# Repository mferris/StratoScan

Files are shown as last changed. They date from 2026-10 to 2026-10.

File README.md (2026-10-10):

<p align="center">
  <picture>
    <source media="(prefers-color-scheme: dark)" srcset="assets/brand/logo-on-dark.svg">
    StratoScan
  </picture>
</p>

# StratoScan

*Formerly Radome, and before that FlightRadar.*

A live ADS-B flight radar on a round display, built on a
Raspberry Pi and a cheap SDR dongle — no subscription and no API keys. The
radar needs nothing but its own receiver and a browser; an optional iPhone
app brings it to your pocket.

StratoScan running on the physical kiosk display

<sub>Centred on RDU airport. Map: OpenFreeMap © OpenMapTiles, data © [OpenStreetMap contributors](https://www.openstreetmap.org/copyright).</sub>

## Status

*As of 2026-10-03.* One unit (RDU) runs around the clock on release
`2026.10.02.1`. The plan is in [docs/ROADMAP.md](docs/ROADMAP.md), tracked
as [issues](https://github.com/mferris/StratoScan/issues), and the parts it still
needs are in the [shopping list](docs/SHOPPING.md).

| Area | State |
|---|---|
| The radar (kiosk) | Running unattended; updates itself from signed releases. One labelled aircraft feed on the unit for every screen (`/api/aircraft`); drawing cost halved |
| Phase 4 extras | Done: rewind, notable aircraft, empty-sky screen, spoken announcements, year in review, opt-in FlightAware feeding |
| Relay (push, fleets, health) | Live on Cloudflare Workers. Fleets: groups of radars with their own administrators, who see health and visit counts, never locations |
| iPhone and iPad app | Working on a real iPhone: QR pairing, push alerts (about the radar, where you are, or both, including aircraft approaching *you*), widgets, Live Activity (also on CarPlay), home/away switching, the network's aircraft, zoom, a compass, Sky view with tracks, the logbook, weather, colour themes, radar names. Setting up a new radar from the app, one QR code to paired (simulator-tested). A no-radar mode and an iPad layout (simulator-tested) |
| Apple Watch app | Built (glance radar, complications, Smart Stack); waiting for TestFlight to reach a real Watch |
| Security review | Full scan done 2026-09-28; every finding fixed and verified on the running unit |
| Factory SD image | Builds and passes its checks in CI; not yet test-flashed or published |
| Built, rolling out to the unit | Visitor counts for the public page (counts, not tracking), fleets on the radar's setup page, setting up from the app; the kiosk's switch to the core feed |
| Cases | Retro and Kitten: heat-set insert posts, a twin antenna mount (1090 and 978 MHz, or external antennas), cleaner speaker grilles |
| Next up | Factory image test, the Watch on a real wrist, hardware v2 (light sensor, bezel), a second receiver for 978 MHz |

## What it does

Point an RTL-SDR dongle and a small antenna at the sky, and StratoScan turns
whatever ADS-B traffic it hears into a live circular radar display: bearing,
range, altitude, speed, heading, airline, aircraft type, route, and (when
available) a real photo of the airframe. It's designed to run unattended,
full-screen, on a small round touch panel — on a wall, or in the printed desk
cradle — but it's also just a web page, so it runs fine in a normal browser
too.

- **Live tracking** — polls a local [`readsb`](https://github.com/wiedehopf/readsb)
  instance every second; altitude-coded blips, smooth interpolation between
  polls, a "NO SIGNAL" banner on connection loss
- **Touch** — drag the picture anywhere; zoom with a pinch, the + and − buttons
  beside the dial, or a wheel, double-click or the + − 0 keys on a laptop,
  from about 2 nm across the dial to the whole world; the lock beside them keeps
  a view, and FOLLOW on an aircraft's details keeps it in the middle, zoomed in.
  Beyond the ring, where the antenna's picture ends, the network's aircraft
  appear round the middle of the view: adsb.lol serves 250 nm discs, so a
  wide view is a grid of up to nine of them, about 530 nm round the middle,
  asked a second apart (the radar asks, so a visitor's browser still talks
  only to the radar; the phone app does the same for itself); the map
  follows, the sweep turns about the radar wherever it is, and after 45
  seconds without a touch the view comes home by itself. The antenna's
  picture ends at its ring, and the display says so when you look past it
- **Airline & route lookup** — badges each flight with its airline and shows
  its city-pair route where one's known, including multi-stop regional
  rotations
- **Aircraft type & photo** — human-readable type names ("Bombardier Regional
  Jet CRJ-900") and a real photo when one exists, falling back to a
  representative photo of the type
- **Background map** — real terrain, roads, and runway outlines (cached once
  fetched, so a restart doesn't wait on a fresh query), darkened and centered
  on the receiver, with an always-on live weather radar overlay and an
  optional satellite lightning-strike overlay
- **Approach visualization** — a real density heatmap of your home airport,
  built from actually observed landings over time rather than a canned
  flight-path overlay — busier stretches of the corridor read as more
  visually distinct than lightly-used ones, and it keeps sharpening the
  longer the receiver runs
- **Altitude-scaled blips** — a blip grows with altitude, from 0.68x on the
  ground to 1.30x at cruise, so height reads at a glance alongside the
  existing altitude colour. Deliberately not perspective: a higher aircraft
  is further away and would be smaller if this were about distance
- **Sighting counts** — every aircraft tracks how many distinct times this
  receiver has picked it up, and how many of those came within the
  nearby-alert radius; shown as a "SEEN ×N" badge once it's more than one,
  and as fields in the detail panel always
- **Registered-owner lookup** — for aircraft confirmed private (a real
  callsign, just not an airline one), the detail panel shows who the plane
  is registered to, pulled from public aircraft-registry data
- **Nearby-aircraft alert** — auto-pops flight details (with a chime) for
  anything passing within 2 miles of the receiver
- **Lightning proximity alert** — a chime + banner when a satellite-observed
  strike is detected within 15nm of the receiver, independent of the map's
  lightning overlay toggle
- **Rare aircraft alert** — a chime and an auto-popped panel for something
  worth walking outside for: an airframe on a military/government ICAO
  address, or an unusual type (747, A380, C-17, warbirds). Once the receiver
  has met enough traffic to know what normal looks like locally, it also
  flags aircraft it has never seen before
- **Emergency squawk alert** — an unmistakable alert (distinct chime + a red
  auto-popped panel) for 7500 (hijack), 7600 (radio failure), or 7700
  (general emergency)
- **Landing/takeoff highlight** — a bright green ring around the blip and
  label of anything currently landing or departing at your home airport, plus
  an optional quiet chime
- **Volume, mute, and a choice of alert sound** — every chime above goes
  through one master gain, adjustable up to 300% (with a limiter, so louder
  never means distorted) plus mute, and can play the original synth tones or
  real CC0-licensed recordings: cat sounds for a kitten-cased unit, or a real
  airline cabin chime for anyone — see `sounds/*/CREDITS.md` for what was
  recorded and how
- **Night dimming** — the display darkens between sunset and sunrise,
  computed from the receiver's own coordinates so it tracks the seasons
  without any configuration; alerts can optionally undim it
- **Screensaver** — the panel genuinely powers off after a configurable idle
  period (see [`deploy/`](deploy/)) and wakes on touch, or on an alert if
  you've enabled that
- **Settings menu** — a gear icon opens a menu grouped into short screens
  (Alerts, Map overlays, Display, Statistics, Phone & Watch, Device setup) rather than one
  long list; every setting is one tap from the top, and the panel scrolls by
  dragging anywhere on it. Choices persist per-device
- **Configurable home airport** — 433 continental-US airports are bundled, so
  a unit can be moved or given away and re-pointed at a different field. The
  landing highlight, approach heatmap and ATC link all follow it
- **Set up entirely from the touchscreen** — WiFi (with an on-screen
  keyboard), receiver location, home airport, remote access and a factory
  reset, all without a phone or a shell. This is also the recovery path if
  the admin password is ever forgotten
- **First-run provisioning for a device you did not configure** — a unit with
  no known network raises its own `StratoScan-Setup` WiFi and displays what
  to join, what address to open and a claim code. A captive portal makes the
  setup page open automatically on a phone
- **Connectivity status** — a pill at the bottom of the display says whether
  the radar is actually working: online, on a network that is not reaching
  the internet, running its own setup WiFi, or receiving no aircraft data.
  On the device it reports what NetworkManager concludes about the
  connection; viewed remotely it falls back to whether data is still flowing
- **Restart from the screen** — a Restart row under Device setup, so a stuck
  unit does not need someone to find and pull the plug
- **Frozen-display watchdog** — the radar reports each painted frame to a
  local endpoint, and the device restarts the kiosk if the panel is powered
  on but nothing has been drawn for two and a half minutes. Chromium can
  lose its GPU context and stop painting while the page stays alive by every
  other measure, which otherwise leaves a stale radar on screen until
  somebody walks up to it. A blanked screen is not a fault: the watchdog
  checks the panel's real power state first
- **Statistics** — a Settings section that reads the accumulated flight
  history back: how many distinct aircraft have been heard and how many
  separate passes they made, how many came within two miles, and how much
  of it the antenna heard versus only saw through the network comparison.
  Broken down by operator (commercial / private / military — military
  recognised from the address block, so a military aircraft flying a
  civil-looking callsign still counts) and by airframe (heavy jets, jets,
  propeller, helicopters), using the same type database that decides each
  blip's shape. Plus all-time records — farthest contact, closest approach,
  highest, fastest — the busiest hour of the day and the busiest day of the
  week, and the most frequent visitors. The receiver scorecard lives here too
- **Network comparison** (on by default, and switchable off) — outlines the aircraft a public
  ADS-B network can see in your ring that your antenna did not hear, and
  keeps a scorecard of how you compare: overall coverage, which altitude
  bands and which bearings you are blind in, and position freshness against
  the network's. They are tracked, not just plotted: each keeps its identity
  between polls, is dead-reckoned forward from its last fix, and draws a
  dashed trail. Tap one to see what the network knows about it, clearly
  marked as reported rather than received. Measured here, the receiver was hearing 44% of the traffic
  in range, and 8 of the 9 it missed were below 4,000ft — the signature of a
  blocked horizon rather than a deaf receiver
- **Touch detail panel** — tap any aircraft for registration, squawk, vertical
  rate, and more
- **"What was that?"** — a rewind button lists the closest passes of the last
  hour and draws the chosen aircraft's track back onto the radar
- **Notable aircraft** — air ambulances, police, military and historic
  aircraft are labelled from [plane-alert-db](https://github.com/sdr-enthusiasts/plane-alert-db),
  refreshed weekly on each unit. Labels are neutral, and private owners'
  names are never shown
- **Empty-sky screen** — after 30 seconds with nothing overhead, a clock,
  the current weather and today's tally
- **Spoken announcements** (off by default) — a local
  [Piper](https://github.com/OHF-voice/piper1-gpl) voice names what is
  passing, generated on the unit with no cloud speech service
- **Year in review** — per-year counts of what the receiver heard
- **FlightAware feeding** (opt-in) — a setup-page card installs PiAware to
  share this receiver's data with FlightAware; it says plainly that the
  antenna's exact location is shared

### The iPhone app

A native SwiftUI app and widget ([`ios/`](ios/)), paired with a radar by
scanning a QR code on its screen:

- **The same radar in your pocket** — live aircraft, tap for details, and
  a label mode that keeps the map readable on a small screen
- **Alerts wherever you are** — emergency squawks, notable aircraft, low
  aircraft overhead and helicopters, pushed through the relay. Choose which
  kinds you want
- **Live Activity** (opt-in) — when the radar predicts a close pass (within
  2 miles in the next 3 minutes), a countdown appears on the lock screen and
  in the Dynamic Island, and closes itself after the pass
- **Home-screen and lock-screen widget** — how many aircraft are overhead and
  the nearest few; a radar widget for StandBy
- **Every aircraft, not just the ones the antenna hears** — the aircraft a
  public network (adsb.lol) reports are drawn half-filled with an outline,
  with a "not heard" count; one switch covers everything the network adds
- **The whole screen, anywhere** — the map fills the screen, with the radar's
  ring a line on it. Pinch from about a mile out to a continent, drag
  anywhere in the world: inside the ring the aircraft are your radar's,
  beyond it the network's around wherever you look. Away from your radar
  the view centres on you by itself. Follow an aircraft, or centre on yourself
- **Trails** — where each aircraft has been, fading with age, as on the radar
- **Airline marks** — an airline's logo beside its name on labels, in the
  details and on its alerts, so a commercial flight reads at a glance (fetched
  from the airline's own site when first seen; none ships in the app)
- **Alerts that read** — "Boeing 737-800 · Raleigh → Boston · Delta · 1,200 ft
  · 2 mi NE", the callsign last; tap one and the app opens on that aircraft
- **Compass** — turn and the needle points at an aircraft, with which way it's
  coming from and going
- **Sky view** — hold the phone up and each aircraft's label sits where it is
  in the sky; tap one for its details. Away from home it shows the
  aircraft around you (with the public network on; see [privacy](docs/privacy.md))
- **Logbook** — what your radar has seen: today, all-time totals, records
  (farthest, closest, highest, fastest), what flies over, when, and the
  regulars
- **Sky view tracks and Find in the sky** — each aircraft's path drawn
  across the sky; from any aircraft on the radar, a big arrow guides you to
  it in the camera view
- **Approaching you** (opt-in) — alerts for aircraft about to pass over
  where *you* are, not just the radar; your location is end-to-end
  encrypted to your own radar
- **Weather and themes** — rain, storms and lightning on the map, and the
  radar's four colour themes (Daylight by default)
- **iPad** — a big radar with details alongside, and a wall mode that dims
  at night
- **No radar yet?** — see live aircraft around you from the public
  adsb.lol network, or play the demo
- **Home and away** — on your WiFi the app talks to the radar directly; away
  from home it switches to the radar's public HTTPS page by itself. The away
  address is learned from the radar
- **Demo mode** — a few minutes of real traffic recorded near RDU, so the
  app can be tried without a radar

## How it works

```
[Antenna] → [RTL-SDR dongle] → [readsb] → aircraft.json (local)
[978 MHz antenna] → [second radio] → [dump978] ─┘  (US units; UAT aircraft join the same list)
                                                 │
                                                 ▼
                                   [StratoScan: fetch + render]
                                                 │
                                                 ▼
                              [Chromium kiosk, full-screen] → [round display]

 Optional, for the phone app:

 [events.py on the unit] ──signed──▶ [relay: Cloudflare Worker + D1] ──APNs──▶ [iPhone]
        (what's worth an alert)        (pairing, push, fleet health)     (alerts, Live Activity)
```

The **relay** ([`relay/`](relay/)) is the project's one server. Units send it
signed events and opt-in health reports; it pairs phones with units and holds
Apple's push key, so no unit ever carries a secret that can act for the whole
fleet; and it is the one cache through which reporting radars get the public
network's aircraft, routes and owners (see *Data sources*). The radar never
depends on it: a unit that cannot reach the relay works exactly as before.
What it stores, and for how long, is in [relay/README.md](relay/README.md).

`readsb` decodes raw ADS-B signals and writes `aircraft.json` to disk.
`index.html` is a single self-contained page — plain HTML/CSS/JS, Canvas for
the radar itself, [MapLibre GL JS](https://maplibre.org/) for the background
map — that polls that file and renders everything. No build step, no
framework, no server-side code beyond a couple of tiny same-origin proxies
(see [`deploy/`](deploy/)) for things browsers can't do directly, like
setting a custom User-Agent.

## Getting started

**Hardware and receiver setup** (Pi, RTL-SDR dongle, antenna, `readsb`
installation) is covered in [`docs/project-spec.md`](docs/project-spec.md),
including a suggested two-wave purchase plan so you can confirm reception
before buying a display.

One thing worth doing before you chase any reception problem: install
[`deploy/blacklist-rtlsdr.conf`](deploy/blacklist-rtlsdr.conf) to
`/etc/modprobe.d/`. The RTL2832U is sold as a TV tuner, so without it the
kernel's DVB-T driver claims the dongle on every plug and fights readsb for
it, producing `error -71` and constant disconnects.

**Running the web app locally**, against a receiver on your network:

```bash
python3 dev-server.py
```

Then open `http://localhost:8000/index.html`. `dev-server.py` proxies
`/tar1090/*` requests to your receiver so the page can be tested with the
exact same relative paths it uses once deployed — edit `PI_HOST` at the top
of the file to point at your own receiver. It's dev-only and isn't part of
the deployed app.

**Deploying as a kiosk**: `index.html` is a static file — copy it to your
receiver's web server docroot (same origin as `readsb`'s own web UI, to avoid
CORS). [`deploy/`](deploy/) has a systemd unit for launching Chromium in
kiosk mode on boot, plus small same-origin services: aircraft photos, the
shared approach-track store, the shared sighting-count store, the display-wake
endpoint, the optional network-comparison proxy, and (only relevant if you
expose the page to the public internet,
e.g. via Tailscale Funnel) a filtering gateway that rounds the receiver's
exact coordinates before they leave your network — see
[Security](#security) below.

**Device setup (optional)**: everything above works on a receiver you
configured yourself. If you want a unit someone *else* can set up — moved to a
new house, or given away — install the setup server:

```bash
sudo sh deploy/install-setup-server.sh
```

That adds a web setup page at `http://<device>/setup`, the same screens on the
radar's own touchscreen, and the pieces that make a device with no network
recoverable. The installer refuses to finish unless it can prove the public
gateway is refusing `/setup`, since that page accepts a WiFi password and a
Tailscale auth key.

How a fresh unit behaves:

1. It finds no known WiFi, so after ~45s it raises `StratoScan-Setup`
2. Its screen shows that network's name and password, the address to open,
   and an 8-character claim code
3. A phone joining that network gets the setup page automatically, via the
   captive portal
4. WiFi, receiver location, home airport and an admin password are set; the
   setup screen disappears

The same things can be done on the touchscreen instead, which is the only
route if the admin password is ever forgotten. **Erase everything** clears the
WiFi, the Tailscale identity, the password, the coordinates *and* the
accumulated flight history and approach heatmap — the last two are a record of
what flew over the previous owner's house — then raises the hotspot so the
next person can claim it.

Two services run as `systemctl --user` rather than system units (the
screensaver and display-wake endpoint) because they need the graphical
session's `WAYLAND_DISPLAY`. The `stratoscan-netwatchdog` service (its own two-minute loop) rolls back any
unconfirmed network change at boot and raises the hotspot when there is no
usable connection — so a mistyped WiFi password reverts itself rather than
stranding the device.

**The 4am restart, and why it is a workaround.** Chromium on this platform
leaks unlinked `/dev/shm` mappings at roughly 200–300 MB/h of daytime
rendering. Left alone it fills the 4GB tmpfs in five to twelve hours, GPU
allocations start failing with `TransferBuffer::Initialize() failed`, and the
panel freezes on a stale frame — twice in one 34-hour stretch here.
`stratoscan-kiosk-restart.timer` restarts the kiosk at 04:00, when the panel
is already blanked and the sky is empty, returning `/dev/shm` from ~2GB to
~200MB. The frozen-display watchdog in `wake-listener.py` stays as the
backstop.

A second timer, `stratoscan-shmguard`, closes the gap the daily restart
leaves: it samples every five minutes and acts on the measurement rather than
the clock. **It reloads the page before it restarts the browser.** Tearing
down the document releases a third to a half of the accumulated shared memory
(151MB → 72MB and 124MB → 79MB, measured) without killing Chromium — no black
screen, no risk of coming back windowed — and the restart is kept as the
escalation for when a reload is not enough. Two marks, because a restart is only free when nobody is
looking — at **900MB it restarts only while the panel is blanked**, so most
restarts happen invisibly, and at **1500MB it restarts regardless**, which is
the one that actually prevents the freeze. It measures both `/dev/shm` usage
and the sum of Chromium's renderer shm mappings and acts on whichever is
larger, because the two diverge: `/etc/chromium.d/dev-shm` adds
`--disable-dev-shm-usage` when `/dev/shm` has under 3.8GB free at launch, so
after one bad day Chromium moves its backing to `/tmp` and the `df` number
stops tracking the leak. Restarts are rate-limited to one per 30 minutes — if
something other than the leak fills the arena, a guard that restarts forever
is worse than the freeze it was written to prevent. The 04:00 restart runs
through the same script (with `SHMGUARD_FORCE=1`) so both share that one rate
limit.

**Chromium must not be restarted while the panel is blanked.** It comes up
windowed — tab bar, address bar, desktop wallpaper — even with `--kiosk` on
its command line, because it cannot take an output that is off and does not
retry when the output returns. Reproduced both ways on the device: panel off
gives a windowed browser every time, panel on gives fullscreen every time.
This mattered most for the 04:00 restart, which by design runs when the
screensaver has blanked the panel, so it would have left the display windowed
every morning. The guard now wakes the panel, restarts, waits for Chromium to
take the display, and only then puts the panel back as it found it.

It also **repairs a windowed browser however it happens**, not just when the
guard itself caused it — that is the failure a recipient would simply live
with. Every run it grabs the screen and measures the top-left corner:
fullscreen reads 0 on this panel, windowed reads 232, so the threshold sits
at 60 with a wide margin. Verified by breaking it deliberately and watching
the guard put it back.

**A reload cannot be delivered while the panel is blanked**, and that took
two wrong diagnoses to see. The instruction rides the paint heartbeat, and
`reportPainted()` is driven by `requestAnimationFrame` — with nothing being
composited there are no frames, so the page never posts `/wake/alive` and
never collects the flag. Six attempts told the story cleanly: five with the
panel off freed 0MB each, with the listener logging no delivery at all, while
the one with the panel on freed **597MB of 700MB**.

The apparent pattern before that — "reloads stop working above ~600MB" — was
an artifact: every failed attempt happened to be panel-off. Memory level was
never the variable.

So the guard reloads only when the panel is on (at 700MB), and when the panel
is off it restarts outright at 600MB, which is invisible precisely because
the panel is off. A restart at 1400MB remains the backstop with the panel on.

The reload is requested without any control channel of its own. The page
already POSTs `/wake/alive` every 20 seconds as the frozen-display heartbeat;
the guard drops a file in `$XDG_RUNTIME_DIR`, and the listener answers that
next heartbeat with `{"reload":1}` instead of `204`. So there is no debug
port, no key-injection helper and no new listener: only a local process
running as the kiosk user can ask for a reload. Nothing is lost by reloading —
sightings, statistics and the approach heatmap all live in the server-side
stores — beyond trails and ghost tracks, which rebuild within a sweep.

It is a workaround and not a fix, because the cause is not in this codebase:
a blank page leaks the same way, the mappings are invisible to Chromium's own
`memory-infra` accounting, and a critical memory-pressure signal reclaims
none of them. Removing the map, the weather overlays and the canvas render
loop each failed to stop it. One caveat worth keeping in view: the observed
time-to-freeze was as short as 5.2 hours, so a single daily restart is not
guaranteed to cover a long, busy day on its own.

**The enclosure**: [`enclosure/`](enclosure/) has two printable cases for the
same hardware — the original ship's-instrument look, and one shaped like a
sitting cat with the round display as its face, printed in two colours. Both are parametric OpenSCAD,
everything deriving from the measured values at the top of each file. Each
folder's README covers how to export the parts, the interference checks, and
the dimensional mistakes that are easy to repeat.

**iOS app**: `ios/` is an [XcodeGen](https://github.com/yonaskolb/XcodeGen)
project (app plus widget extension, iOS 17.2 or later). Run `xcodegen generate`
inside `ios/` if you change `project.yml`, then open `StratoScan.xcodeproj` in
Xcode. To build your own, set your signing team, bundle id and App Group in
`project.yml`. On the radar, open Settings › Phone & Watch to show a pairing
code, then scan it from the app. Push alerts need your own relay and an APNs
key (see [relay/README.md](relay/README.md)); without them the app still
shows the live radar.

**Relay**: a Cloudflare Worker on the free plan. From `relay/`:
`npm test`, then `npm run db:init && npx wrangler deploy`. Apple's `.p8` key
goes in with `wrangler secret put APNS_KEY`, never into the repo.

## Project structure

```
index.html      the whole web app — single file, no build step
dev-server.py   local-only dev proxy (not deployed)
deploy/         systemd units, same-origin services, events, pairing and the setup server
docs/           roadmap, spec, privacy policy, gifting guide, screenshots
enclosure/      parametric OpenSCAD source for the printed cases (two designs)
tests/          regression tests for the security-critical paths
vendor/         vendored MapLibre GL JS (self-hosted, no CDN dependency)
sounds/         CC0 audio for the alert sound themes (see sounds/*/CREDITS.md)
ios/            native SwiftUI app, widget and Live Activity
relay/          Cloudflare Worker: pairing, push, fleet health
scripts/        signed release script
image/          factory SD-card image build (run in CI)
```

See [CHANGELOG.md](CHANGELOG.md) for release notes and
[HANDOFF.md](HANDOFF.md) for the detailed development history.

## Data sources

StratoScan leans entirely on free, no-key-required public data, same as
[tar1090](https://github.com/wiedehopf/tar1090) (GPL-2.0-or-later; it inspired
several of these choices, but no code is shared):

- **[readsb](https://github.com/wiedehopf/readsb)** — ADS-B decoding
- **[dump978](https://github.com/flightaware/dump978)** — 978 MHz (UAT) decoding, for the FlyCatcher's second radio; its aircraft are merged into readsb's
- **[MapLibre GL JS](https://maplibre.org/)** (BSD-3-Clause, vendored under [`vendor/`](vendor/) — self-hosted, no CDN dependency) + **[OpenFreeMap](https://openfreemap.org/)** — background map tiles/style
- **[OpenStreetMap](https://www.openstreetmap.org/) via Overpass** — real runway/taxiway geometry
- **[adsb.im](https://adsb.im/)** — route (city-pair) lookups
- **[RainViewer](https://www.rainviewer.com/)** — live weather radar overlay (their API is free for personal/educational use only)
- **[planespotters.net](https://www.planespotters.net/)** — aircraft photos
- **[Wikimedia Commons](https://commons.wikimedia.org/)** — representative type photos when no tail-specific one exists, credited with author and license
- **[adsbdb.com](https://www.adsbdb.com/)** — registered-owner lookups for confirmed-private aircraft
- **[SSEC RealEarth](https://realearth.ssec.wisc.edu/)** (UW-Madison) — satellite-observed lightning strike density (GOES-East GLM)
- **[Protomaps](https://protomaps.com)** OpenStreetMap builds (© OpenStreetMap contributors, ODbL) — the per-unit offline fallback map built by [`deploy/offline-map.py`](deploy/offline-map.py)
- **[OurAirports](https://ourairports.com/data/)** (public domain) — the bundled airport table in [`deploy/airports.json`](deploy/airports.json)
- **[plane-alert-db](https://github.com/sdr-enthusiasts/plane-alert-db)** (ODbL) — the notable-aircraft list
- **[tar1090-db](https://github.com/wiedehopf/tar1090-db)** — aircraft type and registration from the ICAO address, read from the unit's own tar1090 install
- **[Open-Meteo](https://open-meteo.com/)** — current weather on the empty-sky screen (free for non-commercial use)
- **[adsb.lol](https://adsb.lol/)** — community-run ADS-B aggregation, used only by the network comparison, which can be switched off. Queried at most once every 15s no matter how many people are viewing, with coordinates rounded to ~1.1km

**One cache for every radar.** A radar that reports to the relay (health
reports on) gets the network's aircraft round its view, flight routes and
registered owners *through the relay* ([`relay/src/netcache.js`](relay/src/netcache.js)),
which asks adsb.lol, adsb.im and adsbdb once and serves every radar that
wants the same thing, so those volunteer-run services' load no longer grows
with the fleet. The aircraft come as 250 nm discs on a fixed world lattice
(two radars near each other ask for the same disc), kept ten seconds; routes
six hours; owners a week. The relay passes adsb.lol's answers through
untouched, paces its own questions, and passes a refusal on rather than
retrying. A radar whose relay is unreachable, or that has reports off, asks
the services itself as before.

Every obligation these carry, and how each is met, is in
[THIRD_PARTY_NOTICES.md](THIRD_PARTY_NOTICES.md). Please respect each
service's own terms if you build on this; RainViewer in particular is not
for commercial use.

## Security

If you expose this beyond your own LAN (e.g. a Tailscale Funnel URL, like the
live deployment this repo was built against), a few things are worth knowing
before you do:

- **The receiver's exact coordinates are not something you want publicly
  reachable.** `readsb`'s own `receiver.json` endpoint returns
  survey-precision lat/lon, and by default that's reachable by anyone who
  finds the URL. [`deploy/funnel-gateway.py`](deploy/funnel-gateway.py) sits
  in front of whatever you expose publicly and rounds those coordinates to
  ~0.7 mile precision for public traffic only — your LAN/kiosk always sees
  the exact value, which `readsb` itself needs for its own signal-range math.
  Point your public tunnel at this gateway instead of at `readsb`/lighttpd
  directly. The gateway also strips each aircraft's distance and bearing
  *from the antenna* (`r_dst`, `r_dir`) out of the public `aircraft.json`:
  with two or three aircraft positions, those fields pinpoint the receiver, which undid the rounding entirely.
- **readsb writes more than the page needs, and the rest locates the
  antenna.** `aircraft.binCraft.zst`, the binary feed tar1090 prefers,
  carries the receiver's position *unrounded* in its header — found on the
  live tunnel on 2026-10-04, next to a rounded `receiver.json` — and
  `outline.json` (the range outline, drawn around the antenna), the
  `history_*.json` files and `chunks/` are past snapshots. Under
  `/tar1090/data/`, `/tar1090/chunks/` and `/tar1090/globe_history/` the
  gateway now serves only the two files it rewrites and two counters-only
  ones, and the public `receiver.json` tells tar1090 not to ask for the rest.
  [`tests/test_funnel_gateway_tar1090.py`](tests/test_funnel_gateway_tar1090.py)
  pins it. The lesson, twice over now: anything readsb writes is a candidate
  for leaking the position, so the public rule is an allowlist, not a list
  of known offenders.
- **External data (route text, photo credits, aircraft type) is escaped
  before it touches the DOM.** Some of it — a photographer's display name on
  planespotters.net, for instance — is third-party user-submitted content
  this app doesn't control.
- **The shared same-origin stores are read-only for public traffic.**
  `deploy/approach-store.py` and `deploy/sighting-store.py` have no
  authentication of their own, which was fine while only the LAN could reach
  them. Once the page is exposed through a tunnel they become writable by
  anyone holding the URL — confirmed by injecting a fake sighting through it
  — so the gateway now refuses any non-GET to `/sightings` and `/approaches`
  from public traffic (`READ_ONLY_PUBLIC_PATHS`). Reads stay open, because
  public viewers need them; the kiosk and LAN still write normally. They also
  cap request body size and validate input shape.
- **Privileged endpoints are refused for public traffic**, and the check
  normalises the path first. `/wake` (which powers the kiosk's panel on) and
  `/setup` are listed in `LOCAL_ONLY_PATHS` in
  [`deploy/funnel-gateway.py`](deploy/funnel-gateway.py) and 404 for anything
  arriving through the tunnel. The normalising matters: an earlier version
  compared the raw path, and because lighttpd percent-decodes and collapses
  traversal before routing, `/./wake`, `/x/../wake` and `/%77ake` all reached
  the endpoint anyway. [`tests/test_funnel_gateway_paths.py`](tests/test_funnel_gateway_paths.py)
  pins the behaviour — run it after touching that filter.
- **The setup server is split across a privilege boundary.** The HTTP tier
  runs unprivileged and can only ask a small root helper
  ([`deploy/setupd.py`](deploy/setupd.py)) to perform a closed list of verbs
  over a unix socket — there is no "run nmcli" passthrough, so compromising
  the HTTP parser does not yield arbitrary root. The root helper re-validates
  every parameter rather than trusting the caller, uses no shell, and keeps
  secrets out of argv (where any local user could read them from `/proc`).
  [`tests/test_setupd_validation.py`](tests/test_setupd_validation.py) pins
  the validation table and the `/etc/default/readsb` rewriter, which is a
  root-sourced shell file and therefore a command-execution sink.
- **On-device setup deliberately needs no password**, and the endpoint behind
  it is bound to loopback and not proxied, so reaching it means already being
  on the device. That is the same physical assumption every appliance makes,
  and it has to be true: it is the only way back in for someone who has
  forgotten the admin password. The web route, which *is* reachable across
  the LAN, still requires it.
- **Erasing a unit removes the accumulated data too.** The flight history
  and approach heatmap are a record of which aircraft passed over the
  previous owner's house — and the history now carries each aircraft's
  callsign and classification alongside its counts, which makes it more
  identifying than a bare tally, not less — so a full reset clears them
  along with the credentials and coordinates. A settings-only reset keeps them, and keeps
  the network, so it is safe to run remotely.
- **The network comparison is on by default and sends only a rounded
  position.** It can be switched off in Settings, and switching it off stops
  the device contacting adsb.lol (or the relay's cache of it) at all. The
  device-side proxy makes no request of its own — it only fetches when a
  page with the setting on asks it to — and it queries with coordinates
  rounded to 2dp, the same precision the public gateway already exposes
  (the view beyond the ring, through the relay, asks for fixed world discs,
  which say even less). Asking a stranger "what is
  near me" with survey-precision coordinates would undo the rounding the
  rest of this project does deliberately. `/network` is readable publicly
  but refuses writes, so nobody holding the URL can drive traffic at a
  community-run service on this device's behalf.
- **The display-wake endpoint answers only the device itself.** lighttpd
  refuses `/wake` from anything but `127.0.0.1` and `::1`, so a LAN device
  cannot power the panel on or fake the frozen-display heartbeat.
- **SSH is key-only.** The installer drops
  [`deploy/10-stratoscan-ssh.conf`](deploy/10-stratoscan-ssh.conf) into
  `sshd_config.d`: no passwords, no root login, no X11 forwarding. It
  validates the config with `sshd -t` before reloading.
- **Downloaded code is pinned.** The Piper speech engine installs with
  `pip --require-hashes` from
  [`deploy/tts-requirements.txt`](deploy/tts-requirements.txt), and its voice
  model is checked against [`deploy/tts-voice.sha256`](deploy/tts-voice.sha256).
- **Units and phones prove who they are to the relay.** Every unit request is
  signed with the unit's own Ed25519 key, and every phone request with a key
  generated on the phone. Pairing takes a one-time code shown on the radar's
  screen, which expires in 10 minutes or after five wrong guesses. Only a
  hash of it is stored.
- **No secrets in the repository or on units.** The radar's data sources are
  free and keyless (see [Data sources](#data-sources) above). The one secret
  the project has, Apple's push key, lives only in the relay as a Cloudflare
  secret.

## License

StratoScan™ and the StratoScan logo are trademarks of Michael Ferris.
© 2026 Michael Ferris.

The code is MIT — see [LICENSE](LICENSE). The StratoScan name, logo and icons are not:
they identify the project, so a fork should use its own (see
[assets/brand/LICENSE](assets/brand/LICENSE)). Third-party components and data sources keep
their own licenses and terms; see [THIRD_PARTY_NOTICES.md](THIRD_PARTY_NOTICES.md).

## Setting one up somewhere else

The first build assumed the continental US in more places than was obvious,
and each one was a hard stop rather than a rough edge:

- **Coordinates were forced into the northern and western hemispheres.** The
  setup page and the touchscreen both "helpfully" made latitude positive and
  longitude negative, on the reasoning that a sign left off a US coordinate is
  unambiguous. It is — and it silently moved a receiver in the Netherlands
  (4.49°E) to 4.49°W, in the Atlantic, while making the entire southern
  hemisphere unreachable. `setupd` agreed, rejecting anything outside
  24–49.5°N and 66.5–125°W as "outside the continental US".
- **The airport list was 433 US airports.** Now 3,269 worldwide (large and
  medium fields with scheduled service, from OurAirports), so Schiphol and
  San Carlos are both a search away.
- **Time zone and WiFi region were baked into the image** as
  America/New_York and US, with no way to change either from setup. A unit
  abroad timestamped every sighting wrongly and ran its radio on the wrong
  channel set.
- **The lightning overlay is GOES-East**, which only sees the Americas.
  Outside that footprint every tile is a 404, so the setting now hides itself
  and says why rather than offering a toggle that cannot work.

**Location is entered as an address by default.** Nobody knows their
coordinates; everybody knows their address. The lookup runs on the *device*
rather than in the browser, because during first-time setup the phone is
joined to the device's own hotspot and has no route to the internet, while
the Pi was put on WiFi in the previous step — a browser-side lookup would
fail exactly when it is needed. The address reaches OpenStreetMap's
Nominatim and nothing else, the position it returns stays on the device, and
typing coordinates by hand remains one tap away for anyone who would rather
not send an address anywhere.

Picking the home airport sets the country, which seeds the time-zone step
with the one or two zones that country actually uses instead of all 485, and
sets the WiFi regulatory region to match. Both the phone page and the
touchscreen can complete setup on their own.

**The WiFi region only takes effect after a restart**, and both UIs say so.
Two things about `raspi-config nonint do_wifi_country` were found by running
it on the device rather than reading about it:

- **It exits non-zero on success.** Its NetworkManager and `wpa_cli` steps try
  to reach a session message bus, which does not exist when the call comes
  from a daemon, so it prints an error and returns 1 *after* writing the
  setting. Judging it by its exit code reports failure for a change that
  worked, so the result is judged by reading the value back instead.
- **The running regulatory domain does not change.** The Pi's Broadcom radio
  registers a custom regulatory table — `phy#0` reports `country 99` — so the
  driver overrides `iw reg set` and the global domain reads `98` until the
  next boot, when `cfg80211.ieee80211_regdom` on the kernel command line
  applies it for real.

The change is safe to make over WiFi: tested on a live link, the SSID, IP
address, connectivity, channel and an active SSH session were all unaffected
throughout.

Because it needs a restart, both surfaces offer one — but **only when the
region actually changed**. `set_wifi_country` reads the country before and
after and reports `changed`, so re-saving the same region never sends anyone
to power-cycle a working device. The prompt says the setting is stored, that
the radio still follows the old region until then, and that nothing else is
waiting on it, so leaving it until the next power-on is a legitimate choice
rather than an unfinished step.

## Updating a unit that has been given away

A gifted radar cannot be fixed by SSH, so it can update itself — carefully.

**Signed, or refused.** A release is accepted only if its manifest carries an
Ed25519 signature (`ssh-keygen -Y`) from the key in
`deploy/allowed_signers`, which is baked in before a unit ships. The private
half lives on the maintainer's machine and never touches a device, GitHub, or
CI. GitHub is delivery, not trust: a compromised account or token could
publish a release, it could not sign one. `ssh-keygen` rather than minisign or
gpg because it is already installed — no new dependency on a box nobody can
log into.

**Newer, or refused.** The device compares an integer serial, not a version
string. An old release stays correctly signed forever, so without this a unit
could be walked backwards onto a build whose bugs are already fixed.

**It undoes itself.** After installing, the display must paint a frame within
90 seconds or the previous files go back and the kiosk restarts again. This
reuses the heartbeat the frozen-display watchdog already depends on, so an
update that blanks the screen is caught by the thing already watching the
screen — with nobody in the room. Verified by signing and applying a build
that throws before rendering: it was staged, installed, failed to paint, and
rolled back, and the previous `index.html` came back byte-identical.

**It cannot install anywhere it likes.** Only an allowlisted set of
destinations is writable, which excludes `allowed_signers` itself — an update
must not be able to replace the key that vouches for it, or one bad release
owns the device forever.

Checking is a timer (twice a day, randomised). **Installing is a deliberate
act** from the settings screen or the setup page: a unit that silently
replaced its own software overnight would be a different thing to give
somebody. Neither surface ever claims "up to date" for a device that has
simply never looked.

The manifest carries each file's **executable bit** as well as its hash, and
only that bit — a manifest that could set arbitrary permissions on root-owned
files would be a much larger thing to sign off on than one that can say "this
is a program". It is there because the first real update installed a new
`ota.py` without its executable bit and broke its own updater; the services
survived only because their units run `python3 <script>` rather than exec'ing
it.

The paint check refuses to run at all if the heartbeat file is missing, rather
than rolling back every update. That, too, is from experience: the stamp
originally lived in `/run/stratoscan`, which is setupd's `RuntimeDirectory=`
— systemd recreates it root-owned whenever the root helper restarts, so the
kiosk user silently lost the ability to write it, and a perfectly good release
was reverted because nothing could record that the screen was painting. It now
lives in the kiosk user's own runtime directory.

To cut a release: `sh scripts/release.sh <version>`. It builds the bundle
from the commit's tree (never the working tree: a hotfix once shipped with
three unrelated changes that happened to be sitting in it), writes a manifest
of per-file hashes, signs it, **verifies its own output with the public key
the devices carry**, and only then publishes to GitHub Releases. It refuses a
dirty tree, a commit that is not on GitHub, and a serial that is not above
the last release's. `--commit <ref>` builds an older commit, which is how a
fix goes out without whatever else has landed since.

**A release reaches units in rings.** Each release carries a signed
`rollout.json` saying how far it may go: ring 0 is the maintainer's own
radar, 1 family, 2 early adopters, 3 everyone. A unit's ring is in
`/etc/stratoscan/ring` (the installer's `RING=`; a managed unit starts in
ring 1, a unit with no file is in ring 3), and the updater installs a newer
release only when the policy names it, is not paused, and covers the unit's
ring — otherwise the settings screen says the release is rolling out in
stages and has not reached this device yet. A new release starts at ring 0;
after a day on the canary, `sh scripts/release.sh rollout <version> --ring 1`
lets the next ring in (the script refuses to widen sooner unless told
`--force`), `--pause` stops the spread, and a unit that already has the
release keeps it: there is no downgrade, a fix is the next release. The
policy is signed in its own namespace, so a manifest can never pass as a
policy or a policy as a manifest, and a release with no policy reaches no
unit — a hand-made release cannot go everywhere by accident.

**Changed services are restarted.** A long-running service keeps its old code
until it restarts, and the updater originally restarted only the kiosk — so a
security fix to `funnel-gateway.py` was reported installed while the old
gateway kept running for hours. It now compares each file with the one it
replaces and restarts exactly the services whose code changed (and restarts
them again on a rollback). Like any change to `ota.py`, that behaviour starts
with the release *after* the one that installs it.

The serial is the commit count, so two releases cut from the same commit carry
the same serial and the second is refused as "not newer" — the script now
checks this against the last release before it builds anything.

## Built to run for ten years

Measured on the first unit and reviewed for a decade of unattended running at
busy sites (SFO, Schiphol) as well as quiet ones:

- **SD card wear.** The stores keep their data in memory and write at most
  every 10 minutes and on shutdown; they used to rewrite the whole file on
  every sighting (3.5 GB in 17 hours, ~100 GB/day at a busy site once full).
  Chromium's HTTP cache lives in RAM, and it keeps no shader cache on disk.
  Dirty pages are batched for two minutes before writeback. The history store evicts the aircraft
  seen *least recently*, so daily regulars survive a full store. Measured in
  steady state: 2.25 GB/day, about 8 TB over ten years, well under a 128 GB
  high-endurance card's rating.
- **Recovery without a person.** The hardware watchdog reboots a hung kernel;
  `kernel.panic=10` reboots a panicked one. `net-watchdog.py` also restarts
  `readsb` when its output goes stale and reboots after repeated failed
  restarts, and reboots when the frozen-display watchdog's browser restarts
  keep failing — never more than once every 6 hours, so a fault a reboot
  cannot fix degrades to a few reboots a day, not a loop.
- **A hung radio is power-cycled, not just rebooted.** The Pi 5 keeps USB
  power on through a reboot, so a wedged SDR stays wedged. Before rebooting,
  the watchdog cuts USB power with [uhubctl](https://github.com/mvp/uhubctl)
  for a few seconds and turns it back on (at most once every 30 minutes).
- **Security updates** via unattended-upgrades (Debian security and point
  releases, the Raspberry Pi archive, Tailscale), holding Chromium, the
  kernel and firmware — a bad unattended update to those strands a unit.
- **An offline map.** When the location is set or changed, the unit
  downloads its own area (2–7 MB) from [Protomaps](https://protomaps.com)'
  OpenStreetMap builds into `/offline-map/`, and the page falls back to it
  whenever OpenFreeMap can't be reached — so a dead tile service or a boot
  before WiFi is up shows a real map, not a blank disc.

These system-level pieces (unattended-upgrades, sysctl, unit files) are
installed by `deploy/install-setup-server.sh`, never by an update — re-run it
on any unit before it leaves the house. What remains is hardware: an RTC
battery (ML-2020, with `dtparam=rtc_bbat_vchg`) keeps the clock across power
cuts, and a high-endurance SD card or an NVMe drive is the better medium for
a decade.

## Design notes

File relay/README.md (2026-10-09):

# StratoScan relay

The one small server the project runs: a Cloudflare Worker with a D1
database. It receives **opt-in health reports** and **events** from units,
pairs phones with units by QR code, sends push alerts and Live Activities to
those phones through Apple (APNs), and shows the maintainer a fleet page. The design is
in [docs/ROADMAP.md](../docs/ROADMAP.md#architecture-the-relay).

**The radar never depends on it.** A unit that can't reach the relay, or has
reporting switched off, works exactly as before.

## What it stores

For each unit:
- its public key (which is its id);
- a name the maintainer gives it;
- first and last report times;
- its software version;
- its last ~30 days of health reports: uptime, receiver health, storage
  wear, temperature, clock battery, update state.

For each unit that sends **events** (roadmap 2.2; only once its owner
pairs a phone): the moments it decided a paired phone should hear about.
There are four kinds: emergency squawks, notable aircraft, low aircraft
overhead and helicopters. Each carries the aircraft's identity, type,
altitude, its distance from the unit rounded to half a nautical mile with
a compass direction, and its track (the direction it's travelling, which it
broadcasts itself). Events are kept for **48 hours** at most (500 per
unit), only long enough to deliver them. The fleet page shows how many
arrived, never what they were.

For **pairing** (roadmap 2.3): which phones are paired with which unit,
each phone's public key (its id) and the name it gave itself ("iPhone"),
and while a code is showing on a unit's screen, that code's SHA-256. The
code itself reaches the relay only when a phone presents it, is compared
and then discarded; it works once, and expires after 10 minutes or five
wrong guesses. A unit stops sending events when its last phone unpairs,
and the relay drops events from a unit with no phones.

For **push** (roadmap 2.1): each paired phone's APNs device token, whether
it is a development or App Store build, and which alert kinds it wants.
A token is only an address for Apple's push service. Apple tells the relay
when a token stops working, and the relay then forgets it. Each phone gets
at most 30 ordinary alerts an hour; emergencies always go through.

For **alerts about aircraft approaching a phone** (roadmap 2.7; only for
phones whose owner turns on "Approaching me"):
- each unit's X25519 "box" key, signed by the unit's own Ed25519 key;
- each such phone's latest location for each of its units, **as an opaque
  encrypted blob**. The phone seals it to that unit's box key, after
  checking the key's signature against the unit id it scanned at pairing,
  so the relay can neither read it nor substitute a key of its own. Kept 6
  hours at most, and deleted when the phone unpairs or turns the option
  off. The unit decrypts it and runs its approach prediction for that
  point; the approach event it sends back names the phone (it goes to that
  phone alone) and the aircraft, without distance or direction.

**No locations in the clear.** Reports or events carrying a latitude or
longitude field are rejected outright. No network addresses are stored either. An event
still says roughly where its unit is ("a helicopter passed within 2
miles"), which is why events are opt-in and kept so briefly.

For **the shared cache** (`src/netcache.js`, 2026-10-09): nothing per
unit. The relay keeps, in Cloudflare's per-data-centre cache, the public
network's aircraft in 250 nm discs on a fixed world lattice (10 seconds),
flight routes from adsb.im by callsign (6 hours; "no route" for 1 hour)
and registered owners from adsbdb by aircraft address (7 days). Entries
are keyed by the thing asked for, never by who asked; a reporting unit or
a paired phone may ask, and nothing else. A disc is fetched from adsb.lol
by the unit that first finds it missing (adsb.lol rate-limits Cloudflare's
shared addresses) and handed up for the others; routes and owners the
relay fetches itself.

## Fleets

A fleet is a group of radars with its own administrators (roadmap 1.13): for example, the radars one person has given to their family, or a club's radars.

**Making one** (the maintainer, on `/fleet` behind `FLEET_TOKEN`):
1. Use **Create fleet** to get an **invite code** and an **administrator link**. Each is shown **once**; the relay keeps only their SHA-256.
2. Send the invite code to radar owners. Send the link only to the administrator.
3. From the same section, **New invite code** replaces the code (the old one stops working), and **New administrator link** adds an administrator.

**Joining:** a radar's owner enters the invite code on the radar's setup page, under *Fleet*. The radar sends it, signed with its own key, to `POST /v1/unit/fleet`. It leaves with `POST /v1/unit/fleet/leave`, from the same card. A radar is in at most one fleet. Joining turns its health reports on, and leaving puts them back the way they were.

**Administrators:** opening the link sets an `HttpOnly`, `Secure`, `SameSite=Strict` cookie and redirects to `/f`, so the secret doesn't stay in the address bar. `/f` shows that fleet's radars only:
- name, software version, last report and health;
- the public page's views and visitors over the last 7 days.

It never shows a location (health reports carry none), phones or alerts. An administrator can remove a radar or replace the invite code.

**Storage:** three tables, `fleets`, `fleet_admins` and `fleet_members`, in `schema.sql`. On the live database they were created with `wrangler d1 execute --command`, because `--file` needs an API permission the maintainer's login doesn't have. An administrator's link can be replaced, by the administrator ("Replace my link" on their page) or by the maintainer: the old one stops working at once and says so when opened; `fleet_admins.replaced_hash` and `replaced` were added the same way on 2026-10-08.

## Security model

- Each unit signs every request with its own Ed25519 key, generated on the
  unit and never copied off it. No shared secret is baked into images.
- Requests are bound to their timestamp, method, path and body. The relay
  rejects anything more than 5 minutes off or replayed. Health reports may
  come at most every 10 minutes. Events are capped at 120 an hour per unit
  and 20 per request, and every field is validated and length-limited
  before it is stored.
- An unknown key registers on first contact. The number of units is capped,
  so this can't grow without bound.
- Phones sign the same way with their own Ed25519 key (CryptoKit on iOS),
  named in `X-FR-Phone`. A phone can only pair by presenting the code on a
  unit's screen, and can only unpair itself. A unit can list and remove its
  own phones.
- The fleet page requires HTTP Basic auth against the `FLEET_TOKEN` secret.
  With no secret set, the page doesn't exist at all. Its only form refuses
  cross-site posts.

## Deploy (once, by the maintainer)

```bash
cd relay
npm install
npx wrangler login                                  # opens a browser
npx wrangler d1 create stratoscan-relay             # copy the id into wrangler.toml
npm run db:init                                     # applies schema.sql
npx wrangler secret put FLEET_TOKEN                 # choose a long random password
npx wrangler secret put APNS_KEY < AuthKey_XXXX.p8  # the APNs auth key from developer.apple.com
                                                    # (key id, team id and app id go in wrangler.toml [vars])
npm run deploy                                      # serves the custom domain in wrangler.toml (and https://stratoscan-relay.<you>.workers.dev)
```

After a change to `schema.sql` (new tables only, never altered ones), run
`npm run db:init` again before `npm run deploy`. It is safe to repeat.

Then set `RELAY_URL` in `deploy/heartbeat.py` to that address and cut a
release; units that have opted in start reporting within a few minutes. The
fleet page is at `/fleet`.

The free Cloudflare plan covers this comfortably: one small request per unit
every 6 hours.

## Scale test

`node scale-test.mjs [radars] [phones per radar]` runs a simulated day for a
fleet against the real Worker code and SQL (the D1 stand-in from `test/`),
and prints requests, statements, rows and the worst status. Measured
2026-10-04: a radar with one phone sharing its location costs about 1,750
relay requests a day (1,440 of them location polls, every minute); one with
none sharing about 175. Five radars and fifteen phones: 8,835 requests and
19,205 D1 statements a day, every one answered 200. A hundred radars:
175,308 a day, which is past the Workers free plan's 100,000, so a fleet of
more than about 50 radars with phones sharing needs the $5 paid plan.

## Test

```bash
npm test
```

The tests run the Worker and its real SQL (Node's built-in SQLite behind a
D1 stand-in). They include a request signed by the Python unit client on a
real device, so the two sides can't silently drift apart.

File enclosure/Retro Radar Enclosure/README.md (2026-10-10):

# Retro radar enclosure

The 3D-printable case for the retro build, as a single parametric
OpenSCAD source. Everything is driven from the measured values at the top of
[`retro-enclosure.scad`](retro-enclosure.scad) — change those and
the rest follows.

## Parts

| part | what it is |
|---|---|
| `shell` | the body: Pi, dongle, wiring, speakers |
| `front_trim` | bezel in front of the glass, rabbeted so it seats flush |
| `retainer` | ring behind the glass; the glass rests on its front face |
| `stand` | desk cradle — two ring-arc arms on a plinth with two ridges all the way round, standing 4mm proud so the slicer supports their undersides (BambuStudio skipped the old 1mm strips and they printed rough) |
| `back_plate` | removable back — locating lip, both vent grilles, one USB-C pass-through, the antenna mount's bolt holes and cable hole |
| `antenna_mount` | bolt-on arm carrying the antenna socket (identical to the kitten's) |
| `antenna_mount_sma` | alternative mount: same flange, arm and counter-tilt, ending in a panel-mount SMA jack instead of a socket cut for one antenna's base |
| `antenna_mount_twin_8`, `antenna_mount_twin_11` | **the one to print for the FlyCatcher:** same flange and three bolts, ending in a crossbar with two SMA jacks 80 mm apart, for the 1090 and 978 MHz whips; counter-tilted so both stand vertical with their hinges straight. Two styles, for jumpers whose bulkhead body is an 8 mm hex or an 11 mm hex; two parts each, this body and the cover below (`antenna_mount_twin` is whichever `ant_twin_jack_af` names) |
| `antenna_mount_twin_cover_8`, `antenna_mount_twin_cover_11` | the 3 mm cover that closes the twin body's cable channel, on five M2 screws, with each side's frequency engraved in it (`twin_assembled` and `twin_assembled_11` show both parts on the plate, for pictures only) |
| `antenna_mount_twin_cover_8_twotone.3mf`, `antenna_mount_twin_cover_11_twotone.3mf` | the same covers with the frequencies in a second colour: one object, the cover on filament 1 and the lettering (`antenna_mount_twin_cover_text_8` / `_11`) on filament 2. Built by `make-cover-3mf.py` from binary STL exports |
| `usbc_gauge` | test coupon: five candidate USB-C cutouts, to fit the connector before printing a whole plate |

Two extra targets, `test_antenna` and `test_speaker`, clip the real shell
geometry to a small box so a fit test prints in minutes instead of hours.

## Rendering and exporting

Set `part` at the top of the file, or override it from the command line:

```bash
openscad --backend=manifold --export-format binstl \
         -D 'part="shell"' -o shell.stl retro-enclosure.scad
```

Binary STL: the shell is 75,000 facets, which is far smaller as binary than
as ascii for byte-identical geometry, and every slicer reads both.

`part="preview"` shows the whole stack assembled; `part="exploded"` separates
it.

Exporting an STL already forces a full geometry evaluation, and OpenSCAD
prints the result on stderr — check for `Status: NoError` and the
`Top level object is a 3D object (manifold)` line before printing. (Earlier
notes here said to pass `--render`; as of OpenSCAD 2026.06 that flag takes an
argument and a bare `--render` just prints the usage text, so a script using
it silently exports nothing.)

## Things that are easy to get wrong

These are all mistakes that were actually made and fixed here, kept as
warnings rather than as history:

- **`glass_thickness` is the glass sheet alone (1.62mm), not
  `panel_glass_depth`** (6.45mm, the whole panel module). The rabbet spans
  the glass; using the module depth leaves a gap you have to squeeze shut.
- **The antenna mount is counter-tilted forward by `stand_angle`.** The case
  leans back by that same angle in the cradle, so the two cancel and the
  antenna ends up vertical. Get the sign wrong and it is off by double.
- **The cradle only cups the case; the retention rails are what hold it.**
  With the bowl's axis tilted, gravity pushes the case straight down that
  axis, and nothing else opposes it.
- **Speaker brackets must be clipped to the outer cylinder.** They are flat
  slabs across a curved wall, so their corners otherwise punch through it.
- **Grille holes have to cut through the bracket as well as the wall**, or
  they dead-end in solid plastic and no sound gets out.

## The back comes off

The back used to be a fixed floor with the electronics standing on it, which
meant the only way to a Pi was through the glass. It is a separate plate now,
screwed to eight insert posts exactly as the faceplate is, and everything
that stood on the floor went with it. Undo eight screws and the tray lifts
out as one assembly.

**This plate is the same part as the kitten's.** Both cases are the same
223.34mm diameter, both use the same eight-post ring, and both lean back by
the same 18°, so one plate and one antenna mount serve both builds. That is
checked rather than asserted: exported from each design, the two meshes are
15,410 facets that compare equal as sets — the same solid, differing only in
triangle order.

**There is no fan mount.** There was a plate standing perpendicular to the
tray carrying a 30mm fan; the fan goes on the Pi instead. `fan_mount()` and
its variables are left defined but unused — the same treatment the wall-mount
keyhole code above gets — so putting it back is a one-line change. Both
grille patterns stay as plain vents.

The insert holes are drilled in `shell()`'s difference stage rather than
inside the post module. The speaker brackets reach the wall at 0° and 180°,
exactly where two of the posts stand, so a hole subtracted inside the module
gets unioned shut again by the bracket landing on top of it — two of the
eight would have printed solid. `back_inserts_open` is the check that holds
this, and it is a positive control: it has to *find* eight open bores.

### The locating lip

A rib on the plate's inner face drops into the bore, so the plate lands
centred and square and stays put while the screws go in, instead of being
juggled against eight holes at once. The outer top edge is chamfered by
1.2mm so it finds its own centre rather than catching square.

It is eight arcs, not a ring. A continuous ring at bore diameter is the
obvious shape and it is unbuildable here: the insert posts span r=102.2–111.2
and the bore wall is r=108.7–111.7, so the posts straddle the wall and a ring
would run through all eight of them. One arc per gap between posts locates
just as well — three points fix a circle and this has eight.

Three checks hold it, because a single "does the plate fit" test passes just
as happily when the lip is missing: `lip_present` (a positive control — it
must find the lip at all), `lip_clears_posts`, and `lip_inside_bore`, since a
lip larger than the bore does not locate anything, it just stops the plate
seating.

### One pass-through, not two

The USB-C power gland and the SMA antenna gland are replaced by a single
opening for a panel-mount USB-C cable. The antenna no longer needs a bulkhead
here at all — its coax comes in through the antenna mount's own cable bore,
inside the bolt circle.

**The cutout has been fitted to the real connector** (2026-09-29): it fits
the window, and its two mounting screws are 16.5mm apart. Those screws are
M3, so the holes are M3 clearance (3.4mm) like every other screw hole. The
listing publishes no cutout size, so for a different connector print
`usbc_gauge` — the cutout plus four neighbours at ±0.5 and ±1.0mm — and fit
it before committing a back plate. A coupon is minutes; a plate is hours.

### The front: trim, glass, retainer

Eight M3 × 14 screws go through the front trim's M3 clearance holes (3.4mm),
past the retainer, and into the M3 inserts in the shell's front posts.

**The retainer slips into the shell with 0.4mm to spare all round**
(`retainer_clear`). It was drawn at exactly the bore's diameter, and the
first print, PETG in an ASA shell, had to be forced in (2026-10-09). ASA
shrinks a little more than PETG, which made the zero clearance worse, but the
missing clearance was the cause. Its screw holes are **open notches** at the
rim: the screws sit where the shell's inserts are, which leaves less than a
hole's width of ring outside them, and closed holes printed as a 0.3mm
sliver. The notches also stop the ring turning. Checks: `retainer_clears_bore`,
`retainer_screws_pass`, `trim_screws_pass`.

**The connector is 37 mm lower than it first was** (2026-10-10), at `[60, -51]`, so the power jumper no longer bends against the Pi's USB ports beside the old spot; a check proves a plug there clears the stand with the case leaning back.

**The connector sits in a pocket** (2026-10-10). Its body is a 22.25 × 11 mm
boss mounted from inside; through the full 3 mm plate the socket sat 3 mm
below the outer face and a plug would not seat. The outer face now has a
2 mm pocket the boss's size (0.3 mm clearance a side), so a 1 mm web is all
that stands in front of the connector; the two screw heads sit in the pocket,
and the same M3 × 6 screws reach 2 mm further into the connector. Checks:
`usbc_recess_open`, `usbc_recess_web`.

### The plate fits one way only

The plate's locating rib is eight identical arcs between eight evenly
spaced posts, so it used to seat at any of eight positions 45° apart, and
only one of them puts the antenna mount at the top. A small block on the
shell's bore wall at 247.5° (lower left, between the posts at 225° and 270°)
now meets a matching notch in one arc of the rib: upright, the plate drops
in; turned to any other position, the block lands on the rib and the plate
stands proud before a screw goes in. It sits well clear of the antenna-mount
bosses at the top and the USB-C window, and both shells put it at the same
angle, so the one plate still fits both cases.

`key_fits` proves the upright plate meets the block with no volume, and
`key_blocks_45` … `key_blocks_315` prove each of the other seven positions
collides (43.7 mm³ each), each as its own check, because a key that blocked
only some angles would still let the plate in wrong.

### The antenna mounts on the back, and the turret is gone

The turret grew the socket out of the top of the case wall. The socket now
lives on a bolt-on arm on the removable plate, which is the same part the
kitten build uses — so both cases carry the identical antenna assembly, and
the angle can be changed without reprinting a shell.
`antenna_turret_solid()`/`antenna_turret_cuts()` are left defined but unused,
the same treatment the wall-mount keyhole code gets.

`no_turret` holds it, and its first version was wrong in an instructive way:
"nothing may stand proud of `outer_dia`" reported 13,632mm³ of turret that
was actually the decorative rivets and the cradle rails, which stand proud on
purpose out to r=115.7. The turret reached r=128, so the probe sits at 116.67
— outside the rivets, well inside a turret. `turret_probe_works` is its
paired control: the retired turret module has to be *caught* by that same
probe, or an empty result would only prove the probe was set too wide.

### The antenna mount screws into inserts

Three bosses on the plate's inner face take M3 heat-set inserts, so the mount
screws into the plate rather than needing a nut held inside the case while
the bolt is turned outside. The bores are two diameters on purpose: the
insert pocket stops on a shoulder 1mm above the plate rather than running out
through it, so the insert cannot be pressed too deep and the bolt still
passes freely from outside.

The bolt circle is clocked 30° off the vertical, which is not cosmetic. At
the obvious 0° one bolt points straight up the plate, putting its boss at
y=103 with an outer edge at 106.5 — into the locating lip, whose inner face
is at 106.3.

### The vents moved

Both grille patterns stay as plain vents, but the upper one moved from
y=+68 to y=−68. The antenna mount's flange is a 40mm disc centred at y=88 (y=81 since 2026-10-07, see below), so
at +68 the grille sat underneath it from y=68 to y=81 — venting into the back
of a solid disc. `vents_clear_of_mount` holds the new position and
`vents_were_under_mount` is its paired control, finding the 257mm³ overlap
the old position had.

### Side slots: top only, and cut through

The shell's side slots were cut all the way round. At each speaker, three of them ran across the grille. Underneath, six landed on the cradle's retention rails. None of them were vents: each cut was centred on the outer face, so it went only 2.5mm into the 3mm wall.

Now there are nine, across the top between the speakers (`exhaust_a0`..`exhaust_a1`, 30–150°), and they go right through. That gives the fan's air a way out at the top, where warm air goes anyway.

- `exhaust_top_only` checks that nothing is cut outside that arc.
- `exhaust_reaches_inside` checks that each slot breaks out past the wall's inner face. It finds about 115mm³, about 13 per slot; a blind dent finds nothing.

### Speaker grilles: one clean block each

Each speaker's grille is now only the rows in front of the ribs: five rows of 21 holes. Two things went:

- **The single row between the two ribs.** It read as a stray line of holes, not part of the grille.
- **The three rivets of the front ring that fell on each grille.** They stood up among the holes. The ring keeps its other 18.

These checks hold the change:
- `grille_in_front_of_ribs` and `rivets_clear_of_grilles` must come out empty. Both find the old geometry when run against it.
- `grille_present` and `rivets_present` are their positive controls.

## Heat-set inserts

Every screw that gets undone goes into a brass M3 heat-set insert. The holes are sized for the Kadrick M2–M5 kit: its M3 inserts are 4.5 mm across the knurl and 3.9 mm at the lead-in. Every insert hole is **4.0 mm**, so the lead-in drops in square and the knurl melts 0.25 mm a side into the plastic. (They were 4.2, which left a 4.5 mm insert only 0.15 mm of bite.)

| Where | Count | Insert | Screw | Notes |
|---|---|---|---|---|
| Front posts in the shell (front trim and retainer screw into these) | 8 | M3 × 5 | M3 × 14 | Pressed from the front, flush with the shelf the retainer sits on |
| Back posts in the shell (back plate screws into these) | 8 | M3 × 6 | M3 × 8 | Pressed from the back face, flush |
| Antenna mount flange | 3 | M3 × 5 | M3 × 8 | The pocket is in the mount; the screws come from inside the case, through the back plate |
| Twin antenna mount's cover | 5 | M2 × 3 | M2 × 6 | 3.0 mm holes in the cover seat (for a 3.2 mm knurl; 3.2 if the kit's inserts are the 3.5 mm kind — measure them). The cover's holes are counterbored 4.4 mm × 1.5 mm, so the cap heads stand only 0.5 mm proud (since 2026-10-10) |
| Speaker bosses (optional) | 8 | M2 × 3 | M2 × 6 | The 2.6 mm pilot takes the speaker's self-tapping screws; drill it to 3.0 for an M2 insert |

**The front posts are new.** They used to be only 2 mm tall: an insert sat in 2 mm of plastic with open air under it and the wall on one side only (measured: a third of the ring round it was solid). Now each post hangs 8 mm below the shelf, merged into the wall, with a 45° cone under it so it prints without support. The holes are cut after the whole shell is unioned, so the speaker brackets at 0° and 180° can't fill them.

- `front_inserts_surrounded` proves every front insert has a 1.75 mm ring of plastic all round it for its full length. Run against the old shell, it finds 545 mm³ missing.
- `front_insert_holes_open` is its positive control.

**Pressing them:** a soldering iron with an M3 insert tip, at about 220 °C for PLA or 245 °C for PETG.
1. Start the insert square in the hole.
2. Let it sink under its own weight plus light pressure. Don't push hard.
3. Stop when it is flush.
4. Hold a flat, cool piece of metal on it for a few seconds while the plastic sets, so it stays square.

### The twin mount: 1090 and 978 MHz

The FlyCatcher has two antenna inputs, 1090 and 978 MHz, and the Nooelec bundle has a hinged whip for each. `antenna_mount_twin` holds both.
- **Same base as the others:** the flange and three bolts, so nothing else changes.
- **A crossbar** with a bulkhead jack at each end, 80 mm apart. Antennas this close in frequency detune each other when bunched together.
- **Counter-tilted,** like the single mounts, so the whips stand vertical with their hinges straight. Hinges hold firmly only at their stops, and part-way they sag over time.

**Cables:** two SMA male to SMA female bulkhead jumpers, RG316, about 30 cm (SMA, not RP-SMA): a bulkhead end has a threaded barrel with a nut and washer, which is what holds the antenna. The small right-angle pigtails in the antenna bundle are MCX, for Nooelec's USB sticks, and aren't used.

**Whip or external antenna, the user's choice:** each tower's jack is an ordinary SMA socket on the outside of the case. Screw on the Nooelec whip, or the coax from an antenna mounted outside or in a window; nothing inside changes. An outdoor antenna with an N-type connector needs an N-male to SMA-male cable. Leave the FlyCatcher's bias-tee switch off unless the outdoor antenna has a powered amplifier that needs it.

**Two parts since 2026-10-07: a body and a flat cover.** The first version ran each cable through an internal tunnel and could not be assembled: both ends of a jumper are rigid metal about 9 mm across and 15–20 mm long, and that cannot turn a right-angle corner inside an 11 mm bore. The checks had only ever passed a straight probe down each leg. Now the crossbar and towers have an open channel on the side away from the case, closed by a cover on five M2 screws, so everything is laid in and nothing is threaded round a corner. The arm's bore runs straight on through the crossbar and out of the channel floor; it is 13 mm, and so is the plate's hole, because both plugs share it and the second has to pass the first cable. Under each tower's panel is a slot that is a close fit on the jack's hex body, so the jack cannot turn while its nut is tightened. The panel is 2 mm: the bulkhead's thread is 10 mm from its shoulder, and 2 of panel, 0.6 of washer and 2.5 of nut leave 4.9 mm for the whip's own coupling nut.

**The plate's cable hole grew from 11 to 13 mm the same day.** A back plate printed before that — including one printed from the y=81 plate committed earlier on 2026-10-07 — will not pass the second plug and must be reprinted.

**Two styles, by the jumper's bulkhead body.** Measure the body behind the shoulder across its flats: the jumpers on hand come as 8 mm and as 11 mm hexes, and `antenna_mount_twin_8` / `antenna_mount_twin_11` (with their covers) are cut for each — slot = flats + 0.8, a pocket the hex's size under the panel, the tower, bar and cover sized to suit. Both take the same 6.35 mm barrel. Any other size is one number: `antenna_mount_twin([9, 9])`, or a mixed pair. A round body has nothing for the slot to hold; the jack is then held with thin pliers through the open channel while its nut goes on, before the cover.

**Which side is which:** the cover carries each tower's frequency, engraved under it and read from behind the case — `1090` on the left, `978` on the right (`ant_twin_labels`; `ant_twin_label_on = false` for a plain cover). The 1090 whip is the shorter one.

**Printing:** body flange-down with tree supports (Bambu Support for ABS interface), as the other mounts print. The towers and bar have 6 mm corners and rounded edges, like the cases, rather than a box. The channel, slots, insert holes and jack holes all face up or sideways and need nothing; the towers' outboard ends and the bar's top edge start in mid-air, so the supports go on the face toward the case, where nobody sees the scars. Cover flat, counterbored face down, no support. ASA on a clean Engineering plate, no glue.

**Fitting the cables** (cover off, body held channel-up — or the flange hanging over the bench edge, since the plugs come out of its underside):
1. Push each plug end into the bore at the centre of the channel, straight down the arm and out through the flange — the second plug goes in beside the first cable with a wiggle. Leave about 10 cm of each cable beyond the bore's mouth.
2. Lay one cable along the channel to each tower. Hold the jack's hex body with the barrel pointing up its tower and slide it sideways into the open slot until it stops.
3. Push the jack up with a fingertip through the open channel: the top of the slot is a closed pocket the hex's size, and the barrel comes through the panel when the body is in it. Washer and nut on from the top, finger tight, then a quarter turn with an 8 mm (5/16") spanner — the pocket holds the jack, so nothing inside has to be held. Don't crank it; the panel is 2 mm of ASA. Check the nuts again after a week; ASA relaxes a little.
   Set each whip so its hinge folds towards or away from the wall, not towards the other whip: that's the direction the mount is weakest, so the hinge gives before the panel does, and a folded whip then clears the other tower.
4. Tidy the cables into the channel and fit the cover: five M2 × 6 into the M2 inserts.

**Lettering in a second colour.** Open the cover's `_twotone.3mf` rather than its STL. The lettering is many separate letters, and a slicer splits a multi-lump STL into one part per letter, so picking a colour for "the text" would colour one letter; the project file already has the cover on filament 1 and every letter on filament 2. Change either in the slicer. The cover prints outer face down, so the lettering is its first 0.6 mm, three 0.2 mm layers: three filament changes, nothing after. The plain STL still prints the engraved, one-colour cover.
5. Pass both plugs through the plate's 13 mm hole, bolt the flange on from inside the plate with the three M3 × 8, plug 1090 and 978 into the FlyCatcher, and screw the whips on (the 1090 whip is the shorter one). For an outdoor antenna, screw its coax onto the same barrel instead, and give the coax its own strain relief within a few centimetres of the tower.

To replace a cable: back plate off, cover off, nut off, slide the jack out of its slot, pull the plug back up through the bore. The mount stays bolted to the plate.

**Checks:**
- `twin_bore_straight`: a plug beside a cable (12 mm) passes straight down the 13 mm bore from the flange face to below the crossbar.
- `twin_slot_takes_jack`: an 8 mm-across-flats hex body stands in each slot under its panel.
- `twin_cover_fits`: the cover sits in its seat without touching the body; `twin_cover_seats` (control) finds the body when the cover is pushed 2 mm in. `twin_channel_open` and `twin_cover_screws_open` (controls) find a rod along the channel and rods through the cover's holes whole, and `twin_channel_probe_clear` and `twin_screw_probes_clear` are their complements: the same rods meet no body at all.
- `top_screw_clear_of_twin`: the plate's top screw and a hex key clear the mount.
- `twin_antennas_clear_case`: both whips, swept 220 mm up, miss the case (and the kitten's ears); `twin_antennas_probe_works` (control): the same envelopes moved 60 mm down the axis and 40 mm toward the case do hit it.
- `twin_vs_plate`, `twin_vs_stand`: no collisions with the back plate or the stand.
- `twin_panels_present`, `twin_holes_open`: positive controls; the panels are there and the jack holes are open.

## Checks

`sh run-checks.sh`. The script keeps three lists: targets that must come
out with no real volume (an interference, or a probe that should pass
through air); positive controls that must find geometry (the holes a probe
should find open, the paired "same probe, wrong place" controls such as
`vents_were_under_mount`, `top_screw_was_under_mount` and
`twin_antennas_probe_works`); and `canary`, which proves the modules are
being found at all — without it a typo in the `use <>` path makes every
other check pass against nothing.

## Smoothness

Curve resolution is set by `$fs` (0.4mm) and `$fa` (0.5°), not a fixed facet
count.

A fixed count makes the flats grow with the feature, so the biggest surfaces
come out roughest. At the old `$fn = 96` this shell's 223mm rim carried
**7.3mm flats** and the cradle 8.2mm, while every 3mm screw hole also got 96
sides it had no use for. `$fs` caps the chord — the width of one flat, which
is what the eye reads as faceting — so a big curve gets the facets and a
small hole does not.

**This is the only design here that has actually been printed**, so the small
fit-critical features keep their own explicit `$fn` and are untouched. What
changed is the geometry that had no explicit setting, plus the four wide
arcs. Measured against the previous meshes, the largest dimensional change
anywhere is **+0.064mm** on the shell's outer diameter — the flats moving
outward toward the true circle, which is the direction that matters — and
every other extent moves by 0.003mm or less. Volumes rise 0.08–0.15%. All of
that is an order of magnitude under print tolerance, so nothing about the
fit changes.

## Generated STLs

Committed alongside the source so the folder is self-contained, but they are
generated. Change the `.scad` and both must be re-exported and committed
together, or the mesh quietly stops matching the source it claims to come
from.

### The connector has to fit through, not just the cable

The bore was 9mm and the coax **connector** is 9.15mm across its widest
point, so it did not pass at all. Worse, the straight bore is cut along the
plate's normal while the socket above it is tilted by `stand_angle`, so the
two were not coaxial and the socket floor met the bore at an angle — leaving
a shoulder across the opening for the antenna's base to land on. Widening the
bore alone would not have removed that; it is a consequence of the two axes
disagreeing.

The socket floor is now opened square to the **antenna's** axis and hulled
down onto the straight run, so there is one continuous passage with no step
anywhere across it. `connector_passes` sweeps a 9.15mm plug gauge along that
path and must touch nothing; `connector_gauge_works` is its paired control,
an oversized gauge that must be caught. Swept by hand the passage clears
10.5mm and blocks at 11.0mm, so the connector has 1.35mm of margin.

Note for anyone tuning this: `-D` on the command line reaches `echo` but not
the CSG tree for these files, so a gauge sweep driven by `-D` silently
measures the file's own value at every step and reports that everything
passes. Edit the number instead.

### The antenna socket, and the lip that holds the base

The socket was Ø33 and a printed mount would not take the antenna at all: the
base is a flared cone slightly wider than that where it has to pass, so it
never got under the rim. It perched on top and tipped over — while the cable
underneath ran through perfectly, which is the part that had been checked.

Then the second printed one had its **rim snap off** while a base was being
levered under it, which says the approach was wrong and not just the number.
A 2mm chamfer left 2.5mm of wall at the edge, and a printed rim that thin,
pried outwards across its layer lines, is weak. Stiffness goes as thickness
cubed, so the barrel went 45 → 48 and the chamfer 2 → 1.2mm: 4.8mm of wall at
the edge, roughly seven times stiffer.

The deeper point is that **the base is held by depth, not by an overhang**.
The socket is 8mm deep, the antenna sits down inside it, and the chamfer is a
lead-in for a base that is already smaller than the hole — not a ramp for
forcing an oversized one past. If it has to be levered, the socket is too
small; make it bigger rather than pushing harder.

### What was actually stopping it, after three wrong guesses

The base measures **31.25mm across its flared bottom**, and **the lead leaves
the SIDE of the base 7.98mm above it** — both measured. The original socket was
Ø33, already 1.75mm of clearance, so *the bore was never what stopped it*, and
three attempts to fix the bore were fixing the wrong thing: that the base was
wider than the hole, that it was a cone flaring above a narrow bottom, that
the connector needed room beneath. None of them were true.

With the base seated, the lead is 7.98mm above the socket floor — and it
cannot go down through that floor, because the base is sitting on it. It has
to leave sideways. The printed mount gave it nowhere to go, so the connector
ended up jammed in the notch where the cable passage happens to break through
the wall, holding the base up at an angle. That notch was an accident of the
geometry; there is now a deliberate slot, 7mm wide, running from the floor up
past the rim.

It faces local +Y in the antenna's frame, which works out to world
(0, +0.309, −0.951) — down and back toward the plate — so the lead drops
straight into the passage that was already there instead of being led around
the barrel. `cable_slot_open` checks a rod at the measured exit height passes
out through the wall, and `cable_slot_other_side` is its control: the same rod
on the far side must be blocked, or "the slot is open" would be
indistinguishable from "the probe missed the mount".

`socket_takes_base` holds it, with `socket_gauge_works` as its paired control.
Its first version was wrong in a way worth recording: it ran a full-diameter
disc 12mm into the air above the mouth and failed at 283mm³, which was the
arm alongside. A 35mm cylinder held 12mm above the socket really does overlap
the arm — and means nothing, because the base is a cone that narrows and comes
in from outside. The question is whether the base fits the socket.

## Two antenna mounts, and which to print

`antenna_mount` holds the antenna itself: a 33mm socket cut around the
FlightAware desktop puck's 31.25mm base, with a slot for the lead that leaves
the side 7.98mm up. It fits that antenna beautifully and nothing else, which
makes the case choose the antenna.

`antenna_mount_sma` inverts that. Same flange, same three bolts into the same
inserts, same counter-tilt -- only the far end changes, to a panel-mount SMA
jack. Anything with an SMA plug now works: the same puck, a tuned whip
standing straight off the back, or coax running to an antenna somewhere with
a view of the sky. Swapping it is three screws; the back plate and both
shells are untouched.

Print the SMA one unless you specifically want the puck held on the case.
Measured on this hardware, an indoor puck saw **1 aircraft** while a properly
sited antenna saw **14 of the same sky at the same moment** -- so the ability
to put the antenna somewhere else is worth more than any mount that holds it
here.

The counter-tilt is the part not to touch. ADS-B is vertically polarised, and
`ant_axis_frame()` is what keeps the jack vertical while the case leans back
18 degrees in its cradle.

Four things are checked rather than assumed, and the interesting one is
`sma_passage_joins`: the cavity behind the jack has to actually meet the
cable bore, or the jack threads into a sealed pocket and the coax has nowhere
to go. That failure is invisible in preview -- both volumes are cut, the part
looks hollow, and the wall between them only exists in the print.

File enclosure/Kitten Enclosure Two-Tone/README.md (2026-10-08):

# Kitten enclosure — two-tone

The round display as a cat's face, in two colours: black stand, **white paws
with black toes**, and a **black tail with a white tip**. Ears, whisker-dot
speaker grilles, a nose on the bezel, and a stand with paws and a curled
tail.

two-tone stand

Every dimension that touches a physical part comes verbatim from the
[Retro Radar Enclosure](../Retro%20Radar%20Enclosure/), which is printed and
validated: the 203.34mm round panel, the Pi's 58×49 standoff pattern, the two
100×45mm speakers, the 30mm fan, the M3 screw ring, the USB-C and SMA
bulkheads. Only the shape is new, so the two cases are interchangeable on the
same hardware.

This began as a fork of a single-colour kitten design, which has since been
removed — the paws and tail here are about 15% larger than they were in it,
because at two colours they stop being a silhouette detail and become the
thing the eye lands on. `stand.stl` is the whole stand as one piece if you
want it in a single filament.

## Parts

The head is one colour and prints as before:

| part | colour | what it is |
|---|---|---|
| `shell` | black | the head — body cylinder plus two ears, and all the internals |
| `front_trim` | black | the face — bezel ring with a nose, whisker grooves and seven screw holes |
| `retainer` | — | ring behind the glass (identical to the retro part) |
| `back_plate` | black | removable back — locating lip, vents, one USB-C pass-through, the antenna mount's bolt holes and cable hole |
| `antenna_mount` | black | bolt-on arm carrying the antenna socket |
| `antenna_mount_sma` | alternative mount: same flange, arm and counter-tilt, ending in a panel-mount SMA jack instead of a socket cut for one antenna's base |
| `antenna_mount_twin_8`, `antenna_mount_twin_11` | **the one to print for the FlyCatcher:** same flange and three bolts, ending in a crossbar with two SMA jacks 80 mm apart, for the 1090 and 978 MHz whips; counter-tilted so both stand vertical with their hinges straight. Two styles, for jumpers whose bulkhead body is an 8 mm hex or an 11 mm hex; two parts each, this body and the cover below (`antenna_mount_twin` is whichever `ant_twin_jack_af` names) |
| `antenna_mount_twin_cover_8`, `antenna_mount_twin_cover_11` | the 3 mm cover that closes the twin body's cable channel, on five M2 screws, with each side's frequency engraved in it (`twin_assembled` and `twin_assembled_11` show both parts on the plate, for pictures only) |
| `usbc_gauge` | — | test coupon: five candidate USB-C cutouts, to fit the connector before printing a plate |

The stand is split into five bodies, one per colour region:

| part | colour | what it is |
|---|---|---|
| `stand_body` | **black** | plinth, cradle arms, keel |
| `stand_paws` | **white** | both foot pads |
| `stand_toes` | **black** | the eight toe lobes |
| `stand_claws` | **white** | eight real claws, one per toe |

`kitten-stand-twotone.3mf` is all six of the above in one project file with
the filaments already assigned — the easiest way in, and the one that avoids
the multi-lump selection problem described under *Printing it in two colours*.
| `stand_tail` | **black** | the tail from root to the white tip |
| `stand_tail_tip` | **white** | the flicked-up end |

`stand` is the whole stand as one piece, the same shape in a single
filament — useful if you are not printing in two colours, and it is also the
reference the five coloured parts are checked against.

## The back comes off, and carries the antenna

The back used to be a fixed floor with the electronics standing on it, so the
only way in was through the glass. It is a separate plate now, screwed to
eight insert posts exactly as the faceplate is.

**This plate is the same part as the retro build's**, and so is the antenna
mount. Both cases are the same 223.34mm diameter, use the same eight-post
ring, and lean back by the same 18°. That is checked rather than asserted:
exported from each design, the two back plates are 15,410 facets that compare
equal as sets — the same solid, differing only in triangle order.

A rib on the inner face drops into the bore so the plate lands centred and
square and holds itself there while the screws go in, with a 1.2mm chamfer on
its outer top edge so it finds its own centre. It is eight arcs rather than a
ring: the insert posts span r=102.2–111.2 against a bore wall at
r=108.7–111.7, so they straddle the wall and a continuous ring would run
through all eight. Three checks hold it — `lip_present` as a positive
control, `lip_clears_posts`, and `lip_inside_bore`, since a lip larger than
the bore does not locate anything, it just stops the plate seating.

The two cable glands are gone, replaced by a single opening for a panel-mount
USB-C cable; the antenna's coax comes in through the mount's own bore
instead. **The cutout has been fitted to the real
connector** (2026-09-29): it fits, its two M3 mounting screws are 16.5mm
apart, and the holes are M3 clearance. For a different connector, print
`usbc_gauge`, a coupon carrying the cutout plus four neighbours at ±0.5 and
±1.0mm, and fit it before committing a plate.

The mount screws into three M3 heat-set inserts on the plate's inner face
rather than through bare holes, so it can be removed without holding a nut
inside the case. The insert pocket stops on a shoulder 1mm above the plate so
the insert cannot be pressed too deep. The bolt circle is clocked 30° off
vertical for clearance, not looks: at 0° one boss reaches y=106.5, into the
locating lip at 106.3.

The upper vent moved from y=+68 to y=−68. The mount's flange is a 40mm disc
centred at y=88 (y=81 since 2026-10-07), so at +68 the grille sat underneath it from y=68 to y=81,
venting into the back of a solid disc — which is what prompted this.
`vents_clear_of_mount` holds the new position, and `vents_were_under_mount`
is its paired control, finding the 257mm³ overlap the old one had.

The Pi is mounted to the LCD panel, so taking the plate off exposes the back
of the Pi and its cabling rather than removing it. The four 58×49 Pi
standoffs the plate used to carry were never used and are gone (2026-10-07;
`pi_posts()` keeps their geometry). **There is no fan mount** — the fan goes on the Pi. The two grille
patterns stay as plain vents.

The antenna mounts on the back of the plate rather than on a turret, since a
turret out of a cat's skull is a spike. It is a **bolt-on**: three M3 bolts
on a 30mm circle. That keeps both parts flat and support-free on the bed, and
lets the antenna angle change later without reprinting the tray. The cable
drops out of the socket and runs straight through the arm, the flange and the
plate into the case.

The mount sits inside the head's outline and cannot be seen from the front;
only the antenna shows, rising between the ears.

### Why the arm reaches straight back before the barrel rises

The arm goes **back** from the plate, and only then does a barrel rise from
its end along the antenna's own axis. That two-stage shape is forced, not
styled. A barrel coaxial with the antenna and rooted on the plate would have
to climb toward the head the whole way and would run into it.

The first attempt avoided that by hulling a pad on the plate to a disc at the
socket — which produced a *cone* with the socket bored into its flank, so the
antenna pointed sideways and down rather than up. A stub plus a barrel gives
a real cylindrical socket with a flat face square to the antenna.

The arm is 30mm because that is what the clearance costs. Swept against the
antenna's own envelope: at 22mm it fouls the head's top rim even at nominal
diameter, at 26mm it clears nominal but not +2mm, and at 30mm it still clears
with 6mm of radial slack. `antenna_clears_head` holds it.

## The plate fits one way only

The plate's locating rib is eight identical arcs between eight evenly
spaced posts, so it used to seat at any of eight positions 45° apart, and
only one of them puts the antenna mount at the top. A small block on the
shell's bore wall at 247.5° (lower left, between the posts at 225° and 270°)
now meets a matching notch in one arc of the rib: upright, the plate drops
in; turned to any other position, the block lands on the rib and the plate
stands proud before a screw goes in. It sits well clear of the antenna-mount
bosses at the top and the USB-C window, and both shells put it at the same
angle, so the one plate still fits both cases.

`key_fits` proves the upright plate meets the block with no volume, and
`key_blocks_45` … `key_blocks_315` prove each of the other seven positions
collides (43.7 mm³ each), each as its own check, because a key that blocked
only some angles would still let the plate in wrong.

## Printing it in two colours

The five stand bodies share one coordinate frame, so they occupy their true
positions relative to each other. That gives you two routes:

**Multi-material (AMS, MMU, tool changer).** Open
`kitten-stand-twotone.3mf`. It is the whole stand as one object with the six
bodies already inside it and a filament already assigned to each — nothing to
position, nothing to select.

That file exists because loading the STLs separately does not work well, for
a reason that is not obvious. Three of the bodies are physically several
disconnected lumps: two paws, two clumps of toes, and eight separate claws,
because that is what the shapes are. Slicers split a multi-lump mesh into
separate parts on import, so picking a filament for "the claws" colours **one
claw** and leaves the other seven — which looks like the tool ignoring you.
There is no way to fix that from the STL side; eight claws cannot be one
connected lump. So the assignment lives in the project file instead.

The filament slots are 1 for the black (body, toes, tail), 2 for the white
(paws, tail tip) and 3 for the claws, kept on their own slot so they can be a
third colour. Change any of them in the slicer.

If you would rather load the STLs by hand anyway: load the first, then "add
part"/"load as part" for the rest, which preserves their positions, and
assign a filament to each.
No supports needed for the paws or toes; the tail tip lifts off the paw and
wants a little support under the flick.

**Single extruder.** Print them as separate objects and glue. Every split
follows a real seam in the shape — pad to toe, tail to tip — so the joins
land where the eye already expects a line. Print `stand_body` flat on its
base; the paws, toes and tail parts are all small and sit stably on their cut
faces.

### Why the parts overlap slightly

The bodies deliberately interfere by 0.3mm (`colour_overlap`) along every
seam, and the first version of this design got that exactly backwards.

Cutting each part with the precise shape of its neighbour is the tidy answer
and it is the broken one. It produces a perfect partition — zero shared
volume — while leaving the two bodies sharing a *surface* at identical
coordinates. No renderer can decide which of two faces at the same depth is
in front, so the slicer stipples the seam with the other colour: a white paw
arrives speckled black, worst over the buried half of the paw where the
shared area is largest.

So each part is cut with a slightly inset copy of whatever takes precedence
over it, leaving a thin shell of shared material instead of a shared surface.
Nothing is coplanar, and the colour boundary moves by at most 0.15mm — a
fifth of a nozzle width, so which body a slicer awards the shell to cannot be
seen in the print.

The tail needed the opposite treatment. Its two parts are runs of the same
tapering tube, so wherever they overlap they carry the same outer skin —
and an overlap of identical skin is the very coincidence being avoided.
There the tip is grown rather than the body shrunk, so over the shared
stretch the white tip sits 0.15mm proud of the black tail it continues.

## The whisker grooves

Three short arcs engraved into the bezel face either side of the nose.

They were briefly in the wrong place, and it is worth recording how. The
nose sits at −y, the bottom of the face; the grooves were rotated about 0°
instead — the right-hand side — so all six landed 90° from the nose they
were meant to flank. That printed before anyone noticed, as six unexplained
indentations down one side of a faceplate.

They are now placed off `nose_angle` rather than a literal, and each sweeps
away from the nose so the two sides mirror. `whisker_off_nose` in
`checks.scad` pins it: the grooves must lie entirely within a 90° wedge
centred on where `nose()` actually puts itself. That wedge is written as a
literal 270 on purpose — deriving it from `nose_angle` would make the check
vacuous, since moving the angle would move the wedge along with the grooves.

## Where the colour goes, and why

- **Paws white, toes black.** The toes are the detail that makes a paw read
  as a paw, and they are small — they need the contrast more than the pad
  does. The clefts between them grew with the toes; the groove is the only
  thing making four toes read as four rather than one lumpy pad.
- **Claws are their own body, and they are real geometry.** The grooves
  between the toes were being read as the nails; they were never that — they
  are the only thing making four toes read as four. There are now eight
  actual claws, one off the front of each toe, following that toe's splay and
  drooping toward the desk the way a cat's does. Their base sits *inside* the
  toe rather than butted against it: a spike joined at a tangent point is a
  weak spot in the print, and a butted joint would share a surface with the
  toe, which is the coincidence that stipples the preview. The tip stops
  clear of the desk on purpose — claws that reached z=0 would carry the
  stand's weight on eight little points and rock, which `claws_off_the_desk`
  holds. `claws_stand_proud` is the paired positive control: a claw entirely
  buried in its toe passes every seam and volume check while being invisible
  on the print, which is exactly what the grooves-as-nails problem looked
  like.
- **Tail black, tip white, and the tip lifts.** The first version had the tip
  resting flat on the pad, which is what a sitting cat does — but that put a
  white tip on top of a white paw, where it vanished. The whole point of a
  white tip is that it reads against what surrounds it. Lifted, it is
  silhouetted from every angle, and a flicked tail tip is cat-like anyway.
  This was caught by rendering it and looking, not by any check.

## Smoothness

Curve resolution is set by `$fs` (0.4mm) and `$fa` (0.5°) in the `.scad`,
not by a fixed facet count.

A fixed count was what this had, and it makes the flats grow with the
feature — so the biggest, most looked-at surfaces come out roughest. At the
old `$fn = 96` the head's 223mm rim carried **7.3mm flats** and the cradle
8.2mm, while every 3mm screw hole also got 96 sides it had no use for. `$fs`
caps the chord — the width of one flat, which is what the eye reads as
faceting — so a large curve gets the facets and a small hole does not. The
head is now at 0.97mm and every sphere in the paws, toes and tail at 0.4mm,
which is one extrusion width: below that a 0.4mm nozzle cannot reproduce the
difference.

The meshes are exported as **binary STL**. At this resolution the stand is
173,000 facets, which is 52MB as ascii and 8.3MB as binary for byte-identical
geometry. Every slicer reads both.

`tail_smooth_steps` is the other half of it. The tail is hulls between
consecutive spheres, so every sphere leaves a crease running around the
tube. At the old resolution those creases were masked by the general
faceting; once the circumference was smooth they read as rings. 14 points
per control segment puts a joint every 2.4mm instead of 5.6mm, for about a
megabyte.

To go finer, lower `$fs` — but check the file sizes, because sphere cost
grows as the square.

**`use <>` does not carry `$fa`/`$fs`.** It imports modules and functions
only, so `checks.scad` and the preview files set them again at the top. Miss
that and they silently render at OpenSCAD's defaults, showing a faceting the
exported mesh does not have — or, worse, validating geometry that is not what
gets printed.

## Seven screws, not eight

The bezel has seven screw holes. There is an eighth insert post in the shell
at the same angle as the nose, and the nose stands on top of it — 2.6mm of
solid capping the hole, so that screw could never have been fitted. Rather
than leave a hole that cannot take a screw and reads as a moulding defect
under the chin, it is not cut at all.

The shell keeps all eight posts. An unused boss is invisible from outside and
keeps that part identical to the retro build it was copied from.

Found by probing the screw ring after a faceplate had already been printed.
`nose_screw_removed` now proves the hole is absent, and `other_screws_present`
is its paired positive control — an empty result from the first would also be
what a probe in the wrong place produces, so a probe at a normal position has
to find a real hole for the pair to mean anything.

## Heat-set inserts

Every screw that gets undone goes into a brass M3 heat-set insert. The holes are sized for the Kadrick M2–M5 kit: its M3 inserts are 4.5 mm across the knurl and 3.9 mm at the lead-in. Every insert hole is **4.0 mm**, so the lead-in drops in square and the knurl melts 0.25 mm a side into the plastic. (They were 4.2, which left a 4.5 mm insert only 0.15 mm of bite.)

| Where | Count | Insert | Screw | Notes |
|---|---|---|---|---|
| Front posts in the shell (front trim and retainer screw into these) | 8 posts, 7 used | M3 × 5 | M3 × 14 | Pressed from the front, flush with the shelf the retainer sits on |
| Back posts in the shell (back plate screws into these) | 8 | M3 × 6 | M3 × 8 | Pressed from the back face, flush |
| Antenna mount flange | 3 | M3 × 5 | M3 × 8 | The pocket is in the mount; the screws come from inside the case, through the back plate |
| Twin antenna mount's cover | 5 | M2 × 3 | M2 × 6 | 3.0 mm holes in the cover seat (for a 3.2 mm knurl; 3.2 if the kit's inserts are the 3.5 mm kind — measure them). No counterbores: a 3 mm cover printed face-down can't roof them, so the cap heads stand 2 mm proud of a face nothing touches |
| Speaker bosses (optional) | 8 | M2 × 3 | M2 × 6 | The 2.6 mm pilot takes the speaker's self-tapping screws; drill it to 3.0 for an M2 insert |

**The front posts are new.** They used to be only 2 mm tall: an insert sat in 2 mm of plastic with open air under it and the wall on one side only (measured: a third of the ring round it was solid). Now each post hangs 8 mm below the shelf, merged into the wall, with a 45° cone under it so it prints without support. The holes are cut after the whole shell is unioned, so the speaker brackets at 0° and 180° can't fill them.

- `front_inserts_surrounded` proves every front insert has a 1.75 mm ring of plastic all round it for its full length. Run against the old shell, it finds 545 mm³ missing.
- `front_insert_holes_open` is its positive control.

The kitten's bezel has seven screws (see *Seven screws, not eight*). The post under the nose needs no insert.

**Pressing them:** a soldering iron with an M3 insert tip, at about 220 °C for PLA or 245 °C for PETG.
1. Start the insert square in the hole.
2. Let it sink under its own weight plus light pressure. Don't push hard.
3. Stop when it is flush.
4. Hold a flat, cool piece of metal on it for a few seconds while the plastic sets, so it stays square.

### The twin mount: 1090 and 978 MHz

The FlyCatcher has two antenna inputs, 1090 and 978 MHz, and the Nooelec bundle has a hinged whip for each. `antenna_mount_twin` holds both.
- **Same base as the others:** the flange and three bolts, so nothing else changes.
- **A crossbar** with a bulkhead jack at each end, 80 mm apart. Antennas this close in frequency detune each other when bunched together.
- **Counter-tilted,** like the single mounts, so the whips stand vertical with their hinges straight. Hinges hold firmly only at their stops, and part-way they sag over time.

**Cables:** two SMA male to SMA female bulkhead jumpers, RG316, about 30 cm (SMA, not RP-SMA): a bulkhead end has a threaded barrel with a nut and washer, which is what holds the antenna. The small right-angle pigtails in the antenna bundle are MCX, for Nooelec's USB sticks, and aren't used.

**Whip or external antenna, the user's choice:** each tower's jack is an ordinary SMA socket on the outside of the case. Screw on the Nooelec whip, or the coax from an antenna mounted outside or in a window; nothing inside changes. An outdoor antenna with an N-type connector needs an N-male to SMA-male cable. Leave the FlyCatcher's bias-tee switch off unless the outdoor antenna has a powered amplifier that needs it.

**Two parts since 2026-10-07: a body and a flat cover.** The first version ran each cable through an internal tunnel and could not be assembled: both ends of a jumper are rigid metal about 9 mm across and 15–20 mm long, and that cannot turn a right-angle corner inside an 11 mm bore. The checks had only ever passed a straight probe down each leg. Now the crossbar and towers have an open channel on the side away from the case, closed by a cover on five M2 screws, so everything is laid in and nothing is threaded round a corner. The arm's bore runs straight on through the crossbar and out of the channel floor; it is 13 mm, and so is the plate's hole, because both plugs share it and the second has to pass the first cable. Under each tower's panel is a slot that is a close fit on the jack's hex body, so the jack cannot turn while its nut is tightened. The panel is 2 mm: the bulkhead's thread is 10 mm from its shoulder, and 2 of panel, 0.6 of washer and 2.5 of nut leave 4.9 mm for the whip's own coupling nut.

**The plate's cable hole grew from 11 to 13 mm the same day.** A back plate printed before that — including one printed from the y=81 plate committed earlier on 2026-10-07 — will not pass the second plug and must be reprinted.

**Two styles, by the jumper's bulkhead body.** Measure the body behind the shoulder across its flats: the jumpers on hand come as 8 mm and as 11 mm hexes, and `antenna_mount_twin_8` / `antenna_mount_twin_11` (with their covers) are cut for each — slot = flats + 0.8, a pocket the hex's size under the panel, the tower, bar and cover sized to suit. Both take the same 6.35 mm barrel. Any other size is one number: `antenna_mount_twin([9, 9])`, or a mixed pair. A round body has nothing for the slot to hold; the jack is then held with thin pliers through the open channel while its nut goes on, before the cover.

**Which side is which:** the cover carries each tower's frequency, engraved under it and read from behind the case — `1090` on the left, `978` on the right (`ant_twin_labels`; `ant_twin_label_on = false` for a plain cover). The 1090 whip is the shorter one.

**Printing:** body flange-down with tree supports (Bambu Support for ABS interface), as the other mounts print. The towers and bar have 6 mm corners and rounded edges, like the cases, rather than a box. The channel, slots, insert holes and jack holes all face up or sideways and need nothing; the towers' outboard ends and the bar's top edge start in mid-air, so the supports go on the face toward the case, where nobody sees the scars. Cover flat, counterbored face down, no support. ASA on a clean Engineering plate, no glue.

**Fitting the cables** (cover off, body held channel-up — or the flange hanging over the bench edge, since the plugs come out of its underside):
1. Push each plug end into the bore at the centre of the channel, straight down the arm and out through the flange — the second plug goes in beside the first cable with a wiggle. Leave about 10 cm of each cable beyond the bore's mouth.
2. Lay one cable along the channel to each tower. Hold the jack's hex body with the barrel pointing up its tower and slide it sideways into the open slot until it stops.
3. Push the jack up with a fingertip through the open channel: the top of the slot is a closed pocket the hex's size, and the barrel comes through the panel when the body is in it. Washer and nut on from the top, finger tight, then a quarter turn with an 8 mm (5/16") spanner — the pocket holds the jack, so nothing inside has to be held. Don't crank it; the panel is 2 mm of ASA. Check the nuts again after a week; ASA relaxes a little.
   Set each whip so its hinge folds towards or away from the wall, not towards the other whip: that's the direction the mount is weakest, so the hinge gives before the panel does, and a folded whip then clears the other tower.
4. Tidy the cables into the channel and fit the cover: five M2 × 6 into the M2 inserts.
5. Pass both plugs through the plate's 13 mm hole, bolt the flange on from inside the plate with the three M3 × 8, plug 1090 and 978 into the FlyCatcher, and screw the whips on (the 1090 whip is the shorter one). For an outdoor antenna, screw its coax onto the same barrel instead, and give the coax its own strain relief within a few centimetres of the tower.

To replace a cable: back plate off, cover off, nut off, slide the jack out of its slot, pull the plug back up through the bore. The mount stays bolted to the plate.

**Checks:**
- `twin_bore_straight`: a plug beside a cable (12 mm) passes straight down the 13 mm bore from the flange face to below the crossbar.
- `twin_slot_takes_jack`: an 8 mm-across-flats hex body stands in each slot under its panel.
- `twin_cover_fits`: the cover sits in its seat without touching the body; `twin_cover_seats` (control) finds the body when the cover is pushed 2 mm in. `twin_channel_open` and `twin_cover_screws_open` (controls) find a rod along the channel and rods through the cover's holes whole, and `twin_channel_probe_clear` and `twin_screw_probes_clear` are their complements: the same rods meet no body at all.
- `top_screw_clear_of_twin`: the plate's top screw and a hex key clear the mount.
- `twin_antennas_clear_case`: both whips, swept 220 mm up, miss the case (and the kitten's ears); `twin_antennas_probe_works` (control): the same envelopes moved 60 mm down the axis and 40 mm toward the case do hit it.
- `twin_vs_plate`, `twin_vs_stand`: no collisions with the back plate or the stand.
- `twin_panels_present`, `twin_holes_open`: positive controls; the panels are there and the jack holes are open.

## Checks

`sh run-checks.sh` runs every target in `checks.scad` and reports the
**volume** each produces.

Volume, not facet count. A boolean between parts that touch leaves
zero-thickness films along the boundary — thousands of facets and no volume —
so counting facets calls a correct model broken. The threshold is 1mm³
against a paw of roughly 27,000mm³, and a real interference has nowhere to
hide in that gap.

Volume alone is not enough either, which is what the speckled first version
proved: a shared surface has no volume at all. That is what
`check-coincident.py` below is for.

Alongside the fit checks on the head and cradle, the colour split adds:

- `material_lost` — must be **zero**: a region of the one-piece stand that no
  coloured part claims. That would print as a hole.
- `material_gained`, `paws_vs_toes`, `body_vs_paws`, `tail_vs_tip` — must be
  **small but non-zero**: these are the colour seams, and zero here means the
  parts share surfaces instead of overlapping, which is the speckling bug.
  Bounded at 1500mm³, which is 0.15mm of thickness over 10,000mm² of shared
  surface — far more than these parts have.
- `canary` — must produce geometry. Without it, a typo in the `use <>` path
  makes every check above pass against nothing, which has happened here
  before.

`check-coincident.py` makes the check the volume tests cannot: it compares
the exported meshes face by face and counts triangles two parts have at
identical coordinates. Two parts sharing a surface have zero shared volume
and still stipple, so nothing about that bug is visible in a volume
measurement. All ten pairs must come out at zero. With the overlap disabled
(`-D colour_overlap=0`) the same check reports 3,502 shared faces between the
paws and the toes, which is precisely the speckling.

Run everything with `sh run-checks.sh`, which also runs the coincidence
check.

## Regenerating

```sh
for p in shell front_trim retainer stand back_plate usbc_gauge \
           antenna_mount antenna_mount_sma antenna_mount_twin_8 antenna_mount_twin_11 \
           antenna_mount_twin_cover_8 antenna_mount_twin_cover_11 \
           stand_body stand_paws stand_toes stand_claws stand_tail stand_tail_tip; do
  openscad --backend=manifold --export-format binstl \
           -D "part=\"$p\"" -o "$p.stl" kitten-enclosure-twotone.scad
done
```

**The exporter is not deterministic.** Two consecutive exports of unchanged
source differ — 135 facets out of 210,448 on the stand, and even the facet
count moves (210,758 vs 210,448 across runs). It shows up on the stand and
not on the simple parts, which is consistent with it coming from the hundreds
of hulls the paws and tail are built from. Two consequences: re-exporting
everything makes the stand files show as modified whether or not anything
changed, so only re-export what actually changed; and comparing two STLs byte
for byte is not a test of whether they are the same shape — compare the
triangle sets instead.

The `.stl` files are committed alongside the source so the folder is
self-contained, but they are generated. Change the `.scad` and both must be
re-exported and committed together, or the mesh quietly stops matching the
source it claims to come from.

### The connector has to fit through, not just the cable

The bore was 9mm and the coax **connector** is 9.15mm across its widest
point, so it did not pass at all. Worse, the straight bore is cut along the
plate's normal while the socket above it is tilted by `stand_angle`, so the
two were not coaxial and the socket floor met the bore at an angle — leaving
a shoulder across the opening for the antenna's base to land on. Widening the
bore alone would not have removed that; it is a consequence of the two axes
disagreeing.

The socket floor is now opened square to the **antenna's** axis and hulled
down onto the straight run, so there is one continuous passage with no step
anywhere across it. `connector_passes` sweeps a 9.15mm plug gauge along that
path and must touch nothing; `connector_gauge_works` is its paired control,
an oversized gauge that must be caught. Swept by hand the passage clears
10.5mm and blocks at 11.0mm, so the connector has 1.35mm of margin.

Note for anyone tuning this: `-D` on the command line reaches `echo` but not
the CSG tree for these files, so a gauge sweep driven by `-D` silently
measures the file's own value at every step and reports that everything
passes. Edit the number instead.

### The antenna socket, and the lip that holds the base

The socket was Ø33 and a printed mount would not take the antenna at all: the
base is a flared cone slightly wider than that where it has to pass, so it
never got under the rim. It perched on top and tipped over — while the cable
underneath ran through perfectly, which is the part that had been checked.

Then the second printed one had its **rim snap off** while a base was being
levered under it, which says the approach was wrong and not just the number.
A 2mm chamfer left 2.5mm of wall at the edge, and a printed rim that thin,
pried outwards across its layer lines, is weak. Stiffness goes as thickness
cubed, so the barrel went 45 → 48 and the chamfer 2 → 1.2mm: 4.8mm of wall at
the edge, roughly seven times stiffer.

The deeper point is that **the base is held by depth, not by an overhang**.
The socket is 8mm deep, the antenna sits down inside it, and the chamfer is a
lead-in for a base that is already smaller than the hole — not a ramp for
forcing an oversized one past. If it has to be levered, the socket is too
small; make it bigger rather than pushing harder.

### What was actually stopping it, after three wrong guesses

The base measures **31.25mm across its flared bottom**, and **the lead leaves
the SIDE of the base 7.98mm above it** — both measured. The original socket was
Ø33, already 1.75mm of clearance, so *the bore was never what stopped it*, and
three attempts to fix the bore were fixing the wrong thing: that the base was
wider than the hole, that it was a cone flaring above a narrow bottom, that
the connector needed room beneath. None of them were true.

With the base seated, the lead is 7.98mm above the socket floor — and it
cannot go down through that floor, because the base is sitting on it. It has
to leave sideways. The printed mount gave it nowhere to go, so the connector
ended up jammed in the notch where the cable passage happens to break through
the wall, holding the base up at an angle. That notch was an accident of the
geometry; there is now a deliberate slot, 7mm wide, running from the floor up
past the rim.

It faces local +Y in the antenna's frame, which works out to world
(0, +0.309, −0.951) — down and back toward the plate — so the lead drops
straight into the passage that was already there instead of being led around
the barrel. `cable_slot_open` checks a rod at the measured exit height passes
out through the wall, and `cable_slot_other_side` is its control: the same rod
on the far side must be blocked, or "the slot is open" would be
indistinguishable from "the probe missed the mount".

`socket_takes_base` holds it, with `socket_gauge_works` as its paired control.
Its first version was wrong in a way worth recording: it ran a full-diameter
disc 12mm into the air above the mouth and failed at 283mm³, which was the
arm alongside. A 35mm cylinder held 12mm above the socket really does overlap
the arm — and means nothing, because the base is a cone that narrows and comes
in from outside. The question is whether the base fits the socket.

## Two antenna mounts, and which to print

`antenna_mount` holds the antenna itself: a 33mm socket cut around the
FlightAware desktop puck's 31.25mm base, with a slot for the lead that leaves
the side 7.98mm up. It fits that antenna beautifully and nothing else, which
makes the case choose the antenna.

`antenna_mount_sma` inverts that. Same flange, same three bolts into the same
inserts, same counter-tilt -- only the far end changes, to a panel-mount SMA
jack. Anything with an SMA plug now works: the same puck, a tuned whip
standing straight off the back, or coax running to an antenna somewhere with
a view of the sky. Swapping it is three screws; the back plate and both
shells are untouched.

Print the SMA one unless you specifically want the puck held on the case.
Measured on this hardware, an indoor puck saw **1 aircraft** while a properly
sited antenna saw **14 of the same sky at the same moment** -- so the ability
to put the antenna somewhere else is worth more than any mount that holds it
here.

The counter-tilt is the part not to touch. ADS-B is vertically polarised, and
`ant_axis_frame()` is what keeps the jack vertical while the case leans back
18 degrees in its cradle.

Four things are checked rather than assumed, and the interesting one is
`sma_passage_joins`: the cavity behind the jack has to actually meet the
cable bore, or the jack threads into a sealed pocket and the coax has nowhere
to go. That failure is invisible in preview -- both volumes are cut, the part
looks hollow, and the wall between them only exists in the print.

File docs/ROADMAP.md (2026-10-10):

# Roadmap: the five phases

**Baseline:** [v2.0.0](https://github.com/mferris/StratoScan/releases/tag/v2.0.0),
identical to OTA release `2026.09.27.15`. It is the revert point for
everything below.

Progress is tracked as GitHub
[milestones](https://github.com/mferris/StratoScan/milestones) and
[issues](https://github.com/mferris/StratoScan/issues). This file holds
the design decisions those issues depend on.

## Ground rules

- **Open source, license-clean.** Nothing is added without checking its
  license and terms first, and recording it in
  [THIRD_PARTY_NOTICES.md](../THIRD_PARTY_NOTICES.md). Anything
  non-commercial-only (such as RainViewer) is labelled as such.
- **The radar never depends on a cloud service.** The relay (below) adds
  push and fleet health. A unit that can't reach it keeps working exactly
  as it does today.
- **Privacy by default.** The exact home location never leaves the device.
  Anything sent off-device is opt-in, minimal and rounded.
- **No secrets on units.** Gifted units are in other people's houses. Keys
  that can act for the whole fleet (such as Apple's push key) live only in
  the relay.
- **Every fix is verified on the running device**, not just installed.

## What to buy

The parts each item needs are in [SHOPPING.md](SHOPPING.md).

## Architecture: the relay

One small **Cloudflare Worker** (`relay/`) with a D1 database. It is the
only server the project runs.

```
unit ──(signed heartbeat, events)──▶ relay ──(APNs)──▶ iPhone / Watch
unit ◀────(nothing: units only ever call out)──────────┘
phone ──(pairing, notification rules)──▶ relay
```

- **Unit identity:** each unit generates an Ed25519 keypair at install, and
  signs every request with it. The relay stores public keys only. Nothing
  shared or fleet-wide is baked into images.
- **Pairing:** the unit's screen shows a QR code with its ID plus a
  one-time pairing secret (valid 10 minutes). The phone scans it, and the
  relay links that phone's push token to the unit.
- **Heartbeat (opt-in):** every 6 h the unit sends its version, uptime,
  receiver health, SD wear estimate and last-error class. **No location.**
  A fleet page shows the maintainer every unit's health.
- **Events:** the unit decides locally what matters (notable aircraft,
  emergency squawk, low overhead…) and posts a small event. The relay fans
  it out to paired devices over APNs. Payloads carry aircraft data only,
  never the home location: identity, type, altitude, and distance rounded
  to half a nautical mile with a compass direction. That still hints where
  a unit is, so events are off until the owner pairs a phone, and the relay
  keeps them only 48 hours. A factory reset turns them off.
- **Failure mode:** if the relay is down, units keep a short queue, drop it
  on overflow, and the radar is unaffected.

## Phase 1: reliability you can see

| # | Item | Done when |
|---|---|---|
| 1.1 | RTC battery support: installer sets `dtparam=rtc_bbat_vchg` when a rechargeable cell is fitted; clock health in status | A unit keeps correct time across a power cut with no network |
| 1.2 | Storage off the SD card: NVMe boot via the Pi 5 M.2 HAT+ (or CM5 eMMC). Migration script, enclosure fit, installer checks | A unit boots and runs from NVMe; the enclosure fits |
| 1.3 | Relay foundation: Worker, D1 schema, signed-request auth, heartbeat endpoint, fleet status page | Deployed; tests pass; RDU's heartbeat shows on the fleet page |
| 1.4 | Unit side: keypair generation, opt-in heartbeat (setup toggle), sent every 6 h | RDU reports; turning it off stops it |
| 1.5 | Factory image: pi-gen build in GitHub Actions (Arm runner); first boot runs the installer; GPL source offer for readsb/tar1090 included | A fresh SD flashed from the release boots to the setup hotspot |
| 1.6 | Re-measure SD writes after the storage fixes (scheduled 2026-09-28) | Result recorded; any remaining large writer fixed |
| 1.7 | Recover a hung radio without a human: the watchdog power-cycles USB (uhubctl) before it reboots, since a Pi 5 reboot keeps USB powered | A hung SDR comes back on its own on a real unit |
| 1.8 | Core feed on the device: one service merges the antenna's and the network's aircraft, labels them once (operator, type, route, owner, notable), caches the lookups, and serves `/api/aircraft` to every screen; no antenna-relative fields | Live on RDU; labels match the kiosk's on a recorded sample |
| 1.9 | Kiosk and public page read the core feed; route and owner lookups move off visitors' browsers onto the unit | Same picture as before; public visitors no longer contact adsb.im or adsbdb |
| 1.10 | ~~`events.py` reads the core feed;~~ the copied classification tables are deleted. **Done 2026-09-30:** the tables are shared from `labels.py`; `events.py` stays on readsb's `aircraft.json` on purpose (it needs the antenna-relative fields, and alerts shouldn't depend on the core feed) | Same alerts from the same fixtures, with no tables of its own |
| 1.11 | Cut the radar's drawing cost: static layers drawn once, the sweep rotated by the compositor, only moving things redrawn | Measured on RDU: the GPU process well under half its current ~94% of a core, and cooler |
| 1.12 | Visitor counts for each radar's public page, for its owner: views, unique visitors (a daily-salted hash, never stored), the owner's app counted apart, hour of day, device type, referring site; no cookies, no stored addresses; on the radar's screen, setup page and app (#50) | Visits from a phone on mobile data show within a minute; nothing stored holds an address |
| 1.13 | Fleets with their own administrators on the relay: radars join by their owner's invite code and can leave any time; administrators see health and visit counts per radar and in total, never locations, phones or alerts; per-administrator sign-in (#51) | The family fleet with RDU in it; a second fleet sees none of it |
| 1.14 | Security review follow-ups (2026-10-04): an events-service user, per-address login throttling, rotating administrator links, a quieter watchdog, a CSP, gift-unit firewall rules, socket timeouts, a narrow sudo rule, TLS for the setup page | 1–4 shipped; the rest before the first sale |

| 1.15 | Before the first sale: the services whose free terms are personal or non-commercial move to paid or commercial terms, or out (#62) | Every service a sold unit touches is used within its terms |
| 1.16 | Staged releases: a release reaches units in rings (the maintainer's own, family, early adopters, everyone), carries a signed rollout policy, can be paused, soaks a day on the canary before it widens; a release is built from a commit, never the working tree (#63) | A release held at ring 0 reaches RDU and no other unit; widening lets the next ring in |
| 1.17 | One cache for every radar: the network's aircraft (adsb.lol, on fixed 250 nm world discs so radars near each other share one fetch), routes (adsb.im) and owners (adsbdb) through the relay, for units that report and paired phones; a radar falls back to asking the services itself (#64) | Two radars looking at the same sky cost adsb.lol one fetch; a route asked by one radar costs nothing when another asks |
| 1.18 | Enrolment and quotas on the relay in place of the fixed unit cap: a radar joins only through an enrolment the maintainer controls, can be revoked, and has its share of events, pushes and the cache (#65) | The fixed cap gone; RDU enrolled without being touched |
| 1.19 | The relay at hundreds of radars: D1 read replicas, release files on R2, self-hosted map tiles, each at its trigger (#66) | Each done at its trigger, or deferred with a note |
| 1.20 | Fewer questions per radar: the ring comparison every 60 s or by feeding adsb.lol, the location poll only while a phone shares, a slower away poll in the app (#67) | Requests per day measured on RDU before and after |
## Phase 2: the pocket

| # | Item | Done when |
|---|---|---|
| 2.1 | Relay push: APNs token auth, fan-out, per-phone rules, rate limits | A test event reaches a real iPhone |
| 2.2 | Unit events: notable / emergency / low overhead / helicopter, decided on the unit and queued to the relay | Events arrive for real traffic at RDU |
| 2.3 | QR pairing on the device screen, and in the app | Pair and unpair with a phone, end to end |
| 2.4 | iOS app v2: notification rules, home and lock-screen widgets, Live Activity (inbound overhead), StandBy radar | Each feature working on a real phone |
| 2.5 | iOS app v2: away mode (community feed when not home), logbook/collection, AR sky view fed by the unit | Each feature working on a real phone |
| 2.7 | Location-aware app: a "You" marker relative to the antenna and a centre-on-me map; opt-in alerts for aircraft approaching the phone, its location end-to-end encrypted to the paired radar, which runs the prediction | Alerts for aircraft near the phone arrive on a real iPhone away from home, within the radar's coverage |
| 2.8 | App shows the network's aircraft too (the kiosk's "not heard" ghosts from `/network`), marked distinctly, with matching counts and the ODbL credit; setting to turn off | The app and the kiosk show the same sky on a real iPhone |
| 2.9 | Zoom in the app: pinch from 20 nm to about 1 nm, centred on the radar, the phone, or a followed aircraft; optionally the same on the kiosk, returning to full view by itself | A real aircraft sits on the right street at full zoom on a real iPhone |
| 2.10 | Logo and app icon: a round radar-sweep mark with a nod to altitude, legible at 16 px and in one colour; app icon (with dark and tinted variants), favicons, README header, repo social preview; logo files under their own notice, not MIT | Claude | The icon on a real iPhone home screen, and favicons everywhere the project shows its face |
| 2.11 | iPad app: a big radar with details, logbook and settings in a side panel; landscape and portrait; optional full-screen wall mode | On a real iPad, both orientations, nothing changed on the iPhone |
| 2.12 | Sky view tracks: a fading line where each aircraft has been and a dotted one where it's going, projected across the sky like the labels | Outdoors on a real iPhone, the lines follow the aircraft's real path |
| 2.13 | The app without a radar: live aircraft around the phone from adsb.lol (opt-in, rounded location), radar view and Sky view; alerts and the logbook stay radar-only | On a real iPhone with no radar: real aircraft around you; pairing later switches cleanly |
| 2.14 | Weather in the app: the kiosk's precipitation radar (RainViewer) and lightning (RealEarth) on the iPhone and iPad map, with the same switches | On a real iPhone, rain shows where the kiosk shows it |
| 2.15 | The kiosk's four colour themes in the app, Daylight by default (the kiosk's default too, from 2026-10-01), and a lighter map | Each theme matches the kiosk on a real iPhone; new installs open in Daylight |
| 2.16 | Alerts about where I am, the radar, or both: low overhead, helicopter and notable alerts measured from the phone's (encrypted) location as well as the antenna, by the owner's choice; within the radar's reach first | Away from home, a helicopter near the phone alerts "near you"; one over the house doesn't |
| 2.17 | Radar names: set during setup (default from the place), shown on the radar and carried to phones by the pairing link; a rename on the radar reaches phones that haven't named it themselves | A new radar pairs and shows its own name on the phone |
| 2.18 | Set up a new radar from the app: one QR code on the first-boot screen, the app joins the setup hotspot, sends home WiFi, the phone's location, time zone and name, and pairs in the same session; the browser and on-screen setup stay | A radar fresh from the factory image is set up and paired from the app alone |
| 2.19 | Public web address during first setup: nothing to type or renew; proposed: the relay mints a one-time `tag:stratoscan` Tailscale key for a radar being set up (Cloudflare Tunnel the alternative) | A radar set up from the app is reachable away from home, and can reach nothing on the tailnet |
| 2.20 | CarPlay, within what Apple allows without an entitlement: the approach Live Activity in CarPlay (iOS 26) and a text-only nearest-aircraft widget; alerts already reach CarPlay. No CarPlay app: a radar isn't one of Apple's CarPlay categories | In a CarPlay car or the CarPlay simulator: the Live Activity, the widget, an alert |
| 2.21 | One switch for the public network (adsb.lol): at home it fills in what the radar missed; away from the radar, beyond its range, or with no radar it shows the sky around you, by itself | Clear on a real iPhone at home, in flight and in another city |
| 2.22 | The map fills the screen; the ring is a line on it, not the edge of the picture | On a real iPhone and iPad |
| 2.23 | Pan and zoom anywhere: out past the ring to the region and the world, the network's aircraft around wherever the view is, a note where no radar data reaches; zoom at every scale; the kiosk gets the same touch pan and zoom | Swipe from RDU to New York on a real iPhone and see its traffic |
| 2.24 | Network aircraft you can see: a marker that reads on a phone in daylight, and on the kiosk | Beside heard aircraft on a real iPhone and on RDU |
| 2.25 | Trails in the app: where each aircraft has been, as on the kiosk | On a real iPhone |
| 2.26 | Alerts lead with what it is and where it's going: type and destination, then the callsign | A real alert on a real iPhone and Watch |
| 2.27 | Airline marks on labels and alerts: the airline's logo (fetched, never shipped) beside its name, so a commercial flight reads at a glance | In a label and a notification on a real iPhone |
| 2.28 | An alert opens the app on that aircraft, on the phone and the Watch | Tap a real alert on a real iPhone and Watch |

| 2.29 | The app through the relay's shared cache: the network's aircraft and routes (#68) | A view away from home loads from the cache on the owner's iPhone |
## Phase 3: the wrist

| # | Item | Done when |
|---|---|---|
| 3.1 | watchOS app: nearest-plane complication, glance radar | Complication live on a real Watch |
| 3.2 | Distinct wrist taps per alert type; Smart Stack Live Activity | Felt on a real Watch |
| 3.3 | "Look up" mode: a compass arrow toward the aircraft, and a countdown to overhead | Arrow points correctly outdoors |
| 3.4 | Approach compass on the phone as well as the Watch: where the aircraft is, where it is coming from and heading, in the notification, a north-up dial on the Live Activity, and a live compass in the app | The needle points at a real aircraft outdoors, on a phone and a Watch |

## Phase 4: delight

| # | Item | Done when |
|---|---|---|
| 4.1 | "What was that?": the unit keeps a rolling hour of tracks in RAM; tap to rewind and see what passed overhead | Rewind works on the kiosk and in the app |
| 4.2 | Notable aircraft from plane-alert-db (**license check first**) | Categories show and alert; notices updated |
| 4.3 | Empty-sky mode: clock, weather (source license checked), today's tally | Shows when nothing is in range, and leaves when traffic returns |
| 4.4 | Spoken announcements with offline TTS (Piper; **voice license checked**, permissive only) | Announces real traffic with no internet |
| 4.5 | Yearly "Wrapped" from the sighting store, shareable from the app | Generated from RDU's real history |
| 4.6 | Opt-in feeding to FlightAware / FR24 (their feeder licenses checked; precise-location sharing is explicit) | A unit feeds; the perk account activates |
| 4.7 | Quiet hours: silence the unit's alert sounds (chimes and speech) in a set window or sunset to sunrise; alerts still show on screen; emergencies can still sound | No sound inside the window on RDU, and sound returns on time |

## Phase 5: hardware v2

| # | Item | Done when |
|---|---|---|
| 5.1 | Rotating bezel (rotary encoder) for range and paging: enclosure redesign plus input handling | Turning the bezel changes range on the kiosk |
| 5.2 | Presence wake (LD2410 mmWave over UART, or PIR) replacing the 20-min idle timer | The screen wakes on approach and sleeps when the room is empty |
| 5.3 | 978 MHz UAT receiver for US units (dump978 into readsb) | UAT-only GA aircraft appear on the radar |
| 5.4 | Retro stand: ridges all the way round the plinth, standing out ~4 mm so the slicer supports them (as the case ribs were fixed) | Printed, with clean ridges on all four sides |
| 5.5 | Ambient light sensor: dim the display with the room, with an adjustable darkest level; a sensor window on both cases; first find a real backlight control (the panel's HID report 9, or DDC) | The display follows the room on RDU, down to the owner's floor |
| 5.6 | Key the back plate so it seats only upright (antenna at the top): a key on each shell's bore wall and a matching gap in one arc of the plate's locating rib; checks prove the seven wrong orientations are blocked | The plate goes in only upright, on both cases |
| 5.7 | Power: the display's power through the Pi's USB (Waveshare's bridge arrangement) plus the receiver puts the 5 V at the Pi at 4.9 V, with under-voltage warnings a few times an hour (71 in 29 h on RDU). A second inlet for the display now; a 12 V input with two regulators in the custom board | A week at `0x0` with no under-voltage messages |

## Work order (agreed 2026-09-30)

The open items are done in this order, chosen so the display is never
at risk for long.

**Rules**

- **One change to the unit at a time.** Each goes out as a small signed
  update, which rolls itself back if the screen stops painting. Leave 2–3 days
  on RDU between updates.
- **Add, then switch, then delete.** A new service runs alongside the old
  path with nothing depending on it. Screens move onto it one at a time,
  riskiest last. Old code goes only once the new path has proved itself.
- **The phone app goes first.** App changes cannot break the radar, so the
  app is where a new foundation is tested for real.
- **Hardware features change nothing without the part.** A unit without the
  sensor, bezel or receiver behaves exactly as it does today.

| Step | Items | Why here | Risk to the display |
|---|---|---|---|
| 0. Quick wins, anytime | 5.4 stand ridges, 5.6 back-plate key (CAD only); 4.7 quiet hours (off by default); 1.1 RTC cell and 1.7 radio recovery (confirm when the cell arrives or a hang happens) | Small and independent | None, or minimal |
| 1. Measure, then cool it down | **1.11** drawing cost | Its measurement script is how every later step is checked. It changes only drawing, not data | Low: screenshot comparison |
| 2. Core service, alongside | **1.8** core feed | Nothing reads it yet. Run for days with a live comparison against the kiosk's labels | None |
| 3. First user: the app | 2.8 network aircraft in the app | Real use; a bug only affects the app, which falls back to the old feed | None |
| 4. Alerts, trial run first | 1.10 `events.py` | Run the old and new logic side by side for days, logging disagreements, then switch | Alerts only |
| 5. The kiosk, last | 1.9 kiosk and public page | Riskiest change, after a week or more of the feed. Tried on the public page first; the old path kept for one release | Medium, contained |
| 6. App features | 2.9 zoom, the map part of 2.7, 3.4 (phone), the rest of 2.4/2.5, then the alerts part of 2.7 | Map parts are app-only; 3.4's direction of travel and 2.7's alerts need step 4 | None (app); low (alerts) |
| 7. Watch | 3.1 → 3.2 → 3.3 / 3.4 (Watch) | Straightforward once there is one feed to read | None |
| 8. Hardware v2 | 5.5 light sensor, 5.1 bezel, 5.2 presence, 5.3 978 MHz | As parts arrive: case, print, then software that changes nothing without the part. 5.5's first step (finding a real backlight control) is read-only and can be done anytime | Low |
| Factory image | 1.5 | Test-flash today's image soon, to prove the pipeline; rebuild after step 5 so gifted units carry the new architecture | None |

**Next, agreed 2026-10-03** (after the radar names and app setup work):
1. **Releases to RDU**: done 2026-10-04 (2026.10.04.1–.3), at the owner's call rather than 2–3 days apart: the polling fix, 2.18's radar side, 1.12, 1.13 and 1.9's switch to the core feed.
2. **1.12** visitor counts (#50).
3. **1.13** fleets (#51). Moved ahead of CarPlay because the family gift units need them.
4. **2.20** CarPlay (#49).

**Dependencies** (still true within the order above)

- 1.8 comes before 1.9, 1.10 and 2.8. 1.11 is independent.
- 2.7's alerts and 3.4's direction of travel need 1.10.
- 3.x needs 3.1 first; 3.4 extends 3.3.
- 1.5's final image comes after 1.9.
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

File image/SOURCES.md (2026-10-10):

# Source code for the StratoScan factory image

The factory image is Raspberry Pi OS with StratoScan installed on top. It
contains software under the GNU GPL and other copyleft licences. As its
distributor, the StratoScan project offers the corresponding source as
follows.

**StratoScan itself** (MIT): https://github.com/mferris/StratoScan, at the
project commit named in `MANIFEST.txt`.

**Attached to this release**, as built into the image:
- `src/readsb-source.tar.gz`: readsb (GPL-3.0-or-later), at the tag and commit
  in `MANIFEST.txt`.
- `src/tar1090-source.tar.gz`: tar1090 (GPL-2.0-or-later), at the commit in
  `MANIFEST.txt`.
- `src/dump978-source.tar.gz`: dump978 (GPL-2.0-or-later), the 978 MHz
  decoder, at the tag in `MANIFEST.txt`. Upstream is
  https://github.com/flightaware/dump978.
- `src/piper_tts-*.tar.gz`: Piper TTS (GPL-3.0-or-later), the source release
  of the version in `MANIFEST.txt`. Upstream is
  https://github.com/OHF-voice/piper1-gpl.

**Raspberry Pi OS and Debian packages:** every package in the image, with its
exact version, is listed in `MANIFEST.txt`. Their source packages are
published by their distributors at https://archive.raspberrypi.com/debian/
and https://deb.debian.org/debian/ (older versions at
https://snapshot.debian.org/). The base image is Raspberry Pi's own, named in
`MANIFEST.txt`.

**Written offer.** For at least three years from the date of this release, the
StratoScan project will provide, on request, a complete machine-readable copy
of the corresponding source for any GPL- or LGPL-licensed software in this
image, for no more than the cost of physically performing the distribution.
Ask through https://github.com/mferris/StratoScan/issues.

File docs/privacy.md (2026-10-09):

# StratoScan privacy policy

*Last updated 2026-09-29.*

StratoScan is an open-source radar for the aircraft flying over your home,
built around a receiver you own. This page covers the StratoScan radar, the
StratoScan iPhone app, and the small StratoScan relay service that connects them.
The code for all three is public at
[github.com/mferris/StratoScan](https://github.com/mferris/StratoScan).

## The short version

- Your radar's exact location never leaves it.
- The app uses your phone's location only if you ask it to show you on the
  radar, and only on the phone. One exception: with the public network on
  (Settings › Public network, one switch, on by default), away from your
  radar, beyond its 20 nm, or with no radar, the app asks adsb.lol for the
  aircraft around you, with your location rounded to about 5 km. It doesn't
  track you and shows no ads.
- The relay keeps the minimum it needs to deliver alerts, and deletes it
  when it's no longer needed.

## The radar

The radar receives aircraft broadcasts with its own antenna and keeps that
data on the device. It sends data off the device only for features you
turn on:
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

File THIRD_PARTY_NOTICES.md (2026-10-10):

# Third-party notices

StratoScan's own code, enclosure designs and documentation are MIT-licensed
(see [LICENSE](LICENSE)). This file lists everything else the project ships
or uses, under what terms, and how each obligation is met. Reviewed
2026-09-27 and audited 2026-10-09 against each service's current terms;
re-check it whenever a dependency or data source is added.

## Shipped in this repository

| Component | Where | License | How the obligation is met |
|---|---|---|---|
| [MapLibre GL JS](https://github.com/maplibre/maplibre-gl-js) 5.24.0 | `vendor/maplibre-gl.js`, `.css` | BSD-3-Clause | The license header is kept intact at the top of the vendored file. |
| [MapLibre Native (iOS distribution)](https://github.com/maplibre/maplibre-gl-native-distribution) | `ios/` (Swift package, resolved at build time) | BSD-2-Clause | Not vendored. The iOS app's About/credits must carry its notice when the app ships. |
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

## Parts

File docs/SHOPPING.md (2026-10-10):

# Shopping list

Everything you need to build a StratoScan from nothing: the radar, the case, and
optionally the iPhone app. After that is what is still to come for the
features in progress.

Claude keeps this current. A part is added when the design or an issue first
needs one, and moved along as it is ordered and fitted.

*Last updated 2026-10-10. Prices are approximate, in US dollars.*

## Build one StratoScan

### 1. The radar: receiver, computer, power

You need all of these. They also make a working radar on their own, in a web
browser, before any display or case.

| Part | Qty | Approx. | Notes |
|---|---|---|---|
| [Raspberry Pi 5, 4 GB](https://www.raspberrypi.com/products/raspberry-pi-5/) (or 8 GB) | 1 | $85 (8 GB: $130) | Measured on a radar after a day running everything (2026-10-04): 2.3 GB used, no swap. 4 GB leaves 1.6 GB spare; 8 GB leaves 5.7 GB nothing uses. 2 GB is too small. Prices rose sharply in 2026 |
| [Raspberry Pi Active Cooler](https://www.raspberrypi.com/products/active-cooler/) | 1 | $5 | Needed: it drives the radar full-time, and the case holds heat in. The FlyCatcher sits above it on tall standoffs |
| [Raspberry Pi RTC battery](https://www.raspberrypi.com/products/rtc-battery/) (ML-2020, rechargeable) | 1 | $5 | Keeps the clock through power cuts. Plugs into the Pi 5's BAT socket; the installer enables charging with `RTC_RECHARGEABLE=1`. **Never enable charging for a CR2032** |
| [Raspberry Pi 27 W USB-C power supply](https://www.raspberrypi.com/products/27w-power-supply/) | 1 | $12 | **Use this one, not a generic USB-C supply.** A weaker supply causes under-voltage and USB drop-outs. A generic 5 V supply tried on RDU (2026-10-10) held its voltage but put radio noise on it: with the FlyCatcher's amplifier on, the noise floor rose 9 dB and the radar heard 2 of 8 nearby aircraft instead of 7 of 10. The occasional under-voltage dips on this supply are the display drawing through the Pi ([#53](https://github.com/mferris/StratoScan/issues/53)), not the supply |
| High-endurance microSD card, 64–128 GB | 1 | $15–25 | For example SanDisk High Endurance or Samsung PRO Endurance. Writes measure about 2.25 GB/day, fine for about 10 years on an endurance card |
| ADS-B receiver: **[Nooelec FlyCatcher](https://www.nooelec.com/store/flycatcher.html)** | 1 | $110 | What RDU uses, and the choice for every unit (2026-10-04): it mounts on the Pi as a HAT, which the cases and the twin antenna mount are built around, and it has a 978 MHz input for later. The [FlightAware Pro Stick Plus](https://flightaware.store/products/pro-stick-plus) ($45) hears the same from a USB port, for anyone building a kit on a budget |
| M2.5 standoffs and screws for the FlyCatcher, tall enough to clear the Active Cooler (~16–20 mm) | 4 | $0–4 | Check the FlyCatcher's box first; most HATs include a set, but not always tall enough for the cooler |
| Short **one-piece** micro-USB to USB-A cable with a right-angle USB-A end, 15–20 cm (for example the CableCreation 2-pack) | 1 | $5 | FlyCatcher to the Pi. The angled plug clears the side speakers; the straight jumper in the FlyCatcher's box doesn't. One moulded cable, never an adapter (see below) |
| [NooElec ADS-B Discovery 5 dBi antenna bundle](https://www.amazon.com/NooElec-ADS-B-Discovery-Antenna-Bundle/dp/B01J9DH9U2) | 1 | $25 | Hinged whips for 1090 and 978 MHz; the FlyCatcher has an input for each. Its small right-angle pigtails are MCX, for USB-stick receivers, and aren't needed. **Placement matters more than any part:** a window or outdoor spot heard 14 aircraft where an indoor puck heard 1 |

**Connect the receiver directly.** The FlyCatcher mounts on the Pi as a HAT,
but its data still goes over USB: use the short USB-A to micro-USB jumper that
comes with it, plugged straight into one of the Pi's ports. **Don't add a
USB adapter or extension** (a right-angle USB-A adapter, a panel-mount
passthrough). On RDU a right-angle adapter made the receiver drop off USB
dozens of times an evening ("Cannot enable. Maybe the USB cable is bad?");
the screen showed NO SIGNAL each time until the watchdog reset it. With the
adapter removed, the drop-outs stopped.

**If the speakers won't fit beside it** (2026-10-02): the straight USB-A plug in
the Pi, plus the curve of its cable, sticks out about 35–45 mm past the Pi's
edge, where the cases' side speakers sit. The fix to try first is a **one-piece
short micro-USB to USB-A cable, about 15–20 cm, with a right-angle (90°) USB-A
end**. It's moulded as one part, so unlike the adapter it adds no extra
connection. Angled ends come as "up" or "down"; which one turns the cable toward
the back plate depends on which of the Pi's ports it's in, so a pair of each is
the easy way (about $8–12). If the drop-outs come back with it, go back to the
FlyCatcher's own cable: the watchdog still recovers the receiver either way.

**Check first:** set up the Pi, receiver and antenna, and confirm real
aircraft appear before you buy the display. See
[project-spec.md](project-spec.md), "Purchase Plan".

### 2. The display

| Part | Qty | Approx. | Notes |
|---|---|---|---|
| [Waveshare 7″ round LCD, 1080×1080](https://www.waveshare.com/7inch-1080x1080-lcd.htm) | 1 | $160 | HDMI video plus USB touch. The cases are designed around it |
| Micro-HDMI to HDMI cable, short (30 cm or less) | 1 | $8 | The Pi 5 has **micro**-HDMI ports. A slim or right-angle cable is easier to fit in the case |
| USB-A to USB-C **data** cable, short | 1 | $6 | Carries the touch signal from the panel to the Pi. **Charge-only cables leave touch dead** while the picture still works |
| Waveshare 8 Ω 5 W speaker pair | 1 pair | $10 | For the alert chimes and spoken announcements. They connect to the panel's driver board, and the sound travels over HDMI. The cases have brackets for them |
| Pre-crimped 1.25 mm 4-pin cable (sold as "Micro JST 1.25" or "Molex PicoBlade compatible"), 10–15 cm | 1 (packs of 10) | $8 a pack | The panel's speaker socket is this plug. Solder its wires to the speaker leads and heat-shrink them: hand-crimped plugs come apart |
| Pi mounting to the display's back: 4 × M2.5 standoffs and screws | 4 | included | In the display's box |

### 3. The case (3D printed)

Two designs, both in [`enclosure/`](../enclosure/):
- **Retro:** a ship's-instrument look.
- **Kitten:** a cat with the display as its face.

They share the back plate and antenna mount.

| Part | Qty | Approx. | Notes |
|---|---|---|---|
| SMA male to SMA female **bulkhead** jumper, RG316, ~30 cm (12") | 2 | ~$8–10 a pair | One per antenna, for the twin antenna mount: the bulkhead end in the mount, the plug on the FlyCatcher. The mount comes in two styles for the bulkhead's hex body, 8 mm (`antenna_mount_twin_8`) or 11 mm (`_11`); both are 6.35 mm barrels. Buy two of the same kind. **SMA, not RP-SMA** (RP-SMA has no centre pin) |
| Filament: **ASA** recommended | ~1 kg | $25–30 | Retro: one colour. Kitten: two colours for the head, more for the stand; see its README. **Why ASA:** a radar usually sits in a window for reception, where sun on a dark case can pass 60 °C. PLA starts to soften around 55–60 °C, so it's fine for a test fit but can sag or warp in a sunny window. PETG holds to about 75–80 °C; ASA and ABS hold to about 95–100 °C. ASA also doesn't yellow or go brittle in sunlight, and prints as cleanly as ABS. It needs an enclosed printer (the Bambu H2D is one). On a two-nozzle printer, print the support *interface* in a material that won't bond, so supports lift off cleanly. **For ASA/ABS: Bambu Support for ABS** (Bambu's store only) **or HIPS** (eSUN, on Amazon). Bambu Studio refuses PETG with ASA on one plate (low- and high-temperature filaments can't mix). Without either, ASA can support itself with a 0.2 mm top Z gap. For PETG: PLA, or Bambu Support for PLA/PETG. **Bought on Amazon:** Polymaker ASA, Dark Grey Green for the retro case (Grey if it sits in full sun) |
| Heat-set inserts and screws | see the table below | $10 in kits | Every hole, counted from the design files |
| Panel-mount USB-C extension cable, **rated 5 A / 100 W (e-marked)**, with two M3 screw holes 16.5 mm apart | 1 | $10–15 | Brings power in through the back plate. **The rating matters:** a thin extension dropped the Pi's 5 V supply to 4.96 V and caused under-voltage several times an hour, gone when the supply was plugged straight in (5.08 V). The cutout is 11 × 6.5 mm; print `usbc_gauge` to test-fit a different connector first |
| **Antenna mounting, choose one:** | | | |
| · puck socket (`antenna_mount`) | — | — | Holds FlightAware's desktop puck antenna directly. Nothing extra to buy |
| · SMA jack (`antenna_mount_sma`), **recommended** | | | Takes any SMA antenna, such as the whip above, or coax to a better spot |
| SMA female-to-female bulkhead barrel, with O-ring and nut | 1 | $8 (2-pack) | For example [onelinkmore](https://www.amazon.com/onelinkmore-Female-Waterproof-Bulkhead-Adapter/dp/B0GTV677Z4). **Not RP-SMA** |
| SMA male-to-male RG316 jumper, about 20 cm | 1 | $8 (2-pack) | Barrel to receiver. For example [HCFeng](https://www.amazon.com/HCFeng-Extension-Coaxail-coaxial-Assembly/dp/B0C2KQB1H3). **Not RP-SMA** |

**Every screw and insert, per hole** (counted from the design files, 2026-10-04). Inserts are brass heat-set, M3 ones 4.5 mm across the knurl (the Kadrick M2–M5 kit fits); holes are 4.0 mm.

| Where | Holes | Insert | Screw | Note |
|---|---|---|---|---|
| Front: the trim and the retainer, into the shell's front posts | 8 (the kitten uses 7) | M3 × 5 | M3 × 14 socket head | Press from the front, flush with the shelf |
| Back plate, into the shell's back posts | 8 | M3 × 6 | M3 × 8 | Press from the back face |
| Antenna mount (any of the three), into its flange | 3 | M3 × 5 | M3 × 8 | The screws come from inside the case, through the plate |
| USB-C panel connector, to the back plate | 2 | none | M3 × 6 with nuts, or the connector's own | Holes 16.5 mm apart; the heads sit in the 2 mm pocket round the connector (plates printed from 2026-10-10 on) |
| Speakers, to their brackets | 4 each, 8 | optional M2 × 3 | M2 × 6, or M2 self-tapping | 2.6 mm pilots for the self-tappers; drill to 3.0 for inserts |
| Pi, to the display's back | 4 | none | M2.5 × 6 and standoffs, in the display's box | |
| FlyCatcher, onto the Pi | 4 | none | M2.5 standoffs, ~16–20 mm, and screws | tall enough to clear the cooler |
| Twin antenna mount's two SMA bulkheads | 2 | none | the jumpers' own nuts | an 8 mm (5/16") open-ended spanner, a quarter to half a turn past finger tight |
| Twin antenna mount's cover | 5 | M2 × 3 | M2 × 6 | 3.0 mm holes for a 3.2 mm knurl (measure the kit's) |
| **To buy per radar** | | **19 × M3 (11 of 5 mm, 8 of 6 mm); 5 × M2; 8 × M2 optional** | **8 × M3×14, 11 × M3×8, 2 × M3×6 (+2 nuts), 13 × M2×6, 8 × M2.5** | one M3 kit and one M2/M2.5 kit cover several radars |

**Everything for one radar, totalled:** about **$500** in parts with the 4 GB Pi (about $545 with 8 GB), of which the display is $160, the FlyCatcher $110 and the Pi $85; the forty-odd dollars of cables, standoffs, cells and fasteners are easy to forget and are all listed above. Printer time: about 20 hours; filament about 700 g.

**Tools (once):**
- a 3D printer (designed on a Bambu Lab printer, with an AMS for the kitten's colours);
- a soldering iron with a heat-set insert tip, and a flat piece of metal to press inserts flush;
- hex keys (1.5, 2 and 2.5 mm), an 8 mm (5/16") open-ended spanner for the antenna jacks' nuts, a small Phillips, a microSD reader;
- glue stick for the print bed; hot glue or Kapton tape for the speaker plug's strain relief; heat-shrink; a few zip ties.

### 4. Optional

| Part | For | Approx. | Notes |
|---|---|---|---|
| Rubber feet for the stand | Desk use | $2 | Self-adhesive, 4 |
| Wall anchors and screws | Wall mounting | — | Both cases also have a desk stand |

### 5. The iPhone app

| Need | Notes |
|---|---|
| An iPhone on iOS 17.2 or later | For the app, widget, alerts and Live Activity |
| An Apple Watch, Series 5 / SE or later | Only for the Watch app, still to come (Phase 3). Earlier models have no compass |
| **To build the app yourself:** a Mac with Xcode, and the Apple Developer Program ($99/yr) | Only needed to build and install the app yourself |
| **To run your own relay (push alerts):** a free Cloudflare account | See [relay/README.md](../relay/README.md) |

**Rough total for one unit:** about $400, plus filament and the phone you
already have.

## Coming later

These are for roadmap items that aren't built yet. **Wait until each item
starts before buying:** the exact part may change.

| Part | For | Approx. |
|---|---|---|
| [Adafruit VEML7700 lux sensor (#4162)](https://www.adafruit.com/product/4162) and [STEMMA QT cable (#4397)](https://www.adafruit.com/product/4397) | [5.5 light sensor](https://github.com/mferris/StratoScan/issues/27) | $6 |
| Rotary encoder | [5.1 rotating bezel](https://github.com/mferris/StratoScan/issues/22) | ~$5 |
| Presence sensor: LD2410 mmWave, or a PIR | [5.2 presence wake](https://github.com/mferris/StratoScan/issues/23) | ~$10 |
| 978 MHz receiver: nothing to buy. The FlyCatcher's second radio is the 978 MHz one, and the Discovery bundle above has the 978 whip; decoded since 2026-10-10 | [5.3 UAT receiver, US only](https://github.com/mferris/StratoScan/issues/24) | $0 |

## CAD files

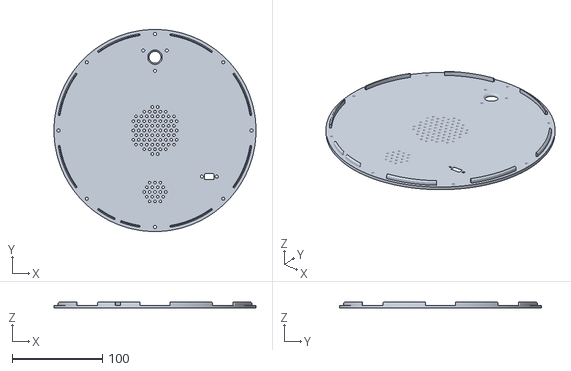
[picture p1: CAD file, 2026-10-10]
enclosure/Kitten Enclosure Two-Tone/back_plate.stl
223.3 x 223.3 x 7.00

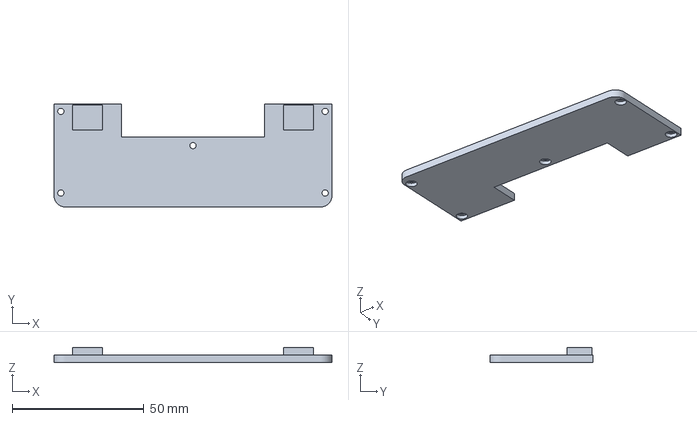
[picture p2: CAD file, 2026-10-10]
enclosure/Kitten Enclosure Two-Tone/antenna_mount_twin_cover_11_twotone.3mf
105.6 x 39.1 x 5.86 mm

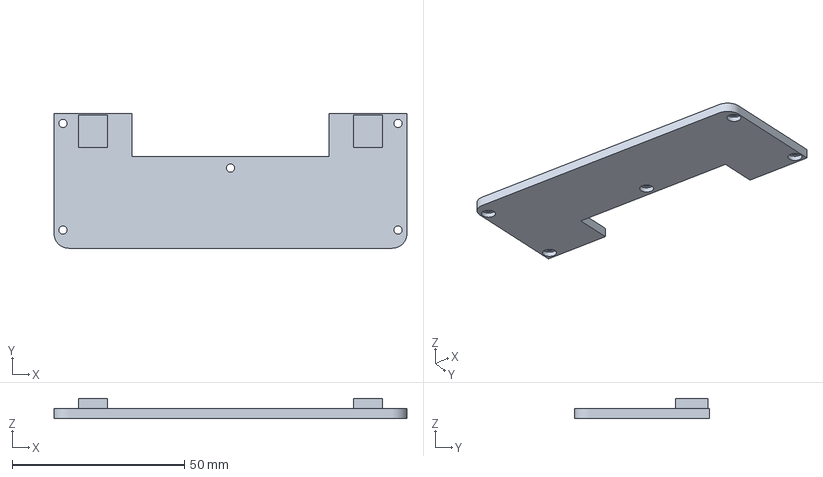
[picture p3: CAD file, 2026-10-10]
enclosure/Retro Radar Enclosure/antenna_mount_twin_cover_8_twotone.3mf
102.6 x 39.1 x 5.86 mm

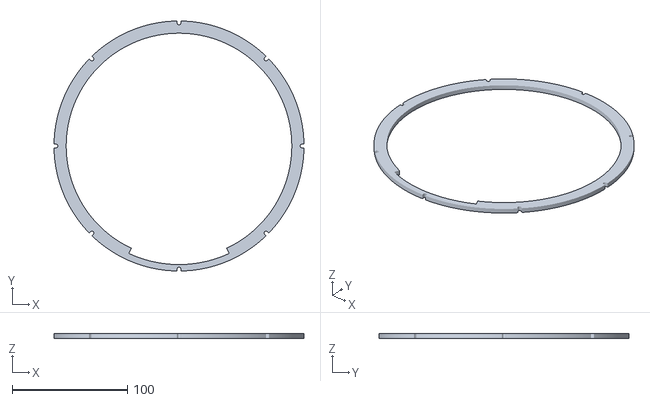
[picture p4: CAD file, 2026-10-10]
enclosure/Kitten Enclosure Two-Tone/retainer.stl
216.5 x 216.5 x 4.00

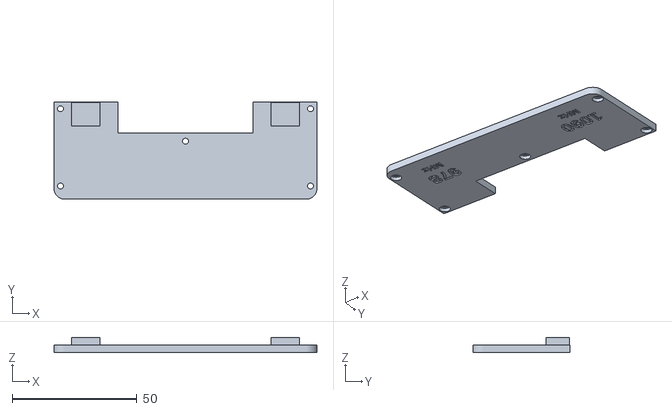
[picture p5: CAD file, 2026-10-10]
enclosure/Retro Radar Enclosure/antenna_mount_twin_cover_11.stl
105.6 x 39.1 x 5.86

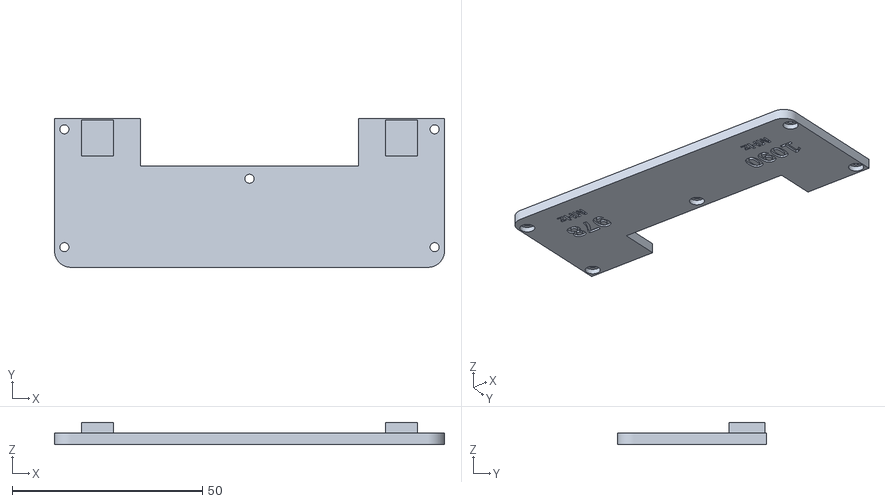
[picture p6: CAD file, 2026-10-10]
enclosure/Retro Radar Enclosure/antenna_mount_twin_cover_8.stl
102.6 x 39.1 x 5.86

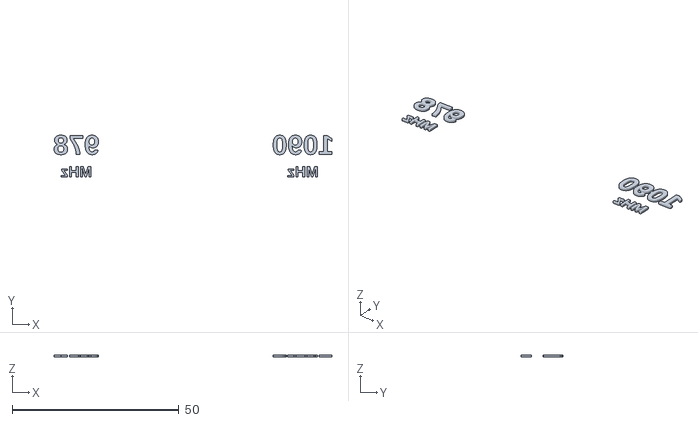
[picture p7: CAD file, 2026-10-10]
enclosure/Kitten Enclosure Two-Tone/antenna_mount_twin_cover_text_11.stl
83.4 x 12.5 x 0.6

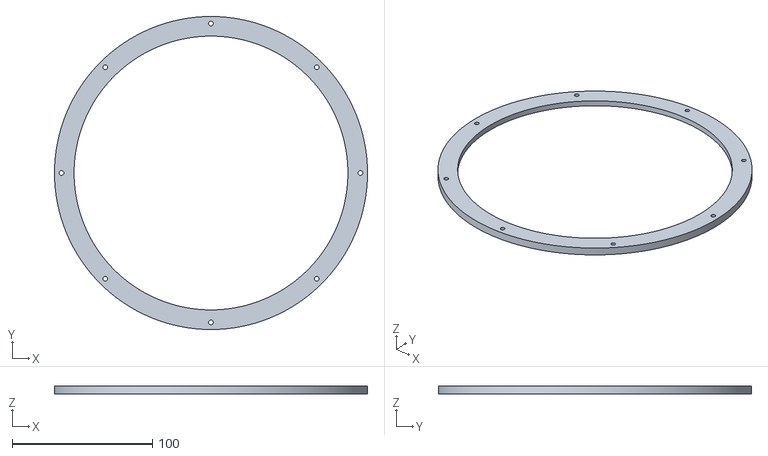
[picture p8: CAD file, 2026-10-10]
enclosure/Retro Radar Enclosure/front_trim.stl
223.3 x 223.3 x 5.62

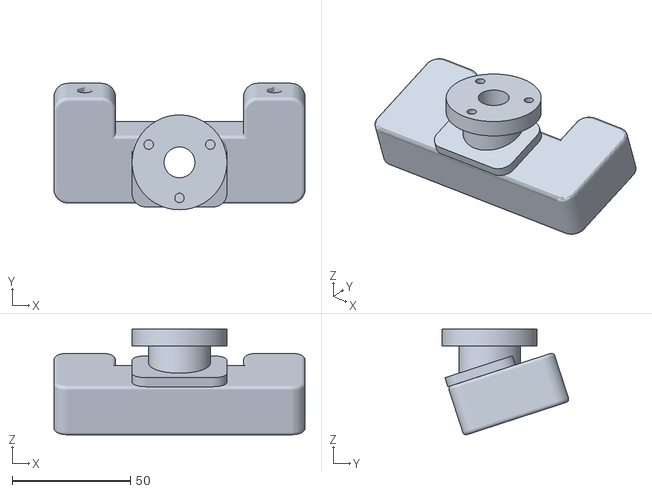
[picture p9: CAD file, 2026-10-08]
enclosure/Retro Radar Enclosure/antenna_mount_twin_8.stl
105.9 x 53.4 x 44.6

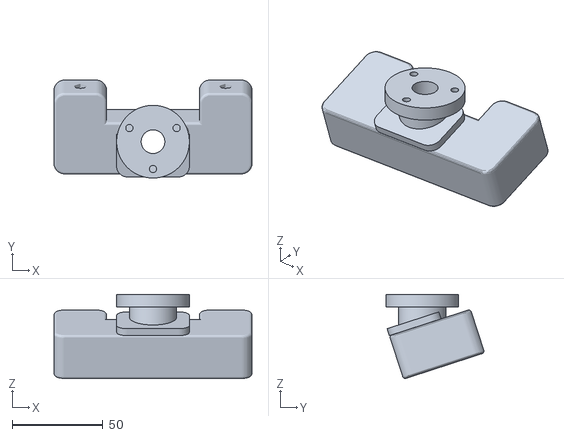
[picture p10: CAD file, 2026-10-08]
enclosure/Retro Radar Enclosure/antenna_mount_twin_11.stl
108.9 x 53.9 x 46.2

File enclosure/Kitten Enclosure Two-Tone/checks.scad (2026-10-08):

// Fit checks for the two-tone kitten enclosure. Each target is an
// INTERSECTION (or a DIFFERENCE) that must come out with no real volume.
//
// Not "empty": run these with `sh run-checks.sh`, which measures the volume
// of what each produces. Wherever two parts share a surface -- which is the
// whole point of the colour split -- a boolean leaves a zero-thickness film
// along that boundary, with thousands of facets and no volume. Judging by
// facet count calls a correct model broken.
//
// Lives beside the design on purpose: `use <>` resolves
// relative to the file that contains it, so a copy in /tmp silently finds
// nothing and every check "passes" against empty geometry.
use <kitten-enclosure-twotone.scad>
check = "none";
// front heat-set inserts (restated): shelf top face, insert length, hole
fi_top = 57; fi_len = 5; fi_hole = 4.0;
// Must match the design's resolution or the checks validate different
// geometry from what gets exported. This said $fn=96 while the design moved
// to adaptive $fa/$fs, and the giveaway was the canary reporting volume to
// the milligram across a resolution change that should have moved it.
$fs = 0.4;
$fa = 0.5;
outer_dia=223.34; shell_depth=61; wall=3; lip_height=6; shelf_h=2;
screw_r=106.67; n_screws=8; post_od=9;
screw_clear_dia=3.4; nose_angle=270; front_trim_h=4;
back_plate_t=3; ant_mount_y=81; ant_stub_len=30; ant_barrel_len=14; ant_socket_dia=33; ant_socket_depth=8;
speaker_bracket_depth=15; speaker_d=45;
cradle_id=outer_dia+2; cradle_od=cradle_id+26; arm_gap=26; arm_w=16;
base_h=16; stand_angle=18;
// Restated because `use <>` imports modules and functions but NOT variables.
// These must track the design file: paws and tail are bigger here than in
// the single-colour version, and a stale value here would check the old
// geometry and pass.
paw_x=46; paw_h=18;
n_toes=4; toe_dia=13.5; toe_splay=21; claw_len=6.5;
ant_conn_dia=9.15; ant_boss_dia=48; ant_socket_lead=1.2;
// Measured off the antenna: 31.25mm across the flared bottom, its widest
// point. ant_relief_* is the clear space under the socket floor for the
// connector, which is what was actually stopping the base from seating.
ant_base_dia=31.25; ant_relief_dia=18; ant_relief_h=4;
ant_cable_slot_w=7; ant_cable_exit_h=7.98; ant_flange_t=7; ant_flange_insert_d=5.5;

// The SMA bulkhead variant. Restated here for the same reason as everything
// above: `use <>` brings in modules, not variables, so a check that names one
// of these directly needs its own copy.
ant_sma_hole=6.5; ant_sma_panel_t=3; ant_sma_cavity=14; ant_twin_cover_t=3;
ant_sma_boss_d=22; ant_sma_boss_h=10; ant_sma_cavity_d=25;

// The back-plate features added with the locating lip. Restated here for the
// same reason as everything above: `use <>` brings in modules, never values.
back_lip_h=4; back_lip_t=2; back_lip_gap=0.35; back_lip_skip=9;
back_post_h=9; ant_bolt_pcd=30; n_ant_bolts=3; ant_flange_d=40;
usbc_cut_pos=[60,-14]; usbc_cut_w=11.0; usbc_cut_h=6.5; usbc_screw_pitch=16.5; usbc_screw_dia=3.4;
mount_hole_x=58; mount_hole_y=49;

if (check=="ear_vs_post") {
  intersection() {
    ears_hollow();
    for (i=[0:n_screws-1]) { a=i*360/n_screws;
      translate([screw_r*cos(a), screw_r*sin(a), shell_depth-lip_height-1])
        cylinder(d=post_od+1, h=shelf_h+3); }
  }
}
// Does the inner-ear dish reach an insert post? That is the thing that
// actually matters. An earlier version of this check probed the whole rim
// band with a +0.01 fudge on its outer diameter, which reported a 0.06mm
// "interference" that was nothing but the 96-gon's flats dipping inside
// the true radius at the shared boundary -- a measurement artifact, not
// geometry. Posts stop at r=111.17, half a millimetre inside the wall, so
// probing them directly has real clearance and no boundary ambiguity.
if (check=="recess_vs_post") {
  intersection() {
    inner_ear_recess();
    for (i=[0:n_screws-1]) { a=i*360/n_screws;
      translate([screw_r*cos(a), screw_r*sin(a), shell_depth-lip_height-1])
        cylinder(d=post_od, h=lip_height+2); }
  }
}
else if (check=="whisker_through") {
  r_mount = outer_dia/2 - wall - speaker_bracket_depth;
  zc = (shell_depth-speaker_d)/2 + speaker_d/2;
  intersection() {
    shell();
    translate([r_mount, 0, zc]) rotate([0,90,0]) cylinder(d=1.2, h=speaker_bracket_depth+wall+2, $fn=8);
  }
}
else if (check=="head_in_cradle") {
  arm_lift = base_h + cradle_od/2 - 3;
  intersection() {
    stand();
    translate([0,0,arm_lift]) rotate([90-stand_angle,0,0]) translate([0,0,-shell_depth/2]) shell();
  }
}
// The tail now rests ON the right paw on purpose, so "must not touch" is
// the wrong assertion. What must not happen is the tail passing THROUGH the
// foot at pad height, which reads as one fused lump instead of a tail
// draped over a paw. So: it may meet the paw's upper half, but must not
// intrude into the lower half at all.
else if (check=="tail_over_paw") {
  intersection() {
    tail();
    intersection() {
      union() { paw(paw_x); paw(-paw_x); }
      // the paw's lower half, which scales with the paw
      translate([-200,-200,-50]) cube([400,400,50 + paw_h*0.7]);
    }
  }
}
// It should still be nowhere near the LEFT paw.
else if (check=="tail_vs_left_paw") {
  intersection() { tail(); paw(-paw_x); }
}
// The tail must also stay under the cradled head, whose underside comes
// down to about z=27.
else if (check=="tail_vs_head") {
  arm_lift = base_h + cradle_od/2 - 3;
  intersection() {
    tail();
    translate([0,0,arm_lift]) rotate([90-stand_angle,0,0]) translate([0,0,-shell_depth/2]) shell();
  }
}
// Paws must not reach the head either, now that they are taller.
else if (check=="paws_vs_head") {
  arm_lift = base_h + cradle_od/2 - 3;
  intersection() {
    union() { paw(paw_x); paw(-paw_x); }
    translate([0,0,arm_lift]) rotate([90-stand_angle,0,0]) translate([0,0,-shell_depth/2]) shell();
  }
}
else if (check=="ears_vs_cradle") {
  arm_lift = base_h + cradle_od/2 - 3;
  intersection() {
    stand();
    translate([0,0,arm_lift]) rotate([90-stand_angle,0,0]) translate([0,0,-shell_depth/2]) ears_solid();
  }
}
// The five colour bodies must add back up to exactly the one-piece stand,
// with nothing left over and nothing missing. Both directions are checked
// because each catches a different mistake: material_lost finds a region no
// part claims (a hole in the print), material_gained finds a region two
// parts both claim (an overlap, where which colour wins depends on the
// slicer's load order).
else if (check=="material_lost") {
  difference() { stand(); stand_colour_parts(); }
}
else if (check=="material_gained") {
  difference() { stand_colour_parts(); stand(); }
}
// Overlap between any two coloured bodies, checked pairwise rather than
// against the whole, since a body cannot overlap itself and the union above
// would hide a mutual overlap inside the total.
else if (check=="paws_vs_toes")     { intersection() { part_stand_paws(); part_stand_toes(); } }
// The claws are a colour body like any other, so they overlap the toes they
// grow out of by colour_overlap and must not share a surface with them.
else if (check=="claws_vs_toes")    { intersection() { part_stand_toes(); part_stand_claws(); } }
// ...and they must actually STAND OFF the toes. A claw entirely buried in
// its toe still passes every seam and volume check above while being
// invisible on the print -- which is exactly what the grooves-as-nails
// problem looked like. Positive control: material must exist forward of the
// toes' own envelope.
else if (check=="claws_stand_proud") {
  difference() {
    union() { part_stand_claws(); }
    union() { paw_toes(paw_x); paw_toes(-paw_x); paw_pad(paw_x); paw_pad(-paw_x); }
  }
}
// A claw that reaches the desk plane would carry the stand's weight on four
// points per paw and rock. Nothing below z=0.6.
else if (check=="claws_off_the_desk") {
  intersection() {
    part_stand_claws();
    translate([-300,-300,-300]) cube([600,600,300.6]);
  }
}
else if (check=="paws_vs_tail")     { intersection() { part_stand_paws(); part_stand_tail(); } }
else if (check=="body_vs_paws")     { intersection() { part_stand_body(); part_stand_paws(); } }
else if (check=="tail_vs_tip")      { intersection() { part_stand_tail(); part_stand_tail_tip(); } }
// The whiskers have to sit in the band between the nose and the screw holes
// either side of it. The first version of them missed by ninety degrees and
// printed before anyone noticed, so both ends of that band are now pinned.
else if (check=="whisker_vs_screws") {
  intersection() {
    whisker_grooves();
    for (i=[0:n_screws-1]) { a=i*360/n_screws;
      translate([screw_r*cos(a), screw_r*sin(a), -5])
        cylinder(d=screw_clear_dia, h=20); }
  }
}
else if (check=="whisker_vs_nose") {
  intersection() { whisker_grooves(); nose(); }
}
// ...and that they are actually beside the NOSE. An intersection can only
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

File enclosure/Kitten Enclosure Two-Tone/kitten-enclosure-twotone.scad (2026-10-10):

// ============================================================
// StratoScan — KITTEN enclosure
//
// Same radar, same hardware, different animal. Every dimension that
// touches a physical part is copied verbatim from the Retro Radar
// build, which is printed and validated: the 203.34mm round panel, the
// Pi's 58x49 standoff pattern, the two 100x45mm speakers, the 30mm fan,
// the M3 screw ring, the USB-C and SMA bulkheads. Only the SHAPE is new.
//
// The design idea is that the round display IS the face. Everything
// else follows from that: ears above it, whiskers where the speakers
// already were, a nose on the bezel, and a stand shaped like a sitting
// cat with front paws and a curled tail.
//
// Parts (print all four):
//   1. front_trim — the face: bezel ring, nose, whisker grooves
//   2. retainer   — ring behind the glass (identical to the retro part)
//   3. shell      — the head: body cylinder + ears, all the internals
//   4. stand      — sitting body: plinth, cradle, paws, tail
//
// Assembly is unchanged: front_trim -> [glass] -> retainer -> shell,
// 8 M3 screws through the trim and retainer into heat-set inserts in
// the shell's posts. The head then sets down into the stand.
// ============================================================

part = "preview";  // front_trim | retainer | shell | stand | preview | exploded | test_ear
// ---- Curve resolution ------------------------------------------------
// $fa/$fs rather than a fixed $fn, which is what this was before.
//
// A fixed count makes the flats grow with the feature, so the biggest, most
// looked-at surfaces come out roughest: at $fn=96 the head's 223mm rim had
// 7.3mm flats and the cradle 8.2mm, while every 3mm screw hole also got 96
// sides it had no use for. $fs caps the chord -- the width of one flat,
// which is what the eye reads as faceting -- so a big curve gets the facets
// and a small hole does not.
//
// 0.4mm is one extrusion width: below that the printer cannot reproduce the
// difference. $fa then bounds the count on very large radii. Together these
// give the head 0.97mm flats for about a quarter more mesh than $fn=96 --
// cheaper than raising $fn would have been, because the savings on small
// holes pay for the big surfaces.
$fs = 0.4;   // max chord in mm
$fa = 0.5;   // max degrees per fragment

// ============================================================
// HARDWARE CONTRACT — do not change these to suit the styling.
// They describe real parts. Copied from the Retro Radar build.
// ============================================================
panel_diameter    = 203.34;
panel_active      = 178.15;
panel_glass_depth = 6.45;   // whole panel module (preview only, NOT the rabbet)
glass_thickness   = 1.62;   // the glass sheet alone — this is what the rabbet spans

pcb_w = 108; pcb_h = 72;
mount_hole_x = 58; mount_hole_y = 49;

// ---------- MEASURE ON YOUR ASSEMBLED UNIT, THEN SET ----------
// 42 -> 56 gave the side-mounted speakers (45mm along this axis) room
// without touching the Pi/heatsink stack. 56 -> 61 is the FlyCatcher: it
// is a HAT, so it stacks onto the BACK of the Pi, and the Pi hangs off the
// LCD panel at the front -- which puts the HAT's pre-amp slide switches
// facing the back plate. At 56 they fouled it as the plate was screwed
// down, which is the worst kind of interference: everything appears to fit
// until the last two turns, and then it is loading the board.
//
// Deeper is nearly free here -- a bigger box, more filament, a longer
// print -- and too shallow is a case that cannot be closed without
// pressing on a switch. Measure YOUR stack before printing: this is the
// one number that has had to move every time the internals changed.
shell_depth_note = "56 -> 61 for the FlyCatcher HAT's pre-amp switches";
shell_depth = 61;           // front glass face to back of the tallest component
rim = 10;
outer_dia = panel_diameter + 2*rim;   // 223.34
wall = 3;

glass_overlap     = 4;
retention_opening = panel_diameter - 2*glass_overlap;
front_trim_h  = 4;
retainer_h    = 4;
// Radial clearance between the retainer and the shell's bore. It was zero
// (the ring drawn at exactly the bore's diameter), and the first print, a
// PETG ring in an ASA shell, had to be forced in (2026-10-09): ASA shrinks a
// little more than PETG, so the bore came out smaller than the ring. 0.4mm a
// side leaves a slip fit across both materials; the screws, not the bore,
// centre the ring.
retainer_clear = 0.4;
lip_height    = 6;
shelf_h       = lip_height - retainer_h;
rabbet_depth  = glass_thickness;

screw_r = panel_diameter/2 + rim/2;
n_screws = 8;
screw_clear_dia = 3.4;
// Heat-set inserts: the Kadrick M2-M5 kit. Its M3 inserts are 4.5mm across
// the knurl and 3.9mm at the lead-in, 3-8mm long. A 4.0 hole gives the knurl
// 0.25mm a side to melt into (4.2 left 0.15mm). Same as the retro case.
insert_hole_dia = 4.0;
post_od = 9;
// The 8 front posts hang 8mm below the shelf's top face, merged into the
// wall, with a 45-degree cone under each, so an M3x5 insert has plastic all
// round it. They were 2mm tall. Screws: M3x14. See the retro case's notes.
front_insert_len = 5;
front_post_h     = 8;
front_post_cone  = 4;

relief_center_deg = 270;
relief_arc_deg    = 50;

// ---- Removable back plate --------------------------------------------
// The back was a fixed floor with the electronics standing on it, so the
// only way in was through the glass. It is now a separate screwed plate,
// and everything that stood on the floor went with it: the standoffs, the
// fan mount, the intake and fan grilles, and the two cable glands.
//
// The Pi itself is mounted to the LCD panel, so taking the plate off
// exposes the back of the Pi and its cabling rather than removing it. The
// 58x49 standoffs that stood here as an alternative mounting were never
// used and are gone (2026-10-07); pi_posts() keeps their geometry.
//
// No locating spigot: a ring into the bore lands exactly where the eight
// screw posts are, since those straddle the bore wall. Eight screws on a
// 213mm circle locate the plate perfectly well on their own.
back_plate_t   = 3;    // same as the floor it replaces

// ---- Antenna mount ---------------------------------------------------
// The retro build carries the antenna on a turret out of the top of the
// case. There is no turret here -- it would be a spike out of a cat's
// skull -- so the antenna mounts on the back plate instead, behind the
// head, and only the antenna itself shows above the ears.
//
// Same socket as the retro turret, and counter-tilted by stand_angle the
// same way, so the antenna reads vertical once the whole case leans back in
// its cradle.
//
// The standoff is what makes that possible, and it is not decoration. A
// vertical antenna rising from a plate the same diameter as the head has to
// travel outward past a 111.7mm radius to clear it, and it gains z the whole
// way -- so mounted flat against the plate it converges on the head and
// fouls the top rim. Standing the socket back from the plate buys the height
// it needs to clear: at 12mm the antenna's 33mm envelope passes the rim with
// room to spare, at 0mm it cuts straight through it. antenna_clears_head in
// checks.scad is what holds that.
// Bolted on rather than moulded into the plate: it prints flat and
// support-free on its own, the plate does too, and the antenna angle can be
// changed later without reprinting the tray.
ant_stub_dia   = 26;   // the arm reaching back from the plate
ant_stub_len   = 30;   // how far back it reaches
// 30 is measured, not chosen. A vertical antenna rising from a plate the
// diameter of the head must travel out past a 111.7mm radius to clear it,
// gaining height toward the head the whole way -- so the arm is what buys
// the room to do that behind the head rather than through it. Swept against
// the antenna's own envelope: at 22mm it fouls the top rim even at nominal
// diameter, at 26mm it clears nominal but not +2mm, and at 30mm it still
// clears with 6mm of radial slack. antenna_clears_head holds it.
ant_barrel_len = 14;   // socket barrel, along the antenna's own axis
ant_flange_d   = 40;
ant_flange_t   = 7;   // 4 -> 7: the insert now lives in the FLANGE, not the plate
ant_flange_insert_d = 5.5;  // heat-set pocket depth, leaving 1.5mm of flange behind it
ant_bolt_pcd   = 30;
ant_bolt_d     = 3.4;
n_ant_bolts    = 3;
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

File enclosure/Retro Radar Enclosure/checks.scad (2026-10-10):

// Fit checks for the retro enclosure's removable back plate.
//
// Run with `sh run-checks.sh`, which measures the VOLUME each target
// produces rather than whether it produced anything: a boolean between parts
// that touch leaves zero-thickness films with many facets and no volume, so
// counting facets calls a correct model broken.
//
// Lives beside the design on purpose. `use <>` resolves relative to the file
// containing it, so a copy kept anywhere else silently finds no modules and
// every check "passes" against nothing -- which is why `canary` exists and
// must be run.
use <retro-enclosure.scad>
$fs = 0.4;
$fa = 0.5;
check = "none";
// front heat-set inserts (restated): shelf top face, insert length, hole
fi_top = 57; fi_len = 5; fi_hole = 4.0;
outer_dia=223.34; wall=3; shell_depth=61; screw_r=106.67; n_screws=8;
speaker_angles=[0,180]; back_plate_t=3;
// Restated because `use <>` imports modules and functions but NOT variables.
// A stale value here checks geometry the design no longer has, and passes.
back_lip_h=4; back_lip_t=2; back_lip_gap=0.35; back_lip_skip=9; post_od=9;
back_post_h=9; ant_bolt_pcd=30; n_ant_bolts=3; ant_flange_d=40; ant_mount_y=81;
ant_bolt_d=3.4; usbc_cut_pos=[60,-51]; usbc_screw_pitch=16.5; usbc_screw_dia=3.4; usbc_cut_w=11.0; usbc_cut_h=6.5;
usbc_boss_w=22.25; usbc_boss_h=11.0; usbc_boss_clear=0.3; usbc_recess_d=2.0; usbc_cut_r=1.2;
mount_hole_x=58; mount_hole_y=49; stand_angle=18;
base_w=outer_dia*0.86; base_d=150; plinth_rib_h=4; plinth_rib_w=3; plinth_rib_z=[3.5, 9.5];
ant_stub_len=30; ant_barrel_len=14; ant_socket_dia=33; ant_socket_depth=8;
cradle_id=outer_dia+2; cradle_od=cradle_id+26; base_h=16;
ant_conn_dia=9.15; ant_boss_dia=48; ant_socket_lead=1.2;
// Measured off the antenna: 31.25mm across the flared bottom, its widest
// point. ant_relief_* is the clear space under the socket floor for the
// connector, which is what was actually stopping the base from seating.
ant_base_dia=31.25; ant_relief_dia=18; ant_relief_h=4;
rib_h=4.0; rib_w=5; rib_z_list=[10,22]; rib_a0=340; rib_arc=220;
grille_hole_dia=2.5; grille_pitch=4.5; grille_w=90; grille_h=40;
speaker_d=45; speaker_angles=[0,180]; exhaust_slot_w=2.2; exhaust_slot_h=12;
n_exhaust=24; exhaust_a0=30; exhaust_a1=150;
ant_cable_slot_w=7; ant_cable_exit_h=7.98; ant_flange_t=7; ant_flange_insert_d=5.5; back_insert_d=8;

// The SMA bulkhead variant. Restated here for the same reason as everything
// above: `use <>` brings in modules, not variables, so a check that names one
// of these directly needs its own copy.
ant_sma_hole=6.5; ant_sma_panel_t=3; ant_sma_cavity=14; ant_twin_cover_t=3;
ant_sma_boss_d=22; ant_sma_boss_h=10; ant_sma_cavity_d=25;


// The plate and the shell meet at a butt joint; neither may intrude on the
// other.
// ---- plinth ridges (roadmap 5.4) ---------------------------------------
// A probe just outside each face of the stand's plinth, spanning the middle
// half of that face and the ridge heights. Each must find ridge material, so
// a ridge missing from any side fails. The old strips (front only, 1mm proud,
// short of where these probes start) came out empty on all four.
module plinth_side_probe(side) {
    z0 = min(plinth_rib_z); z1 = max(plinth_rib_z) + plinth_rib_w;
    if (side == "front" || side == "back")
        translate([-base_w/4, (side == "front" ? -1 : 1) * (base_d/2 + plinth_rib_h/2) - plinth_rib_h/4, z0])
            cube([base_w/2, plinth_rib_h/2, z1 - z0]);
    else
        translate([(side == "left" ? -1 : 1) * (base_w/2 + plinth_rib_h/2) - plinth_rib_h/4, -base_d/4, z0])
            cube([plinth_rib_h/2, base_d/2, z1 - z0]);
}

// The grille block at each speaker, out past the wall and the rivets' height,
// front to back. Rivets anywhere in it stood up among the holes; three of the
// ring used to.
module grille_zone(a) {
  rotate([0,0,a]) translate([outer_dia/2 - 5, -grille_w/2 - 2, -1])
    cube([10, grille_w + 4, shell_depth + 2]);
}
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

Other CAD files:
enclosure/Retro Radar Enclosure/antenna_mount_twin_cover_11_twotone.3mf
enclosure/Kitten Enclosure Two-Tone/antenna_mount_twin_cover_8_twotone.3mf
enclosure/Retro Radar Enclosure/retainer.stl
enclosure/Kitten Enclosure Two-Tone/antenna_mount_twin_8.stl
enclosure/Retro Radar Enclosure/retro-enclosure.scad
enclosure/Kitten Enclosure Two-Tone/antenna_mount.stl
enclosure/Kitten Enclosure Two-Tone/antenna_mount_sma.stl
enclosure/Kitten Enclosure Two-Tone/antenna_mount_twin_11.stl
enclosure/Retro Radar Enclosure/antenna_mount.stl
enclosure/Retro Radar Enclosure/antenna_mount_sma.stl

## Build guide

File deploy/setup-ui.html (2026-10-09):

# StratoScan setup

Getting started…

## Sign in

This device has not been set up yet. Enter the code shown on the radar's own screen, then choose a password for it.

Code on the screen

Password Continue

## WiFi ✓

Scan for networks

Password for Join network

Changing WiFi may briefly disconnect you. If this page stops responding, rejoin your home network and open this address again — the radar puts its old network back automatically if the new one doesn't work.

## Receiver location ✓

Where the antenna physically is. Used to centre the radar. Kept on the device; if you later publish a public page, the position it shows is rounded to about half a mile.

Address

Looked up via OpenStreetMap. The address is sent to their geocoder and nowhere else; the position it returns stays on the device. Prefer not to? Enter coordinates instead.

Find address

Latitude

Longitude

Type the number without a sign and pick the hemisphere. Pasting a signed value works too. Look up an address instead.

Save location

## Home airport ✓

Sets the landing/takeoff highlight and the approach heatmap.

Search Save airport

## Name

What this radar is called on its screen and on paired phones, such as "Raleigh" or "Mom's radar". Left blank, it's the home airport's city. Not shown on the public page.

Save name

## Time zone and region ✓

Sets the clock the radar timestamps everything with, and the WiFi regulatory region the radio is allowed to use. Both were fixed to the United States before; a unit used anywhere else showed the wrong time on every sighting.

Time zone show all time zones WiFi region

The time zone applies immediately. The WiFi region is a radio setting and only takes effect after the device restarts.

Save time zone and region

## Software update ✓

Updates are signed. The device will refuse anything that is not signed by the maintainer's key, and anything older than what it already has. If a new version fails to start, the old one is put back automatically — you do not have to be nearby.

Checking…

Check for updates Install update

## Share with FlightAware

Optional. Sends what this antenna hears to FlightAware (https://www.flightaware.com/adsb/), and in return gives you a free FlightAware Enterprise account (normally paid) for as long as it keeps sharing. It also shares this antenna's exact location with FlightAware, which they need to locate aircraft more precisely; you set it in your own FlightAware account. By turning it on you agree to FlightAware's terms (https://www.flightaware.com/about/termsofuse). The radar on this device is unaffected either way.

Share with FlightAware

Flightradar24 offers a similar free plan to people who share data. Their software is installed with their own instructions: stratoscan24.com/build-your-own.

## Phone app

Pair the StratoScan iPhone app to get alerts from this radar: emergencies, notable aircraft, helicopters and anything low overhead. Alerts say what flew by and roughly how far away, never where this radar is.

Pair this phone

Cancel

## Fleet

A fleet is a group of radars looked after by one person, such as the family member who gave you this one. Its administrator sees whether this radar is working (its software, receiver, storage and temperature), its name, and how many people view its public page. Never its location, your phones or your alerts. You can leave at any time.

Checking…

Invite code Join fleet

Leave this fleet

## Public page visitors

How many people look at this radar's public web address. Counts only: no cookies, and nothing is kept that could identify anyone.

Loading…

## Health reports

Optional. Every few hours the device sends the maintainer a short health check (software version, whether the receiver is working, storage wear, temperature, power dips) so a problem can be spotted and fixed without you having to notice it. It never includes your location, your network, or what flew overhead. With it on, the device also gets the public network's aircraft, flight routes and aircraft owners through the StratoScan service, which fetches each once for every radar instead of every radar asking the volunteer-run sources itself; it keeps nothing about which radar asked. Turn it off any time.

Send health reports

## Public web address ✓

Optional. Uses your own Tailscale account, so the device and its location stay under your control. Create a free account, generate an auth key, and paste it here. Skip this to keep the radar on your home network only.

Tailscale auth key Device name Also publish a public https page Connect

## Change password

Current password New password Change password

Changing it signs out every other device.

## Reset

Show reset options

Reset settings clears the location and home airport but keeps this radar on your WiFi, so you can carry on using it.

Erase everything is for giving the radar to someone else. It removes your WiFi, your Tailscale account, your password, the receiver's location, and the flight history and approach heatmap built up at this address. The radar then starts its own setup network so the next person can claim it.

Your password Type RESET to confirm Erase everything (giving it away) Reset

StratoScan™ and the StratoScan logo are trademarks of Michael Ferris. © 2026 Michael Ferris. The software is open source under the MIT licence.

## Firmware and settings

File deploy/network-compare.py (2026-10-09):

#!/usr/bin/env python3
"""
Local-only (127.0.0.1) proxy that compares this receiver against a public
ADS-B network, and keeps a running scorecard of how the two differ.

Why a device-side service rather than fetching from the page:

  - Same origin. The page is served from http://localhost, so a direct
    call to another host is a cross-origin request the API need not allow.
  - One upstream call no matter how many people are looking. The kiosk,
    a laptop and the public Funnel URL all share the same cached answer,
    so a community-run service does not get hit once per viewer.
  - The receiver's exact position never leaves the network. The query is
    built from coordinates ROUNDED to 2dp (~1.1km), the same precision
    funnel-gateway.py already exposes publicly. Sending survey-precision
    coordinates to a third party to ask "what is near me" would undo the
    rounding the rest of this project does deliberately.

Nothing here runs on its own. The scorecard accumulates only from
requests the page makes, and the page only makes them when the
"Network comparison" setting is on -- which is ON by default
(DEFAULT_ALERT_SETTINGS in index.html). Turning it off stops all contact.

The view beyond the ring (/network/around) comes through the relay's
shared cache when this radar reports to the relay at all (heartbeat.py:
the owner's health-reports switch): a disc is fetched from adsb.lol once
and served to every radar and phone that asks for it (performance audit
2026-10-09). For that to be the same disc, those discs are on a fixed
world lattice, not round each radar's view. The relay itself cannot ask
adsb.lol (it rate-limits Cloudflare's shared addresses), so the unit that
finds a disc missing fetches it, with its own address as always, and hands
it up for the others. The relay is never a single point of failure:
unreachable, the unit asks adsb.lol itself, as before.

GET /network      -> {"ac": [...], "stats": {...}, "source": ..., "fetched": age_s}
GET /network/stats -> just the scorecard, no upstream call
"""
import http.server
import json
import math
import os
import re
import signal
import sys
import threading
import time
import urllib.error
import urllib.parse
import urllib.request

HERE = os.path.dirname(os.path.abspath(__file__))
sys.path.insert(0, HERE)
try:
    import heartbeat                       # the unit key and the relay's address
except Exception:                          # an image without it, or a test
    heartbeat = None

LISTEN = ("127.0.0.1", 8087)
STORE_PATH = os.path.join(os.environ.get("STATE_DIRECTORY", "."), "coverage.json")

LOCAL_AIRCRAFT = "http://127.0.0.1/tar1090/data/aircraft.json"
LOCAL_RECEIVER = "http://127.0.0.1/tar1090/data/receiver.json"

# Community-run and free. Identify ourselves rather than arriving anonymous,
# and never poll faster than MIN_UPSTREAM_S -- this is somebody's donated
# bandwidth, and the page has no reason to want fresher than this.
# A real Mode S address is 24 bits, i.e. exactly six hex digits. Anything else
# in the feed is a placeholder, not an identity -- see the ghost loop below.
ICAO_HEX = re.compile(r"[0-9a-fA-F]{6}")

SOURCE_NAME = "adsb.lol"
SOURCE_URL = "https://api.adsb.lol/v2/point/{lat}/{lon}/{radius}"
USER_AGENT = "StratoScan/1.0 (+https://github.com/mferris/StratoScan; coverage self-comparison)"
MIN_UPSTREAM_S = 15
UPSTREAM_TIMEOUT = 8
RADIUS_NM = 25          # a little beyond the 20nm ring the radar draws
RING_NM = 20            # what the radar actually shows; stats use this

MAX_BODY = 400_000
# The network round a point the radar's screen is looking at (roadmap 2.23 on
# the kiosk, 2026-10-08): what adsb.lol serves round a point, how long one
# answer is kept for the same place, and how often adsb.lol may be asked at
# all, whoever asks -- the public page can, through the gateway.
AROUND_MIN_NM, AROUND_MAX_NM = 25, 250
AROUND_CACHE_S = 10
AROUND_UPSTREAM_GAP_S = 5
AROUND_MAX_BODY = 3_000_000     # a busy 250 nm disc is well over MAX_BODY
AROUND_PLACES = 8               # answers kept at once
_around = {"cache": {}, "last_upstream": 0.0}
# A view wider than one disc (the owner's ask, 2026-10-08): several discs on
# a square grid, spaced so they leave no gap, at most 3 x 3 of them covering
# the middle of the view; the rest of a continent stays empty, and the answer
# says how far it reaches. adsb.lol is asked at most TILE_CALLS times in any
# TILE_WINDOW_S, in all, whoever asks.
TILE_NM = AROUND_MAX_NM
TILE_SPACING_NM = AROUND_MAX_NM * math.sqrt(2)
TILE_MAX_N = 3
TILE_SINGLE_UP_TO_NM = 190      # a view this far out still fits one disc (x1.3 <= 250)
TILE_WINDOW_S, TILE_CALLS = 20, 9
TILE_CACHE_S = 15
TILE_PACE_S = 1.2               # between questions: adsb.lol refuses a burst (420/429, measured)
TILE_RETRY_S = 2.5              # one more try after a refusal
TILE_DISC_FRESH_S = 45          # a disc is asked for again after this (nine take the Pi ~25 s)
TILE_KEEP_S = 120               # a disc's last answer is shown this long while a fresh one is fetched
TILE_IN_THREAD = True           # the discs are fetched in the background (tests set False)
_tiles = {"cache": {}, "discs": {}, "calls": [], "busy": set(), "fetching": False}
# The relay's shared cache, and the lattice its discs are on (see the module
# docstring). The lattice is rows of 250 nm discs every 180/LATTICE_ROWS
# degrees of latitude (about 348 nm) with as many columns as fit
# LATTICE_SPACING_NM apart at that latitude, so every point on Earth is
# inside at least one disc and never more than ~248 nm from its nearest
# centre. The relay computes the same lattice (relay/src/netcache.js) and
# refuses a disc that is not on it, so the two formulas are kept identical.
RELAY = os.environ.get("STRATOSCAN_NET_RELAY", "1") != "0"     # tests switch it off
RELAY_DISC_PATH = "/v1/net/disc/{lat}/{lon}"
RELAY_TIMEOUT = 9
RELAY_PACE_S = 0.2              # between discs the relay already has
RELAY_CALLS = 40                # per TILE_WINDOW_S: most are the relay's, not adsb.lol's
RELAY_WAIT_S = 2.0              # while another radar is fetching the disc for everyone
LATTICE_R_NM = AROUND_MAX_NM
LATTICE_SPACING_NM = TILE_SPACING_NM
LATTICE_ROWS = math.ceil(10800 / LATTICE_SPACING_NM)     # 31, pole to pole
LATTICE_ROW_STEP = 180 / LATTICE_ROWS
LATTICE_MAX_DISCS = 16          # a continent-wide view; 9 view-centred discs reach as far
LATTICE_SLACK_NM = 2            # a view is "inside" a disc with this to spare, never on its rim

# Altitude bands, in feet. Chosen to separate a horizon problem from a
# sensitivity one: if the low bands are the weak ones the antenna is being
# blocked, and no amount of gain fixes that.
ALT_BANDS = [(0, 2000), (2000, 6000), (6000, 15000), (15000, 99000)]
BRG_BINS = 12           # 30-degree sectors
WINDOW_S = 24 * 3600    # scorecard covers a rolling day

lock = threading.Lock()
_cache = {"at": 0.0, "payload": None}
# The scorecard lives in memory and is written at most every FLUSH_INTERVAL,
# plus on shutdown. It used to be rewritten on every upstream fetch (every
# ~15 s, ~4,300 times a day) -- steady SD-card wear for a rolling one-day
# scorecard whose last few minutes are worth nothing after a power cut.
FLUSH_INTERVAL = 600
_store = None
_dirty = False


def band_label(lo, hi):
    return f"{lo}-{hi}" if hi < 99000 else f"{lo}+"


def load_store():
    try:
        with open(STORE_PATH) as f:
            d = json.load(f)
            return d if isinstance(d, dict) else {}
    except (FileNotFoundError, json.JSONDecodeError, OSError):
        return {}


def save_store(store):
    tmp = STORE_PATH + ".tmp"
    with open(tmp, "w") as f:
        json.dump(store, f)
        f.flush()
        os.fsync(f.fileno())
    os.replace(tmp, STORE_PATH)   # atomic: a torn scorecard is worse than a stale one


def current():
    """The in-memory scorecard. Caller must hold `lock`."""
    global _store
    if _store is None:
        _store = load_store() or fresh_store()
    return _store


def flush():
    global _dirty
    with lock:
        if not _dirty or _store is None:
            return
        save_store(_store)
        _dirty = False


def _flusher():
    while True:
        time.sleep(FLUSH_INTERVAL)
        try:
            flush()
        except OSError as e:
            print(f"network-compare: flush failed: {e}", file=sys.stderr, flush=True)


def _shutdown(signum, frame):
    flush()
    sys.exit(0)


def fresh_store():
    return {
        "since": time.time(),
        "samples": 0,
        "heard": 0, "network": 0,
        "alt": {band_label(*b): [0, 0] for b in ALT_BANDS},
        "brg": {str(i): [0, 0] for i in range(BRG_BINS)},
        "age_mine": [], "age_net": [],
    }


def get_json(url, timeout=6, limit=MAX_BODY):
    req = urllib.request.Request(url, headers={"User-Agent": USER_AGENT})
    with urllib.request.urlopen(req, timeout=timeout) as r:
        return json.loads(r.read(limit).decode("utf-8", "replace"))


def haversine(lat1, lon1, lat2, lon2):
    p1, p2 = math.radians(lat1), math.radians(lat2)
    dl = math.radians(lon2 - lon1)
    dp = p2 - p1
    a = math.sin(dp / 2) ** 2 + math.cos(p1) * math.cos(p2) * math.sin(dl / 2) ** 2
    rng = 3440.065 * 2 * math.atan2(math.sqrt(a), math.sqrt(1 - a))
    y = math.sin(dl) * math.cos(p2)
    x = math.cos(p1) * math.sin(p2) - math.sin(p1) * math.cos(p2) * math.cos(dl)
    return rng, (math.degrees(math.atan2(y, x)) + 360) % 360


def home():
    d = get_json(LOCAL_RECEIVER, timeout=4)
    return float(d["lat"]), float(d["lon"])


def median(xs):
    if not xs:
        return None
    s = sorted(xs)
    return round(s[len(s) // 2], 1)


def compare(lat, lon):
    """One paired sample: what this antenna heard vs what the network has."""
    local = get_json(LOCAL_AIRCRAFT, timeout=4)
    # Round before it leaves the machine. See the module docstring.
    net = get_json(SOURCE_URL.format(lat=round(lat, 2), lon=round(lon, 2),
                                     radius=RADIUS_NM), timeout=UPSTREAM_TIMEOUT)

    mine = {}
    for a in local.get("aircraft", []):
        if "lat" not in a or "lon" not in a:
            continue
        r, b = haversine(lat, lon, a["lat"], a["lon"])
        if r <= RING_NM:
            mine[a["hex"].strip().lower()] = (a, r, b)

    theirs = {}
    for a in net.get("ac", []):
        if a.get("lat") is None or a.get("lon") is None:
            continue
        r, b = haversine(lat, lon, a["lat"], a["lon"])
        if r <= RING_NM:
            theirs[str(a.get("hex", "")).strip().lower()] = (a, r, b)

    return mine, theirs


def fold(store, mine, theirs):
    """Fold one paired sample into the rolling scorecard."""
    if time.time() - store.get("since", 0) > WINDOW_S:
        store = fresh_store()

    store["samples"] += 1
    store["network"] += len(theirs)
    store["heard"] += len(set(mine) & set(theirs))

    for hexid, (a, r, b) in theirs.items():
        alt = a.get("alt_baro")
        alt = 0 if alt == "ground" else (alt if isinstance(alt, (int, float)) else None)
        heard = hexid in mine
        if alt is not None:
            for lo, hi in ALT_BANDS:
                if lo <= alt < hi:
                    key = band_label(lo, hi)
                    store["alt"][key][1] += 1
                    if heard:
                        store["alt"][key][0] += 1
                    break
        k = str(int(b // (360 / BRG_BINS)) % BRG_BINS)
        store["brg"][k][1] += 1
        if heard:
            store["brg"][k][0] += 1

    both = set(mine) & set(theirs)
    for h in both:
        am = mine[h][0].get("seen_pos")
        an = theirs[h][0].get("seen_pos")
        if isinstance(am, (int, float)):
            store["age_mine"].append(round(am, 1))
        if isinstance(an, (int, float)):
            store["age_net"].append(round(an, 1))
    # bounded: these are only used for a median
    store["age_mine"] = store["age_mine"][-4000:]
    store["age_net"] = store["age_net"][-4000:]
    return store


def scorecard(store):
    if not store or not store.get("samples"):
        return {"ready": False}
    net = store["network"] or 1
    return {
        "ready": True,
        "since": store["since"],
        "samples": store["samples"],
        "coveragePct": round(100 * store["heard"] / net),
        "heard": store["heard"], "networkTotal": store["network"],
        "byAlt": {k: {"heard": v[0], "total": v[1],
                      "pct": round(100 * v[0] / v[1]) if v[1] else None}
                  for k, v in store["alt"].items()},
        "byBearing": {k: {"heard": v[0], "total": v[1],
                          "pct": round(100 * v[0] / v[1]) if v[1] else None}
                      for k, v in store["brg"].items()},
        "medianAgeMine": median(store["age_mine"]),
        "medianAgeNetwork": median(store["age_net"]),
        "source": SOURCE_NAME,
    }


def build_payload():
    lat, lon = home()
    mine, theirs = compare(lat, lon)
    global _store, _dirty
    with lock:
        # fold() may hand back a brand-new store when the day window rolls
        # over, so keep whatever it returns rather than mutating in place.
        _store = fold(current(), mine, theirs)
        _dirty = True
        card = scorecard(_store)

    # Only the aircraft this receiver did NOT hear are worth sending: the
    # page already has its own, and shipping duplicates would invite the
    # display to prefer network data over local, which is the opposite of
    # what this radar is for.
    ghosts = []
    for hexid, (a, r, b) in theirs.items():
        if hexid in mine:
            continue
        # A ghost is keyed by hex for its whole life -- the track that carries
        # its trail, its photo, its owner lookup and its sighting count. The
        # feed occasionally carries a target with a placeholder address rather
        # than a real 24-bit ICAO one, and every such target collapses into a
        # single track: one card on the radar reading "00000000 / SEEN x3",
        # merging unrelated aircraft and attributing a real registered owner
        # to an address that identifies nobody. Drop them rather than show a
        # confident answer assembled from several different aeroplanes.
        if not ICAO_HEX.fullmatch(hexid or ""):
            continue
        ghosts.append(ghost_entry(hexid, a))
    return {"ac": ghosts, "mine": len(mine), "network": len(theirs),
            "stats": card, "source": SOURCE_NAME, "at": time.time()}


def ghost_entry(hexid, a):
    """A network aircraft as the page draws it. The panel shows a ghost the
    same fields it shows a local contact, so the same fields have to survive
    this projection. baro_rate is the primary vertical rate for the same
    reason readsb prefers it; geom_rate is the fallback when a transponder
    only reports the GNSS-derived one."""
    return {
        "hex": hexid,
        "flight": (a.get("flight") or "").strip() or None,
        "lat": a.get("lat"), "lon": a.get("lon"),
        "alt": a.get("alt_baro"),
        "gs": a.get("gs"), "track": a.get("track"),
        "seen_pos": a.get("seen_pos"),
        "type": a.get("t"), "reg": a.get("r"),
        "squawk": a.get("squawk"),
        "vrate": a.get("baro_rate") if a.get("baro_rate") is not None
                 else a.get("geom_rate"),
        "emergency": a.get("emergency"),
        "category": a.get("category"),
    }


def relay_on():
    """Whether the discs come through the relay: its switch is health reports."""
    if not RELAY or heartbeat is None:
        return False
    try:
        return bool(heartbeat.relay_on())
    except Exception:
        return False


def lattice_cols(lat):
    return max(1, math.ceil(21600 * math.cos(math.radians(lat)) / LATTICE_SPACING_NM))


def lattice_centre(lat, lon):
    """The lattice centre whose cell holds (lat, lon): the nearest one."""
    k = min(LATTICE_ROWS - 1, max(0, math.floor((lat + 90) / LATTICE_ROW_STEP)))
    clat = -90 + (k + 0.5) * LATTICE_ROW_STEP
    n = lattice_cols(clat)
    dlon = 360 / n
    j = math.floor((lon + 180) / dlon) % n
    return round(clat, 4), round(-180 + (j + 0.5) * dlon, 4)


def lattice_centres(lat, lon, within_nm):
    """Lattice centres within `within_nm` of a point, nearest first:
    [(distance, lat, lon)]."""
    out, seen = [], set()
    rows = int(within_nm / 60 / LATTICE_ROW_STEP) + 2
    k0 = math.floor((lat + 90) / LATTICE_ROW_STEP)
    for k in range(max(0, k0 - rows), min(LATTICE_ROWS, k0 + rows + 1)):
        clat = -90 + (k + 0.5) * LATTICE_ROW_STEP
        n = lattice_cols(clat)
        dlon = 360 / n
        span = int(within_nm / (60 * max(0.05, math.cos(math.radians(clat)))) / dlon) + 2
        j0 = math.floor((lon + 180) / dlon)
        for j in range(j0 - span, j0 + span + 1):
            c = (round(clat, 4), round(-180 + ((j % n) + 0.5) * dlon, 4))
            if c in seen:
                continue
            seen.add(c)
            d, _ = haversine(lat, lon, c[0], c[1])
            if d <= within_nm:
                out.append((d, c[0], c[1]))
    out.sort()
    return out


def plan_discs(lat, lon, half, lattice):
    """Where to ask for a view `half` nm out from its middle, and how far
    the answer reaches: [(lat, lon, radius)], reach.

    Round the view (adsb.lol asked directly): one disc of the view's own
    radius while it fits, else the n x n grid of view_discs(). On the
    lattice (through the relay): the one disc that holds the whole view
    when there is one, else the nearest discs that between them cover it,
    at most LATTICE_MAX_DISCS; the reach is what they are sure to cover.
    """
    want = max(AROUND_MIN_NM, min(AROUND_MAX_NM, half * 1.3))
    if not lattice:
        if half <= TILE_SINGLE_UP_TO_NM:
            return [(lat, lon, int(want))], int(want)
        return view_discs(lat, lon, half)
    if half > TILE_SINGLE_UP_TO_NM:
        want = min(half * 1.3, TILE_MAX_N * TILE_SPACING_NM / 2)    # as far as the grid reached
    cands = lattice_centres(lat, lon, want + LATTICE_R_NM)
    if cands and cands[0][0] <= LATTICE_R_NM - LATTICE_SLACK_NM - want:
        return [(cands[0][1], cands[0][2], LATTICE_R_NM)], int(want)
    chosen = cands[:LATTICE_MAX_DISCS]
    reach = want
    if len(cands) > LATTICE_MAX_DISCS:
        # every centre within reach + 250 is in, so the first left out bounds it
        reach = min(want, cands[LATTICE_MAX_DISCS][0] - LATTICE_R_NM - LATTICE_SLACK_NM)
    return [(c[1], c[2], LATTICE_R_NM) for c in chosen], int(max(AROUND_MIN_NM, reach))


def view_discs(lat, lon, half):
    """Where to ask for a view `half` nm out from its middle: one disc round
    the middle while it fits, else an n x n grid of 250 nm discs (n <= 3)
    covering the middle; and the radius that covers."""
    if half <= TILE_SINGLE_UP_TO_NM:
        r = int(max(AROUND_MIN_NM, min(AROUND_MAX_NM, half * 1.3)))
        return [(lat, lon, r)], r
    n = max(2, min(TILE_MAX_N, math.ceil(2 * half / TILE_SPACING_NM)))
    discs = []
    for j in range(n):
        for i in range(n):
            east = (i - (n - 1) / 2) * TILE_SPACING_NM
            north = (j - (n - 1) / 2) * TILE_SPACING_NM
            discs.append((round(lat + north / 60, 2),
                          round(lon + east / (60 * math.cos(math.radians(lat))), 2), int(TILE_NM)))
    return discs, int(n * TILE_SPACING_NM / 2)


def _direct_disc(d):
    """adsb.lol itself: one more try after a refusal (420/429/503)."""
    for attempt in (1, 2):
        try:
            return get_json(SOURCE_URL.format(lat=d[0], lon=d[1], radius=d[2]),
                            timeout=UPSTREAM_TIMEOUT, limit=AROUND_MAX_BODY)
        except urllib.error.HTTPError as e:
            if attempt == 1 and e.code in (420, 429, 503):
                time.sleep(TILE_RETRY_S)
                continue
            return None
        except (urllib.error.URLError, OSError, ValueError):
            return None
    return None


def _relay_disc(d):
    """The relay's cache: the same disc every other radar gets. Not there
    yet, the relay says who fetches it: this unit, which then hands it up
    for the others, or another radar already on it, in which case wait a
    moment and ask again. Anything else -- the relay unreachable, not
    serving this unit, or saying to slow down -- adsb.lol itself, as
    before: that costs adsb.lol one question from this address, which is
    what it always got."""
    path = RELAY_DISC_PATH.format(lat=d[0], lon=d[1])
    for attempt in range(3):
        try:
            status, raw = heartbeat.relay_fetch("GET", path, timeout=RELAY_TIMEOUT, limit=AROUND_MAX_BODY)
        except (OSError, ValueError):
            break
        if status == 200:
            if len(raw) > AROUND_MAX_BODY:
                break
            try:
                return json.loads(raw.decode("utf-8", "replace"))
            except ValueError:
                break
        if status != 404:
            break
        try:
            why = json.loads(raw.decode("utf-8", "replace") or "{}")
        except ValueError:
            why = {}
        if why.get("fetching") and attempt < 2:
            time.sleep(RELAY_WAIT_S)
            continue
        net = _direct_disc(d)
        if why.get("fetch") and isinstance(net, dict):
            _share_disc(path, net)
        return net
    return _direct_disc(d)


def _share_disc(path, net):
    """Hand a disc this unit fetched up to the relay for the others. Best
    effort: a failure costs nothing but the sharing."""
    try:
        heartbeat.relay_fetch("PUT", path, json.dumps(net, separators=(",", ":")).encode(),
                              timeout=RELAY_TIMEOUT, limit=4096)
    except Exception:
        pass
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

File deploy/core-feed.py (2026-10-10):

#!/usr/bin/env python3
"""
The core feed (roadmap 1.8): one merged, labelled list of the aircraft this
unit knows about, for every screen -- the kiosk, the public page, the iPhone
app, the Watch, and in time the alerts.

Why it exists: the page, the app and the alerts each used to build their own
picture from readsb's aircraft.json, with their own copies of the tables that
say what an aircraft is. The copies drifted (the military badge was fixed
twice in one day; the app never showed the network's aircraft; counts
differed between the app and the kiosk), and every public visitor's browser
repeated every route and owner lookup against third-party services. Here the
labelling happens once, on the unit, from labels.py -- the same module the
alerts use -- and the lookups are made once and cached.

    GET /api/aircraft             the antenna's aircraft, labelled
    GET /api/aircraft?network=1   plus those a public ADS-B network reports in
                                  the ring that the antenna didn't hear
                                  (source "network"), fetched through
                                  network-compare.py only because a client
                                  asked -- that service's promise that nothing
                                  contacts the network on its own still holds

Safe to publish: no antenna-relative field (r_dst, r_dir) and no receiver
position leaves this service, so the feed can't locate the receiver; the
public gateway serves it read-only like the other stores. Aircraft positions
are what the aircraft broadcast to everyone.

Lookups (routes from adsb.im, registered owners from adsbdb for private
aircraft) run in a background thread, batched and cached in memory the way
the page did them; the feed never waits on them, it carries whatever is
known so far. Nothing is written to disk, so no SD-card wear.
"""
import http.server
import json
import math
import os
import sys
import threading
import socket
import time
import urllib.error
import urllib.parse
import urllib.request

HERE = os.path.dirname(os.path.abspath(__file__))
sys.path.insert(0, HERE)
import labels  # noqa: E402
try:
    import heartbeat  # noqa: E402   the unit key and the relay's address
except Exception:                   # an image without it, or a test
    heartbeat = None

LISTEN = ("127.0.0.1", int(os.environ.get("STRATOSCAN_CORE_PORT", "8088")))
AIRCRAFT_JSON = os.environ.get("STRATOSCAN_AIRCRAFT_JSON", "/run/readsb/aircraft.json")
RECEIVER_JSON = os.environ.get("STRATOSCAN_RECEIVER_JSON", "/run/readsb/receiver.json")
NETWORK_URL = os.environ.get("STRATOSCAN_NETWORK_URL", "http://127.0.0.1:8087/network")
ROUTE_API = os.environ.get("STRATOSCAN_ROUTE_API", "https://adsb.im/api/0/routeset")
OWNER_API = os.environ.get("STRATOSCAN_OWNER_API", "https://api.adsbdb.com/v0/aircraft/{hex}")
LOOKUPS = os.environ.get("STRATOSCAN_CORE_LOOKUPS", "1") != "0"   # tests switch them off
# Routes and owners come through the relay's shared cache when this radar
# reports to the relay at all (heartbeat.py: the owner's health-reports
# switch): a callsign's route and an aircraft's owner are the same for
# every radar, so the relay asks adsb.im and adsbdb once for all of them
# (performance audit 2026-10-09). The relay answers in their own shapes.
# Anything but an answer -- unreachable, not serving this unit, the
# service refusing the relay -- and the feed asks them itself, which costs
# them one question from this address, as before.
RELAY = os.environ.get("STRATOSCAN_NET_RELAY", "1") != "0"
RELAY_ROUTES_PATH = "/v1/net/routes"
RELAY_OWNER_PATH = "/v1/net/owner/{hex}"
USER_AGENT = "StratoScan/1.0 (+https://github.com/mferris/StratoScan; core feed)"

RING_NM = 20            # what the radar draws; counts use it, as the kiosk's do
# Which band each aircraft was heard on (2026-10-10). readsb turns 978 MHz
# (UAT) messages into 1090-style ones before merging them, so its own list
# cannot say which came from where; the 978 decoder's JSON output can, so
# this listens to it and remembers each address it decoded for UAT_KEEP_S.
# An aircraft readsb tags ADS-R ("adsr_icao") is a 978 aircraft too, re-sent
# on 1090 by a ground station. Nothing listening on the port (no 978 radio,
# or it is switched off) is normal: every aircraft is then 1090.
UAT_JSON = ("127.0.0.1", int(os.environ.get("STRATOSCAN_UAT_JSON_PORT", "30979")))
UAT_KEEP_S = 90
UAT_RETRY_S = 30
STALE_S = 60            # readsb keeps an aircraft this long after its last message
AIRCRAFT_CACHE_S = 1.0  # one read of aircraft.json per second, however many clients
NETWORK_CACHE_S = 15.0  # network-compare caches upstream for 15 s itself
ROUTE_BATCH_S, ROUTE_BATCH_MAX = 4.0, 50
OWNER_RETRY_S = 300
CACHE_MAX = 20000       # routes/owners kept; the oldest go first

# Fields copied from readsb's record, under the feed's names. Antenna-relative
# ones (r_dst, r_dir) are deliberately absent.
FIELDS = {"flight": "flight", "lat": "lat", "lon": "lon", "gs": "gs", "track": "track",
          "squawk": "squawk", "category": "category", "emergency": "emergency",
          "seen_pos": "seenPos", "seen": "seen", "nav_heading": "navHeading"}


def _now():
    return time.time()


def relay_on():
    if not RELAY or heartbeat is None:
        return False
    try:
        return bool(heartbeat.relay_on())
    except Exception:
        return False


class Cache(dict):
    """A dict that forgets its oldest entries past CACHE_MAX."""
    def put(self, k, v):
        self.pop(k, None)
        self[k] = v
        while len(self) > CACHE_MAX:
            self.pop(next(iter(self)))
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

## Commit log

2026-10-04 Visitor counts: stats listener on 8091, not 8087 (network-compare's)
    2026.10.04.1 put the gateway's stats listener on 8087, which network-compare.py
    already held: on RDU the listener failed to bind, so no one could read the
    counts, and after a reboot the two would race for the port. Moved to 8091.
    tests/test_ports.py now fails if two services claim one loopback port, or if
    a reader names a port nothing serves; it catches this against the old code.
    [funnel-gateway.py, heartbeat.py, setup-server.py]
2026-10-04 Remove the LiveATC link
    It could never play on the radar itself: LiveATC's terms rule out embedding
    their audio, and opening their page from the kiosk stranded the screen, so it
    was disabled there and only ever opened a tab in a laptop's browser, on a
    volunteer feed that was often offline. Gone from the settings, the landing
    chime, the setup page and the docs; a stored switch is forgotten. The radar
    still accepts an atcMount from older pages and ignores it. A radar that
    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
2026-10-04 Settings: a real back button, and headings that read as headings
    The back arrow was small, dim text in the corner; it is now a pill in the
    normal text colour on its own line, clear of the close button. Each screen's
    title was barely bigger than the settings under it and ran into the first
    one; it is now larger, with a rule beneath it. Checked in Daylight and
    Classic; the back button still returns to the menu.
2026-10-04 Shopping: ASA's support is Bambu Support for ABS or HIPS, not PETG
    Bambu Studio won't put a low-temperature filament (PETG) on a plate with a
    high-temperature one (ASA).
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2026-10-04 Kiosk: trails follow the reported fixes, not the blip's guesses
    Trails were sometimes jagged, for the antenna's own aircraft and the
    network's ghosts alike. They were sampled from the drawn position every
    250ms, and the drawn position is a guess between fixes: eased toward its
    target and dead-reckoned along the last track. On a turning aircraft, or
    one whose position squitters are being missed (seenPos of 5-40s is routine
    on RDU's weaker contacts; network aircraft are up to 45s stale), the guess
    runs wide and the blip swings back when the next fix lands. Every swing
    was recorded as a kink.
    A trail point is now a reported position only: recordFix() appends the raw
    fix, as bearing/range from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
2026-10-07 Cases: no Pi posts on the back plate, and the antenna mount clears the top screw
    Two things the owner found with the printed plate in hand (2026-10-07).
    The four 58x49 Pi standoffs around the centre vent were the Pi's original
    mounting, kept "as an alternative" after the Pi moved onto the display's
    back. Nothing ever used them. Gone from both plates; pi_posts() keeps the
    geometry, defined but unused, the way the fan mount and keyholes are. The
    usbc_clears_standoffs check had nothing left to test and is removed.
    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
    [antenna_mount.stl, antenna_mount_sma.stl, antenna_mount_twin.stl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]
2026-10-08 Cases: the twin antenna mount is two parts, and its cables are laid in
    The twin mount as printed could not be assembled. Each cable was meant to
    be threaded through an internal tunnel -- down a tower, along the
    crossbar, down the arm -- but both ends of an SMA jumper are rigid metal
    about 9 mm across and 15-20 mm long, and a body that fat cannot turn a
    right-angle corner inside an 11 mm bore: the geometry allows a few
    millimetres, not twenty, and the route had two such corners. The checks
    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
    [antenna_mount_twin.stl, antenna_mount_twin_cover.stl, back_plate.stl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]
2026-10-08 Cases: twin mount in 8 mm and 11 mm styles, rounded, with the frequencies on the cover
    The owner's jumpers come with an 8 mm hex body or an 11 mm one, and a
    mount is printed for one kind. Every size that depends on the body --
    slot, pocket, tower width, the bar's thickness, the cover's tab and pad,
    the screw positions -- is now a function of the jack size, and the
    mount's modules take the pair of sizes as an argument, so one source
    prints either: antenna_mount_twin_8 / _11 and their covers (a mixed pair
    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
    [antenna_mount_twin.stl, antenna_mount_twin_11.stl, antenna_mount_twin_8.stl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]
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2026-10-08 App: the map fills the screen, goes anywhere, and one switch covers the network (#54, #55, #56, #57, #58)
    From the owner's trip with the phone (2026-10-08): the app showed the sky
    around him in the air and in New York, from adsb.lol, which was right,
    but through three switches nobody could explain, in a round picture that
    used a third of the screen.
    One switch: Settings > Public network. At home it fills in the aircraft
    the radar didn't hear. Away from the radar (beyond its 20 nm), or with no
    radar, the view centres on the phone and shows the aircraft around it by
    itself; the centre button switches between that and the radar's view, and
    "BACK TO THE RADAR" brings it home. Sky view follows t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
2026-10-08 Kiosk: the old feed path is gone; the page reads only the core feed (1.9)
    Kept one release as a fallback after the core feed became the default on
    2026-10-04, and a quiet week has passed: readsb's aircraft.json is no
    longer read by the page, the ?core=0 switch is gone, and no visitor's
    browser asks adsb.im for routes or adsbdb for owners. fetchAircraft()
    polls /api/aircraft and shows NO SIGNAL when it doesn't answer;
    lookupOwner() only reads what the feed brought. About 150 lines less.
    Checked in a browser against RDU: connected, routes and an owner on the
    labels, and not one request to the old hosts. tests/test_kiosk_core_only.py
    pins it. Not yet released to the unit (its turn is about 2026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
2026-10-08 Security follow-ups 2, 3 and 7 (#52): per-address throttle, rotating links, socket timeouts
    Item 2: the setup server's sign-in throttle was one global counter, so a
    device on the LAN failing on purpose kept the owner out for up to 15
    minutes. It is now per client address (the same backoff, capped at 15 min,
    forgotten after a quiet quarter hour), with a slower backstop over all
    addresses together: 50 failures in a window and everyone waits 30 s
    between tries. tests/test_setup_throttle.py.
    Item 3: a fleet administrator's link can be replaced, by the administrator
    ("Replace my link" on their page; that browser stays signed in) or by the
    maintainer (one "New link" button per administrator). The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
    [approach-store.py, core-feed.py, funnel-gateway.py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]
2026-10-08 Security follow-up 4 (#52): the network watchdog is one long-running service
    It was a oneshot on a two-minute timer, so systemd announced a start and a
    finish every run: about 2,000 journal lines a day for a job that mostly
    has nothing to say. net-watchdog.py --loop now keeps the same cadence
    itself (45 s after boot, then every 120 s; a failed run is logged, not
    fatal), the service is Type=simple with Restart=always, the timer file is
    gone, the installer disables and removes it on an older unit, and ota.py
    restarts the service when net-watchdog.py changes. The one-shot form (no
    flag) stays for the tests. tests/test_watchdog_service.py.
    On RDU the switch is by hand with the next release, sin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
    [net-watchdog.py, ota.py]
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2026-10-08 Security follow-up 1 (#52): the events service runs as its own user
    It ran as root only to read the unit key. Now it runs as stratoscan-events
    and reads the key through the stratoscan-relay group: the installer
    creates both, keeps /var/lib/stratoscan-relay root:stratoscan-relay 0750
    and unit.key 0640, and heartbeat.py does the same when it creates the key
    (share_state_with_group). The service never creates the key itself: its
    senders see None before a phone has paired and fail quietly, to retry. It
    can write only its runtime directory. tests/test_events_user.py.
    On RDU the switch is by hand with the next release: run the installer's
    accounts step (or the same four commands), install the uni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
    [events.py, heartbeat.py]
2026-10-08 Security follow-ups 6 and 8 (#52): a managed unit's firewall, write rule, sudo rule and fleet key
    Only with MANAGED=1, for a radar the maintainer keeps reachable over the
    tailnet (docs/gifting-a-unit.md); never on RDU or an owner's own unit.
    The installer then: drops SSH from anywhere but Tailscale (nftables,
    deploy/stratoscan-managed.nft; the tailnet's policy is what lets the
    maintainer in, this makes sure nothing else can try); takes writes to the
    shared stores only from private addresses (lighttpd,
    92-stratoscan-managed-writes.conf); replaces Raspberry Pi OS's
    NOPASSWD: ALL for the login user with a rule naming the maintenance
    commands (ota.py apply/check/status, restart or look at the St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
2026-10-08 Gateway: the page's policy only on a GET, and a small policy cache
    A HEAD has no body to hash, so it got a policy with no script hash; a
    browser never sees that, but it looked wrong in a check. The cache keeps
    a few entries instead of one, so alternating variants don't recompute.
    [funnel-gateway.py]
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2026-10-08 Kiosk: the zoom buttons sit tight round the gear
    + directly above it, − directly below, ⌂ at its right while the view is
    away; 60 px from the gear's centre, aligned under it. The owner found the
    first placement too spread out.
2026-10-08 Kiosk: the sweep fills the visible dial at any zoom
    Zoomed in, the sweep was drawn at the zoomed radius onto the dial-sized
    canvas, whose square edge cut it: it looked like a sweep too small for
    its rings (the owner noticed). It is a screen-space effect, not a
    plotted range: it now reaches the dial's far edge from the radar, whatever
    the zoom. The canvas is a square centred on the radar, the dial's size at
    home and up to twice that while the view is panned, so its own edge never
    cuts the wedge, and the round clip hides the rest; with the radar off the
    dial it fades out. Checked in a browser at 1.5x, panned and far away.
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2026-10-08 Kiosk: the followed aircraft can't be missed
    The owner pressed FOLLOW and couldn't find the aircraft: beyond 20 nm it
    was not drawn at all (the ring is where the radar's picture ends), and
    its tag sat on the dial's rim like every other, far from a blip in the
    middle. Now the followed aircraft is drawn wherever it is, its blip a
    little larger, with a pulsing reticle round it, and its tag, brightened
    and on top, sits just beside it. The FOLLOW pill moved next to the close
    button, clear of the panel's own tags. Checked in a browser following
    RVJ524 at 3x: reticle in the middle, tag beside it.
2026-10-08 Installer: real touch events for the panel, so a pinch reaches the page
    Raspberry Pi OS's autotouch maps a touch screen in the kiosk user's labwc
    config with mouseEmulation="yes", and labwc then turns every touch into
    mouse events: one pointer, so the page never saw a second finger and a
    pinch did nothing (the HUD's finger counter proved it). The controller
    reports multi-touch; with mouseEmulation="no" the pinch zooms and taps,
    the settings list's drag-scroll and panning still behave (confirmed by
    the owner on RDU, set by hand there). autotouch leaves an existing line
    alone, so the installer writes the setting: it flips autotouch's line or
    adds one for every touch device, and signals labwc t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
2026-10-08 A wide view is a grid of discs, on the panel and in the app (#56)
    adsb.lol serves at most 250 nm round a point and refuses a burst (420
    and 429, measured; about one question a second is fine). A view wider
    than one disc, more than 190 nm from the middle to the dial's edge, is
    now a square grid of 250 nm discs spaced so they leave no gap: 2x2 up to
    354 nm, 3x3 beyond and never more, covering about 530 nm round the
    middle; the rest of a continent stays empty, and the picture says how
    far it reaches.
    The unit answers /network/around?half= at once with the discs it has,
    counts the rest as pending so the page asks again in five seconds, and
    fetches the missing ones in the background one at a tim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
    [network-compare.py]
2026-10-09 App: thousands of network aircraft on the screen are plain dots
    A wide view tiled from the network put over two thousand aircraft on the
    radar, each drawn as its own glowing layer; the simulator's Metal driver
    could not hand that frame over and the app crashed there (2026-10-08,
    16:22, the "quit unexpectedly" dialog the owner found). A phone has no
    such hand-off but would have worked far too hard. Past 500 aircraft on
    the screen, the network's are 2.5 pt dots with no glow or trail, as on
    the panel; the radar's own, the selected and the followed keep their
    glyphs.
2026-10-09 Setup flow: the certificate directory was closed to the setup server; the downgrade is loud now
    The security review of yesterday's work found item 9 inert: tls-cert.sh
    made /etc/stratoscan/tls 0750 root:www-data, the setup server runs as its
    own user, so reading unit.crt failed, the failure was taken for "no
    certificate", the QR link named none and the app quietly went over plain
    http with the admin and WiFi passwords in it. Nobody was exposed (RDU
    never runs the first-run flow; no managed unit exists), but the control
    was a no-op.
    Fixed: the directory is 0755 (the key, unit.pem, stays 0640 root:www-data);
    the installer opens it on a unit built before; tls_fingerprint() returns
    None only fo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
    [setup-server.py]
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2026-10-09 One cache for every radar: the network's aircraft, routes and owners through the relay (#64)
    Each radar asked adsb.lol, adsb.im and adsbdb itself, so those volunteer-run
    services' load was the fleet's size times a radar's questions (performance
    audit 2026-10-09, item 4). The relay now holds one cache for all of them:
    - relay/src/netcache.js: GET /v1/net/disc/<lat>/<lon> serves a 250 nm disc of
    adsb.lol's aircraft on a FIXED world lattice (31 rows, discs 354 nm apart,
    so every radar near the same place asks for the same disc), kept 10 s;
    POST /v1/net/routes (adsb.im's shape, cached per callsign 6 h, no route
    1 h); GET /v1/net/owner/<hex> (adsbdb's shape, a week, unknown too). Only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
    [core-feed.py, heartbeat.py, network-compare.py]
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2026-10-10 Retro case: the retainer slips into the shell, and its screw holes are open notches
    The retainer was drawn at exactly the bore diameter and the first print
    (PETG ring, ASA shell) had to be forced in; 0.4 mm clearance a side now.
    Its M3 holes sat 0.3 mm from the rim and printed as nicks; they are open
    3.4 mm notches, since the screw circle is fixed by the inserts already in
    printed shells. New checks: retainer_clears_bore (fails on the old ring,
    786 mm3), retainer_screws_pass, trim_screws_pass. retainer.stl re-exported.
    [checks.scad, front_trim.stl, retainer.stl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]
2026-10-10 Twin antenna mount covers: the screw heads sit in counterbores
    Both covers (8 mm and 11 mm) get 4.4 mm x 1.5 mm counterbores at their five
    M2 holes, so the cap heads stand 0.5 mm proud instead of 2 mm. The bore
    opens on the print plate and its roof is a 1 mm ring, an easy bridge. New
    checks twin_cover_heads_seat(_11); both cover STLs re-exported.
    [antenna_mount_twin_cover_11.stl, antenna_mount_twin_cover_8.stl, checks.scad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]
2026-10-10 Twin antenna mount covers: the frequencies can print in a second colour
    The engraved lettering is its own part (ant_twin_label_solid, exported as
    antenna_mount_twin_cover_text_8/_11), exactly filling the engraving, and
    make-cover-3mf.py builds a two-colour project per cover with the cover on
    filament 1 and the letters on filament 2, so a slicer does not split them
    into a part per letter. Checks: the lettering never overlaps the cover and
    lies inside its outline; twin_cover_text_present is its positive control.
    [antenna_mount_twin_cover_11.stl, antenna_mount_twin_cover_11_twotone.3mf, antenna_mount_twin_cover_8.stl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]
2026-10-10 Kitten case: the same retainer clearance and twin cover changes as the retro
    The two cases share their retainer and twin antenna mount cover
    (tests/test_enclosure_core.py), and the last three fixes went into the retro
    only: 0.4 mm retainer clearance with open M3 notches, counterbored cover
    screws, and the lettering as its own part with two-colour projects.
    [antenna_mount_twin_cover_11.stl, antenna_mount_twin_cover_11_twotone.3mf, antenna_mount_twin_cover_8.stl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]
2026-10-10 The panel goes dark again: an alert lights it for two minutes, not twenty
    Every alert restarted the screensaver for a fresh 20 minutes, and the radar
    alerts every few minutes in the day, so the panel never blanked (168 wakes
    in one day). Now an alert wakes a dark panel for ALERT_HOLD_S (120 s) unless
    someone touches it; an alert while the panel is lit changes nothing; and
    "never seen here before" no longer wakes it. Wakes that are not alerts (the
    updater checking its paint) keep the full idle time.
    [wake-listener.py]
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2026-10-10 Back plate: a pocket in the outer face for the USB-C connector's boss
    The panel-mount connector's 22.25 x 11 mm boss mounts from inside, and
    through the full 3 mm plate its socket sat too far below the outer face
    for a plug to seat (the owner, 2026-10-10). A 2 mm pocket the boss's size
    leaves a 1 mm web; the screw heads sit in it. Both cases (shared plate);
    checks usbc_recess_open and usbc_recess_web; back_plate.stl re-exported.
    [back_plate.stl, checks.scad, kitten-enclosure-twotone.scad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]
2026-10-10 Back plate: the USB-C socket moves to the bottom centre, between the grilles
    At [60, -14] it sat beside the Pi's USB ports and the power jumper bent hard
    against them (the owner, 2026-10-10). Now at [0, -41], in the band between
    the intake grille and the fan grille, so the jumper runs straight up. Both
    cases (shared plate); usbc_plug_clears_stand proves a plug there clears the
    stand with the case leaning back; back_plate.stl re-exported.
    [back_plate.stl, checks.scad, kitten-enclosure-twotone.scad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]
2026-10-10 Back plate: the USB-C socket 37 mm below its original spot, [60, -51]
    The bottom centre did not suit either (the owner, 2026-10-10). Both cases;
    checks pass; back_plate.stl re-exported.
    [back_plate.stl, checks.scad, kitten-enclosure-twotone.scad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]
2026-10-10 Watchdog: pause the 978 decoder when the power supply starts dipping fast
    The 978 radio running full-time browned RDU out on 2026-10-10 (#53, #24).
    The watchdog now counts the kernel's under-voltage dips: 4 or more in 10
    minutes stops stratoscan-uat (never disables it); it starts again once the
    supply has had at most one dip in 30 minutes, after a wait that doubles
    with each pause (30 min, 1 h, ... 6 h; reset at boot). A decoder its owner
    disabled is never touched. Decisions are logged as "power: ...".
    [net-watchdog.py]
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

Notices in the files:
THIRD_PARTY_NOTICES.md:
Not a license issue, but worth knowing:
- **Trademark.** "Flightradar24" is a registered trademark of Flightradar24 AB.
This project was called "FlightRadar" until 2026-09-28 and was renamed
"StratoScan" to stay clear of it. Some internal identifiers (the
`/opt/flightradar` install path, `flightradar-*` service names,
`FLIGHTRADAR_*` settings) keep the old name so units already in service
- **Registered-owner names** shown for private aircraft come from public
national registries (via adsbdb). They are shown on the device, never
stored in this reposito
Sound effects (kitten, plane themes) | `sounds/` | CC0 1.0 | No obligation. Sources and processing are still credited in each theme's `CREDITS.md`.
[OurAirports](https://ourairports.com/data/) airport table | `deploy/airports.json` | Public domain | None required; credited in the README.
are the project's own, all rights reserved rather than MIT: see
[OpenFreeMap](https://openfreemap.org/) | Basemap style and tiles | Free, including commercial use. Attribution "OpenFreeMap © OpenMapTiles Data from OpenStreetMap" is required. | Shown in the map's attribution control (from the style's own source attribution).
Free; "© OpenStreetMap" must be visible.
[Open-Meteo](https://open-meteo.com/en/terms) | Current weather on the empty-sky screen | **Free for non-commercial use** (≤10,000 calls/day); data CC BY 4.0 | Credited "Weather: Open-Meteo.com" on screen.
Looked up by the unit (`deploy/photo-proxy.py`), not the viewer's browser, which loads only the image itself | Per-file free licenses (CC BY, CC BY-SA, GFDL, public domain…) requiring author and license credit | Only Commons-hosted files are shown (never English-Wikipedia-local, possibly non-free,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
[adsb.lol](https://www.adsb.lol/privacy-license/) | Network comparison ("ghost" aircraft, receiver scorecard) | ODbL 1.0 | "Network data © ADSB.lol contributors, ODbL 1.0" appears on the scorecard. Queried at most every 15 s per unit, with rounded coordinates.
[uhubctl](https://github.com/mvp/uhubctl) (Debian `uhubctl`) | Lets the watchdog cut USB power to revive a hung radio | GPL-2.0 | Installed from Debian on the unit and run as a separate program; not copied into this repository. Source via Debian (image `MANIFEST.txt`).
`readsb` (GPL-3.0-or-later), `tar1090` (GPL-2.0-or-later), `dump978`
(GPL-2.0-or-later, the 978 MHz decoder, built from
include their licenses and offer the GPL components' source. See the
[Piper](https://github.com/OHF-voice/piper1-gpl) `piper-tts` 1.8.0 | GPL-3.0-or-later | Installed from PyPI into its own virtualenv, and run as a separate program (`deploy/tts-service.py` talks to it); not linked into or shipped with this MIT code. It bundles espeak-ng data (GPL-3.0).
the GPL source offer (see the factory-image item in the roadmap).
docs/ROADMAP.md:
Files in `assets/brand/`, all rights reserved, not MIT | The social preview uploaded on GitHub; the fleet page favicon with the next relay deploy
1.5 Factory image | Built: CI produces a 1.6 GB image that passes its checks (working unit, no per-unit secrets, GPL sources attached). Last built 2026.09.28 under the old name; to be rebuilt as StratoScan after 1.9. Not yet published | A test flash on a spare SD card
